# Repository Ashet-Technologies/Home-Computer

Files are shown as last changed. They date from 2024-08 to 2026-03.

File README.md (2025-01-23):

# Ashet Home Computer Mk4

### _The 21st century home computer_

| Project Status                                                                                       |
|------------------------------------------------------------------------------------------------------|
| ⚠️ **WORK IN PROGRESS** ⚠️                                                                             |
| This README reflects the state of where the project wants to go, not where the project is right now! |

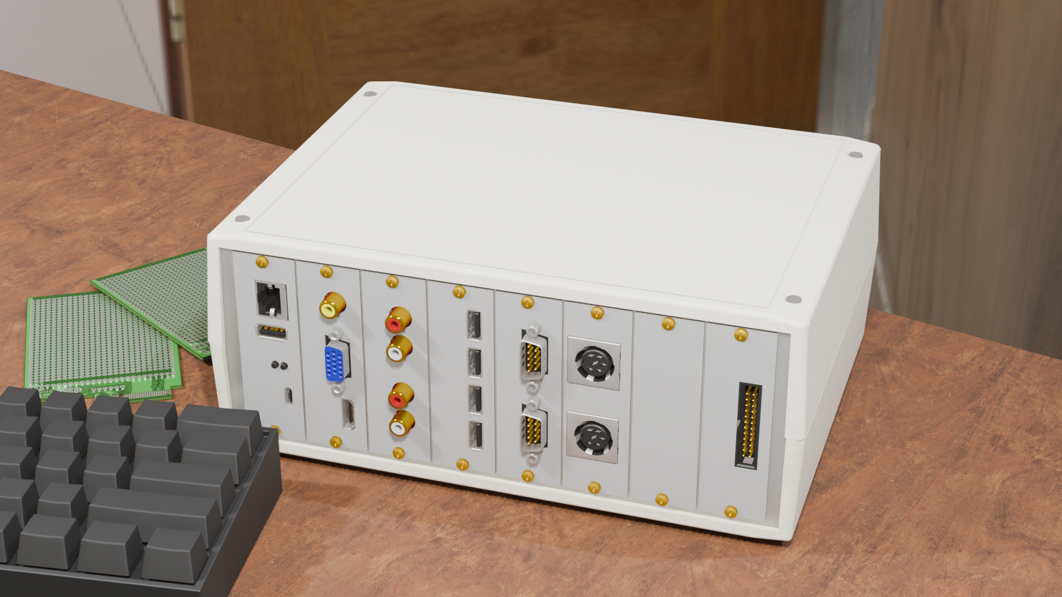
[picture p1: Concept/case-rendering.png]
A rendering of a concept art


## Introduction

The Ashet Home Computer bridges the gap between simple microcontroller development boards and modern single-board computers, offering the processing capability to run a full graphical desktop OS while maintaining the hardware accessibility of simpler systems.

Built around the RP2350 dual-core processor, it combines sufficient computational power for a modern user interface with a transparent, education-oriented architecture. The modular expansion system, inspired by classic computer designs, allows direct hardware access while providing proper driver abstractions for portability.

Key differentiators:

- Runs [Ashet OS](https://github.com/Ashet-Technologies/Ashet-OS): A custom desktop operating system with modern GUI capabilities
- Fully documented hardware architecture with direct register access
- Modular expansion through 7 dedicated slots, including specialized video/audio interfaces
- 8 MB RAM and 16 MB Flash supporting both low-level and high-level development
- Comprehensive I/O capabilities suitable for real-time interfacing, creative projects, and systems development

The system is designed for accessibility across different skill levels - from students learning computer architecture to makers building custom hardware interfaces, and from demosceners pushing hardware limits to educators teaching system design.

## Features

The computer follows a modular design similar to a PC where you have expansion cards that you can plug into the system.

### Core Features

These features are available no matter what expansion cards you have installed.

- RP2350 Core
  - Dual-Core System
  - Each Core Might Be
    - Arm CPU (Cortex-M33, 150 MHz)
    - RISC-V CPU (RV32IMAC+, 150 MHz)
- 8 MB RAM
- 16 MB Flash
- USB 1.1 Host
- 10/100 Mbps Ethernet
- Battery-Backed Real-Time Clock
- Status Display (128x64, monochrome)
- Integrated Debug Probe
- 7 Expansion Slots
  - 1 Video Expansion Slot
  - 1 Audio Expansion Slot
  - 5 Generic Expansion Slots

### Standard Expansions

The following expansion cards are the designated expansion cards which make up the Ashet Home Computer as designed:

1. [Framebuffer Video Card](Hardware/Expansions/Framebuffer%20Video/README.md)
    - DVI Video Out (800x480, 60 Hz)
2. [PCM Sound Card](Hardware/Expansions/PCM%20Sound/README.md)
    - PCM Audio Out (48 kHz, 16 bit)
    - PCM Audio In (48 kHz, 16 bit)
3. [USB Card](Hardware/Expansions/USB/README.md)
    - 4 USB 1.1 Host Ports
4. [RS232 Card](Hardware/Expansions/RS232/README.md)
    - TTL UART (3.3V, 5V, ±12V)
5. [Basic I/O Card](Hardware/Expansions/Basic%20IO/README.md)
    - Pin Header Connector
    - 8 GPIOs
    - Dedicated I²C
    - 5 V and 3.3 V power supply available
6. [Commodore Connectivity Card](Hardware/Expansions/Commodore%20Connectivity/README.md)
    - 2× C64 Serial
7. [User Expansion Card](Hardware/Expansions/User%20Expansion/README.md)
    - Minimal Expansion Card
    - Perfboard For Custom Expansions
    - Pin Header Connector

### Other Expansions

There are many more ideas that can be realized with expansion cards.

Take a peek at our [List of Expansion Board Ideas](Concept/Expansion%20Boards.md) or check out the [Expansion Card Interface Specification](Specs/Expansion%20Bus.md) how to create your own.

## Use Cases

This chapter contains a list of things you can do with the computer, ordered loosely by user groups.

### Demosceners

Make a demo, I guess?

With a good audio and video expansion card, and two strong multi-core CPUs the computer packs enough power to create awesome visuals and sound effects.

### Retro-Enthusiasts

The computer is able to emulate a lot of existing machines with fitting I/O connectivity. The backplane is able to emulate a lot of different protocols with cheap passive expansion modules.

It also is able to create a multitude of video signals, analog and digital with 15 or 30 kHz line frequency. Another option is to have more complex expansion cards which can drive storage interfaces like [Shugart bus](https://en.wikipedia.org/wiki/Floppy_disk_drive_interface), [MFM disks](https://en.wikipedia.org/wiki/Modified_frequency_modulation), ATA and IDE…

### Artists / Musicians

The Ashet can be used as a cheap real-time sequencing controller which can handle a good amount of interfaces. With support for MIDI, DMX, analog audio channels and ethernet, it's possible to create complex audio setups. Another option is creating or using expansion cards that provide access to old-school synthesizers like the [AY-3-8910](https://en.wikipedia.org/wiki/General_Instrument_AY-3-8910) or the [SID](https://en.wikipedia.org/wiki/MOS_Technology_6581).

### Hackers / Makers

With the Propeller 2 on the backplane, one can basically emulate any digital interface like SPI or I²C. With a breakout I/O expansion card, it can be used for controlling your own hardware, accessing and changing SPI flashes, ...

It is also possible to use the Ashet as a basic logic analyzer and scope, as well as a signal and waveform generator. With a bigger I/O card, it can be expanded to 32 synchronously processed channels.

By utilizing a scripting language on Ashet OS, one should be able to easily access and bootstrap newly acquired hardware.

### Educators

The project provides extensive documentation, from decision making over the schematic up to the software architecture, so it can be used as an example on how to design a complete computer system.

The machine also looks more like a "real computer" than a Raspberry Pi or other modern single-board computers, so it is more tangible for persons that do not have experience with electronics and might give an easier start.

### Students

The computer provides a good hands-on experience and allows both creating or understanding hardware and software designs and how they play together. The system is also easily expansible and thus allows creating custom hardware modules. The available documentation allows learning basically everything about the computer that is possible to know.

## Comparison with Similar Projects

The following table shows a comparison to other "small" computers. It should help you get an idea where the Ashet Home Computer is in relation to other projects.

| Feature | Ashet | [Raspberry Pi 4](https://www.raspberrypi.com/products/raspberry-pi-4-model-b/specifications/) | [Arduino Uno REV3](https://store.arduino.cc/products/arduino-uno-rev3) | [Neotron Pico](https://github.com/neotron-Compute/neotron-Pico) | [Cody Computer](https://www.codycomputer.org/) |
|---|---|---|---|---|---|
| CPU Architecture | Arm Cortex-M33 (32 bit) | Arm Cortex-A72 (64 bit) | ATmega328p (8 bit) | Arm Cortex-M0+ (32 bit) | 6502 |
| CPU Model | [Rapsberry Pi RP2350](https://www.raspberrypi.com/products/rp2350/) | [Broadcom BCM2711](https://www.raspberrypi.com/documentation/computers/processors.html#bcm2711) | [ATmega328P](https://www.microchip.com/en-us/product/atmega328p) | [Rapsberry Pi RP2040](https://www.raspberrypi.com/products/rp2040/) | [W65C02S](https://wdc65xx.com/integrated-circuit) |
| CPU Cores | 2 | 4 | 1 | 2 | 1 |
| CPU Clock | 150 MHz | 1.8 GHz | 16 MHz | 133 MHz | 1 MHz |
| System Memory | 8 MB | 1, 2, 4 or 8 GB | 2 KB | 264 kB | 64 kB |
| Understandable | ✅ | ❌ | ✅ | ✅ | ✅ |
| Modern I/O | ✅ | ✅ | ❌ | ❌¹ | ❌ |
| Modular Design | ✅ | ❌ | ❌ | ✅ | ✅² |
| Full Documentation Available | ✅ | ❌ | ✅ | ✅ | ✅ |
| Ethernet | ✅ | ✅ | ❌ | ❌ | ❌ |
| Parallax Propeller I/O Chip  | ✅ ([Propeller 2](https://www.parallax.com/propeller-2)) | ❌ | ❌ | ❌ | ✅ ([Propeller 1](https://www.parallax.com/propeller-1)) |

¹Neotron Pico uses PS/2 for mouse/keyboard and VGA for video.

²Cody Computer has a single cartridge that can be added.

## Architecture

### Block Diagram

Block Diagram

## Glossary

<dl>
  <dt>Mainboard</dt>
  <dd>The Mainboard houses the cpu core and everything necessary to run the system, even without <em>Expansion Boards</em> or the <em>Backplane</em>.</dd>

  <dt>Backplane</dt>
  <dd>The Backplane is the interconnect between the <em>Mainboard</em> and <em>Expansion Boards</em>. This board also contains the <em>I/O Southbridge</em></dd>

  <dt>Expansion Board</dt>
  <dd>Expansion Boards provide more capabilities to the computer. They usually add more I/O features, but could also house any other kind of electronics that want to interface with the <em>Mainboard</em>.</dd>

  <dt>Video Expansion Board</dt>
  <dd>A Video Expansion Board is a special expansion that is only installable in a single socket of the <em>Backplane</em>. In addition to the generic <em>Expansion Board</em> interface, it has an additional 8 lanes of high-speed interconnect to the <em>Mainboard</em>.</dd>

  <dt>Audio Expansion</dt>
  <dd>An Audio Expansion Board is a special expansion that is only installable in a single socket of the <em>Backplane</em>. In addition to the generic <em>Expansion Board</em> interface, it has an additional 2-lane I²S interconnect to the <em>Mainboard</em>.</dd>

  <dt>I/O Southbridge</dt>
  <dd>The I/O Southbridge provides the main interconnect between the <em>Main Board</em> and the <em>Expansion Boards</em>. It is realized by a <a href="https://www.parallax.com/propeller-2/">Propeller 2</a>.</dd>
</dl>

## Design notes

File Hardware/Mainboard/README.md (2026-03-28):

# Ashet Home Computer Mainboard

## Overview

- RP2350B as main CPU
- RP2350B as a debug probe
- Two 16 MiB flash chips
- 12 MHz Crystal for debug probe
- 4-port USB 1.1 HUB
- 10/100 Base-T/TX ethernet through ENC424J600
- 8 MB PSRAM (APS6404L-SQH-SN)
- 1.8V LDO for QSPI_IOVDD / PSRAM / Flash Chips

## Design Notes

- Attach debug probe to global I²S bus for both sniffing and controlling the system
- Debug probe must be able to reset the main CPU
- Debug probe can additionally drive global CLOCK_48MHZ so we can run the mainboard standalone without backplane
- Drive main CPU from CLOCK_48MHZ
- Drive debug probe through dedicated crystal
- Evaluate if debug probe can trigger the main cpu "boot over serial"
- Attach debug probe to main cpu flash directly
- Main CPU cannot be programmed through USB/UF2, but only through the debug probe
  - This must be as convenient as possible

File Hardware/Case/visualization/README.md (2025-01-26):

# Visualization Rendering

This case contains the nice "preview" renderings of the device.

## Utilities

- <https://github.com/30350n/pcb2blender>
- <https://extensions.blender.org/add-ons/pcb3d-importer>

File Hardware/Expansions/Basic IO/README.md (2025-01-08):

# Basic I/O Expansion

This expansion board just forwards the expansion connector to a 0.1" pin header.

## Pinout

The I/O card has a 0.1" pin header connector with 12x2 pins on the frontplate with the following pinout:

| Column | Top | Bottom  |
|---|---|---|
| 1 (left) | 5V | GND |
| 2 | 3V3 | GND |
| 3 | I2C_SCL | I2C_SDA |
| 4 | GP0 | GND |
| 5 | GP1 | GND |
| 6 | GP2 | GND |
| 7 | GP3 | GND |
| 8 | GP4 | GND |
| 9 | GP5 | GND |
| 10 | GP6 | GND |
| 11 | GP7 | GND |
| 12 (right) | GND | GND |

## Parts

| Function | Manufacturer | Part Number | Distributors |
|---|---|---|---|
| 0.1" Connector with 12x2 | On Shore Technology Inc. | 302-R241 | [DigiKey](https://www.digikey.de/de/products/detail/on-shore-technology-inc/302-R241/2794248) |

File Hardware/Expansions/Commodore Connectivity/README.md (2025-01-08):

# Commodore Connectivity Expansion

The Commodore Connectivity Expansion provides two [C64 Serial](https://www.c64-wiki.com/wiki/Serial_Port) compatible DIN connectors.

Each connector is it's own dedicated bus and they are not connected internally. This way two devices can be operated independently from each other.

## Pinout

The pinout of the two DIN connectors is the same as on the C64 or other compatible devices:

| Pin | Name | Signal direction | Remark |
|-----|---|---|---|
| 1 | SERIAL SRQ | in | Serial Service Request In, at the C128 "Fast Serial Clock" |
| 2 | GND | - | Ground, signal ground (0V) |
| 3 | SERIAL ATN | out | Attention, for the selection of a device at beginning/end of a transmission |
| 4 | SERIAL CLK | in/out | Clock (for data transmission) |
| 5 | SERIAL DATA  | in/out | Data |
| 6 | SERIAL RESET | out(/in) | Reset, in older VIC-20 unused |

## Parts

| Function | Manufacturer | Part Number | Distributors |
|---|---|---|---|
| DIN 45322 Connector | CLIFF Electronic Components Ltd | FM6726 | [DigiKey](https://www.digikey.de/de/products/detail/cliff-electronic-components-ltd/FM6726/21676225) |
| 16 bit I/O Expander | Microchip Technology | MCP23S17T-E/SO | [DigiKey](https://www.digikey.de/de/products/detail/microchip-technology/MCP23S17T-E-SO/964187) |

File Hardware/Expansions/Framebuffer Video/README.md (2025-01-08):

# Framebuffer Video Expansion

The Framebuffer Video Expansion is the most simple video expansion.
It only provides a single DVI-compatible connector connected to the Mainboard.

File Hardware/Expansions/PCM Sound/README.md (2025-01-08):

# PCM Sound Expansion

The PCM Sound Expansion provides both a stereo audio input as well as a stereo output on a Cinch/RCA connector.

Both the input and the output support at least 16 bit audio with 48 kHz sampling frequency and DC free audio output.

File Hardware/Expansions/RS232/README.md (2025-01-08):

# RS232 Expansion

The RS232 expansion provides two fully equipped [RS232](https://en.wikipedia.org/wiki/RS-232) ports.

Each port has the serial lanes as well as all control signals available.

## Pinout

The pinout of the two SUB DE 9 connectors follow the RS232 standard:

| Pin | Name | Signal direction | Remark |
|-----|---|---|---|
| 1 | DCD  | in | (Data) Carrier Detect |
| 2 | RXD  | in | Receive Data |
| 3 | TXD  | out | Transmit Data |
| 4 | DTR  | out | Data Terminal Ready |
| 5 | GND  | - | Signal Ground |
| 6 | DSR  | in | Data Set Ready |
| 7 | RTS  | out | Request To Send |
| 8 | CTS  | in | Clear To Send |
| 9 | RI | in | Ring Indicator |

## Parts

| Function | Manufacturer | Part Number | Distributors |
|---|---|---|---|
| RS232 Transceiver | Texas Instruments | MAX3243EIPWR | [DigiKey](https://www.digikey.de/de/products/detail/texas-instruments/MAX3243EIPWR/1120503) |
| 16 bit I/O Expander | Microchip Technology | MCP23S17T-E/SO | [DigiKey](https://www.digikey.de/de/products/detail/microchip-technology/MCP23S17T-E-SO/964187) |
| SUB DE 9 Male Connector | Assmann WSW Components | A-DS 09 A/KG-T4S | [DigiKey](https://www.digikey.de/de/products/detail/assmann-wsw-components/A-DS-09-A-KG-T4S/1241806) |

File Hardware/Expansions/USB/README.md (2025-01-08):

# USB Expansion

The USB Expansion provides 4 USB 1.1 ports to the computer which are attached to the backplane.

## Pinout

| Pin | Name | Signal direction | Remark |
|-----|---|---|---|
| 1 | GND  | - | Signal ground |
| 2 | D+ | in/out | Positive data lane |
| 3 | D- | in/out | Negative data lane |
| 4 | VBUS | - | 5V |

## Parts

| Function | Manufacturer | Part Number | Distributors |
|---|---|---|---|
| USB-A Connector | Cvilux USA | CU01SAH0S00 | [DigiKey](https://www.digikey.de/de/products/detail/cvilux-usa/CU01SAH0S00/13177442) |

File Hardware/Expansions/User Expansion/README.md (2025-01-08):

# User Expansion

This expansion card allows one to create their own expansions.

It contains all necessary parts like the connector and the metadata EEPROM, but apart from that, it just exposes all signals onto a perfboard.

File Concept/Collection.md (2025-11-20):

# Link Collection

## Parts

- [RP2350 Stamp XL](https://www.lectronz.com/products/rp2350-stamp-xl) ([Documentation](https://www.solder.party/docs/rp2350-stamp-xl/))
- [ENC624J600](https://www.microchip.com/en-us/product/enc624j600)
- [ESP32-C3](https://www.espressif.com/en/products/socs/esp32-c3)
- [FT232H](https://ftdichip.com/products/ft232hq/)
- [Parallax Propeller 2](https://www.parallax.com/propeller-2/)
- [XS3A2467PWJ](https://www.digikey.de/de/products/detail/nexperia-usa-inc/XS3A2467PWJ/16186760) (Dual low-ohmic double-pole double-throw analog switch)

## Prototyping

### Debugger

- [https://ftdichip.com/products/ft232hq/]
- [BlackMagic Probe](https://github.com/koendv/blackmagic-firmware/blob/master/INSTALL.md)
- [RaspberryPi Debug Probe](https://www.raspberrypi.com/products/debug-probe/)

### Devboards

- [RaspberryPi Pico 2](https://www.raspberrypi.com/products/raspberry-pi-pico-2/)
- [MOD-ENC624J600](https://www.olimex.com/Products/Modules/Ethernet/MOD-ENC624J600/)
- [ESP32-C3 Zero](https://www.waveshare.com/esp32-c3-zero.htm)
- [FT232H](https://www.adafruit.com/product/2264)

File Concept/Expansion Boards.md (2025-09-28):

# List of Expansion Board Ideas

## Near Future

- WiFi via ESP32-C3
- 32 Channel I/O via Propeller 2
- PropGPU (Propeller 2 based GPU with 4-16 MB video ram, HDMI, VGA, CVBS)
- SuperSound (I²S PCM + AY-3-8910 + Analog Mixer)
- Dual C64 Serial
- Quad-Channel D-Bus-Controller (TI Calculator Link)
- SD Card Expansion (USB2244-AEZG-06)
- 100BASE-T1 (https://www.mouser.de/datasheet/2/268/LAN8770_Product_Brief_DS00002550C-3071247.pdf)

## Far Future

- Quad-Channel DMX
- Dual-Channel MIDI
- Parallel Port
- Retro Joystick (SUB-D 9, C64, Atari, ...)
- VLSI Video Card (<https://www.vlsi.fi/en/products/vs23s040.html>)
- VLSI Audio Card (<https://www.vlsi.fi/en/products/vs1053.html>)
- RaspberryPi Compute Module carrier ("SuperCPU")

## Community

- Analog Video Capture Card
- GPIB
- Ethernet with BNC
- Tokenring
- MFM Disk
- PS/2
- Commodore Datasette
- [Shugart Bus](https://en.wikipedia.org/wiki/Floppy_disk_drive_interface) Floppy Driver
- TOSLINK for Communications Network
- Wireless Multi-Channel Device (LoRa, Bluetooth, Matter, ...)
- EtherCAT
- Sercos III
- [CAN FD](https://en.wikipedia.org/wiki/CAN_FD)
- [IO Link](https://en.wikipedia.org/wiki/IO-Link)
- [HART](https://en.wikipedia.org/wiki/Highway_Addressable_Remote_Transducer_Protocol)

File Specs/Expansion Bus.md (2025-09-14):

# Ashet Expansion Bus

The Ashet *Expansion Bus* is the core component of the composability of the Ashet Home Computer.

## Overview

- Hot Swappable
- Power Supply
  - 12V, (up to) 2A
  - 5V, (up to) 1A
  - 3.3V, (up to) 1A
  - Overcurrent Protection
- Standard Mode I²C Bus
- 8 Programmable I/O Pins
- 8 High Speed Lanes (up to 300 MHz)
- Dual-Stream I²S Bus

## Optional Features

The Expansion Bus has several *optional* features that must not be present on each slot.

Each feature might require a certain set of signals to be present:

| Feature  | Standard Signals | Video Signals | Audio Signals |
| --- | --- | --- | --- |
| Standard | ✅ | ❌ | ❌ |
| Audio | ✅ | ❌ | ✅ |
| Video | ✅ | ✅ | ❌ |

## Signals

| Signal Name | Driver | Type | Function | Frequency Limit |
| --- | --- | --- | --- | --- |
| *All Variants* | | | | |
| `GND` | Backplane | Power | Signal Ground | |
| `+3V3` | Backplane | Power | 3.3 V power supply | |
| `+5V` | Backplane | Power | 5 V power supply | |
| `+12V` | Backplane | Power | 12 V power supply | |
| `/PDET` | Card | Static | Presence detection. Must be tied to ground on the expansion card | |
| `SLOT_A0`...`SLOT_A3` | Backplane | Static | Module slot index, bits 0 to 3 | |
| `/SLOT_AUDIO` | Backplane | Static | This signal is connected to GND if the slot has the *Audio* feature available | |
| `/SLOT_VIDEO` | Backplane | Static | This signal is connected to GND if the slot has the *Video* feature available | |
| `/IRQ` | Card | Open Collector | Interrupt request. Card drives this to low for system notification | |
| `/RESET` | Backplane | Logic | Reset signal. Is driven low when the card should reset itself | |
| `CLK` | Backplane | Logic | Global 8 MHz clock for synchronization | 8 MHz |
| `I2C_SCL` | Bi-di | Open Collector | Clock Lane of the System I²C Bus | 100 kHz |
| `I2C_SDA` | Bi-di | Open Collector | Data Lane of the System I²C Bus | 100 kHz |
| `GP0`...`GP7` | Bi-di | Logic or Analog | General-purpose I/O signals from the Southbridge | 150 MHz |
| *Video Signals* | | | | |
| `HSTX0`...`HSTX7` | Backplane | Logic or Differential | Unidirectional high-speed lanes. Even/odd pairs for a differential pair | 300 MHz |
| *Audio Signals* | | | | |
| `I2S_MCLK` | Backplane | Logic | Master clock of both I²S streams | 25 MHz |
| `I2S_BCLK` | Backplane | Logic | Bit clock of both I²S streams | 6.5 MHz |
| `I2S_WCLK` | Backplane | Logic | Word clock of both I²S streams | 192 kHz |
| `I2S_SDIN` | Card | Logic | Data lane of the I²S input stream | 6.5 MHz |
| `I2S_SDOUT` | Backplane | Logic | Data lane of the I²S output stream | 6.5 MHz |

All signals that are not power signals will use nominal voltage levels between 0.0V and 3.3V.

### Power

> TO BE DONE

### I²C

The I²C bus uses standard speed I²C and must have at least a standard EEPROM connected.

This EEPROM must have at an 8-bit memory organization with at least 8K of memory. It contains the *Module Descriptor Data* described further below.

The following addresses are reserved on the bus in addition to the specification:

| Address | Use |
| ---: | --- |
| 0x57 | Metadata EEPROM |
| 0x70 | Backplane I²C Switch |

All other addresses on the I²C bus are available to the expansion card and will not be occupied by the host system.

> **LORE:**
> The *Metadata EEPROM* uses the address `0x57` instead of `0x50`, as `0x50` is the default for EEPROMs and these might already be taken by other
> EEPROM systems like the [DDC](https://en.wikipedia.org/wiki/Display_Data_Channel) [EDID](https://en.wikipedia.org/wiki/Extended_Display_Identification_Data) EEPROM.

### General Purpose I/O

These signals will have a card-specific function and are driven by either the card or the southbridge on the backplane.

They can be either logic signals or analog signals, as long as they stay in the nominal voltage range.

Each expansion card will have to ship a low level driver which provides the southbridge configuration for these I/Os. See *Module Descriptor Data* for more information.

### I²S

The I²S bus has two audio streams on the signals `I2S_SDIN` and `I2S_SDOUT`.

`I2S_SDOUT` contains the left and right channel data of a stereo audio output, while `I2S_SDIN` contains the left and right channel data of a stereo capturing device.

The clock signals are shared for both audio streams and are always driven by the host system. This means that the sample rate is defined by the host and cannot be set by the card itself.

Cards that need to be in control of their sample rate might need to do audio resampling or use the *General Purpose I/O* signals.

It is only available on slots with the *Audio* signal set.

### High Speed Lanes

> TO BE DONE

The high speed lanes are only available on slots with the *Video* signal set.

## Connector

### Mechanical

The *Expansion Bus* uses a standard *PCI Express x4* connector with 64 positions.

### Pinout

|  Pin | A Side | B Side |
| ---: | --- | --- |
| 1 | GND | GND |
| 2 | +3V3 | +12V |
| 3 | +3V3 | +12V |
| 4 | GND | +12V |
| 5 | SLOT_A0 | +12V |
| 6 | SLOT_A1 | +5V |
| 7 | SLOT_A2 | +5V |
| 8 | SLOT_A3 | GND |
| 9 | I2C_SCL | /PDET |
| 10 | I2C_SDA | /SLOT_AUDIO |
| 11 | /IRQ | /SLOT_VIDEO |
|  Key | - | - |
| 12 | GND | GND |
| 13 | CLK | HSTX0 |
| 14 | GND | HSTX1 |
| 15 | GP0 | GND |
| 16 | GP1 | HSTX2 |
| 17 | GP2 | HSTX3 |
| 18 | GP3 | GND |
| 19 | GP4 | HSTX4 |
| 20 | GP5 | HSTX5 |
| 21 | GP6 | GND |
| 22 | GP7 | HSTX6 |
| 23 | *reserved* | HSTX7 |
| 24 | *reserved* | GND |
| 25 | *reserved* | I2S_MCLK |
| 26 | *reserved* | GND |
| 27 | *reserved* | I2S_BCLK |
| 28 | *reserved* | I2S_WCLK |
| 29 | *reserved* | GND |
| 30 | *reserved* | I2S_SDIN |
| 31 | /RESET | I2S_SDOUT |
| 32 | GND | GND |

## Module Descriptor Data

The Module Descriptor Data describes the expansion card and provides a low-level driver for the southbridge.

### Memory Map

The data is located at the start of the EEPROM and follows the following memory layout:

| Address Range  | Function |
| --- | --- |
| `0000`..`01FF` | Metadata Block |
| `0200`..`07FF` | *reserved* |
| `0800`..`0FFF` | Module Card Icon |
| `1000`..`1FFF` | Low Level Driver Binary |

### Metadata Block

The metadata block encodes generic information about the expansion card that can be processed by the host system.

| Offset | Field | Type | Function |
| --- | --- | --- | --- |
| `0000` | Vendor ID | `u32` | Unique ID for the vendor of the expansion card |
| `0004` | Product ID | `u32` | Vendor-unique ID for the expansion card |
| `0008` | Serial Number | `[8]u8`  | Serial number of the expansion card. Can be zero-padded |
| `0018` | | | *padding* |
| `0020` | Required Features | `u8` | Bitmask of which expansion slot features are required |
| `0021` | | | *padding* |
| `0024` | Driver Interface  | `u32` | Type of driver interface this expansion card uses |
| `0028` | | | *padding* |
| `0030` | Driver Specific | `[16]u8` | |
| `0040` | | | *padding* |
| `0100` | Vendor Name | `[64]u8` | UTF-8 encoded vendor name |
| `0140` | Product Name | `[64]u8` | UTF-8 encoded product name |
| `0180` | | | *padding* |

### Module Card Icon

Each module card may embed an icon so a host os can show the user a nice visual representation.

As the resolution of the host system is not known, up to three icon sizes can be embedded:

- 16x16
- 24x24
- 32x32

All icons share the same color palette, which can have up to 63 colors and a transparency key.

The icon memory block is organized as such:

| Address Range  | Function |
| --- | --- |
| `0000`..`00FF` | 8-bit pixel data for 16x16 icon |
| `0100`..`04FF` | 8-bit pixel data for 32x32 icon |
| `0500`..`0BFF` | 8-bit pixel data for 24x24 icon |
| `0740` | 16x16 icon Configuration Field |
| `0741` | 32x32 icon Configuration Field |
| `0742` | 24x24 icon Configuration Field |
| `0743`..`07FF` | 63-entry palette with \[R,G,B] color values |

Each *Configuration Field* is a bit field with the following items:

|  Bit | Function |
| ---: | --- |
| 0..5 | Number of palette entries. Zero means icon is disabled |
| 6..7 | *reserved, must be zero* |

An icon is present if it has more than zero colors in its palette.

The pixel data contains row-major organized indices into the palette using 0...62 as defined by the palette table, and 63 as the transparency key. On load, the uppermost two bits may be discarded, truncating the 8-bit index to 6 bits.

### Low Level Driver

The low level driver is a Propeller 2 binary which is loaded into one of the cogs of the southbridge.

> TO BE DONE

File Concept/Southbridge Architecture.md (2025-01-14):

# Southbridge Architecture

## tl;dr

- Propeller2 based
- Support for 7 expansion slots
  - 1 cog per slot
  - 64k RAM per slot
- 1 cog upstream
- 64k management ram + code

## Interface

### Physical

> TBD

### Electrical

| Interface Pin | Propeller Pin | Name | Direction  | Idle State | Function | Alt. Function |
| ---: | --- | --- | --- | --- | --- | --- |
| 1 | 53 | D0 | Bi-di | Don't care | Data bit, L=0, H=1 | - |
| 2 | 57 | D1 | Bi-di | Don't care | Data bit, L=0, H=1 | - |
| 3 | 58 | D2 | Bi-di | Don't care | Data bit, L=0, H=1 | - |
| 4 | 59 | D3 | Bi-di | Don't care | Data bit, L=0, H=1 | Forced HIGH |
| 5 | 60 | CLK | Bi-di | High | The bit clock for D0, D1, D2, D3. Shift in on rising edge | *don't care*  |
| 6 | 61 | EN | Downstream | Low | Determines if a transfer is active. On a rising edge, a new transfer is started | *don't care*  |
| 7 | 62 | DIR | Downstream | Low | The direction of a transfer. H means towards Downstream, L is towards Upstream | Boot RX |
| 8 | 63 | /REQ | Upstream | High | A falling edge will signal the upstream that an event happened and data is ready to be read | Boot TX |
| 9 | RESn | /RESET | Downstream | High | Resets the southbridge into initial state | |

Upstream: Southbridge to Host CPU

Downstream: Host CPU to Southbridge

### Logical

The protocol is transfer-oriented with each transfer being made of a sequence of octets.

A transfer is initiated by the upstream setting `DIR` to the desired state, then pulling the `EN` pin to high. The rising edge is detected on the downstream which then samples the `DIR` pin.

Depending on `DIR`, either a *write* or a *read* operation is performed. For *write* operations, the upstream is the driver for `CLK` and the data pins, on a *read* operation, the downstream drives these signals.

After the transfer setup has been done, pairs of nibbles are transferred. For each nibble, the sender will set up the data pins and pull `CLK` low, afterwards pulling `CLK` high.
The data must sampled by the receiver on the rising edge of the `CLK` signal. The first transferred nibble contains the upper 4 bit of the octet, the second one contanis the lower 4 bit.

A transfer is completed on a falling edge of `EN`. `DIR` should remain constant throughout the transfer, but only the state after the rising edge of `EN` defines the transfer direction.

The `/REQ` signal shall be pulled low by the downstream as long as it has pending outgoing requests. It must be cleared after a rising edge of `EN` when `DIR=H`, but can be enabled again as soon as `EN=L` when another transfer is ready or the previous transfer was not completed.

### Protocol

The protocol has two participants:

- Host (the RP2350)
- Device (the Southbridge)

Each participant can send messages at any time and the sequence isn't necessarily in-order and "ping pong" style.

Both parts send messages using this format:

```bfdl
struct Message
{
  type:            u8,
  length:          u8,
  payload: [length]u8,
  crc:             u16,
};
```

The `payload` contains the data for `type`, which is a direction-dependent command.

#### Host Messages

These messages are sent by the host to the device.

The following messages are allowed:

| `type` | Message Name | Short Description |
| --- | --- | --- |
| 0 | Write Memory | Writes bytes into hub memory. |
| 1 | Read Memory | Reads bytes from hub memory. |
| 2 | Start Slot | Starts the cog for a slot. |
| 3 | Stop Slot | Stops the cog for a slot. |
| 4 | Write To FIFO | Writes to the output FIFO for a slot. |
| 5 | Request From FIFO | Requests that the device sends remaining data from a FIFO. |
| 6 | Configure Input FIFO | Configures FIFO behaviour. |
| 7 | Acknowledge IRQ | Clears the IRQ flag for configured slots. |

##### Write Memory

```bfdl
struct Payload
{
  address: u32,
  payload: [*]u8,
};
```

##### Read Memory

```bfdl
struct Payload
{
  address: u32,
  length: u32,
};
```

##### Start Slot

```bfdl
struct Payload
{
  slot_id: u8, // 0..6
};
```

##### Stop Slot

```bfdl
struct Payload
{
  slot_id: u8, // 0..6
};
```

##### Write To FIFO

```bfdl
struct Payload
{
  fifo: u4,
  slot: u4,
  data: [*]u8,
};
```

##### Request From FIFO

```bfdl
struct Payload
{
  fifo: u4,
  slot: u4,
  max_length: u16, // Max number of bytes from FIFO
};
```

##### Configure Input FIFO

```bfdl
struct Payload
{
  fifo: u4,
  slot: u4,
  threshold: u16, // Minimum number of data bytes in FIFO before auto-flushing. 0 is disabled.
};
```

##### Acknowledge IRQ

```bfdl
struct Payload
{
  ack_mask: u8,
};
```

#### Device Messages

These messages are sent by the device to the host.

The following messages are allowed:

| `type` | Message Name | Short Description |
| --- | --- | --- |
| 0 | Status | Contains system status, is sent periodically and on changes. |
| 1 | Memory Content | Data from hub memory, is response to "Read Memory". |
| 2 | Data From FIFO | Data from an in input FIFO has data. |
| 3 | Cog Started | A cog has successfully started. |

##### Status

```bfdl
struct Payload
{
  slot_mask:          u8, // which slots are active
  irq_mask:           u8,  // which slots have IRQs pending
  fifo_cnt:           u8,  // number of non-empty FIFOs
  fifos:    [fifo_cnt]FIFO_Status,
};

struct FIFO_Status
{
  fifo: u4,
  slot: u4,
  level: u16,
};
```

##### Memory Content

```bfdl
struct Payload
{
  address:    u32,
  data:    [*]u8,
};
```

##### Data From FIFO

```bfdl
struct Payload
{
  fifo:    u4,
  slot:    u4,
  data: [*]u8,
};
```

##### Cog Started

```bfdl
struct Payload
{
  cog_id: u8,
  input_fifo_mask: u16,
  output_fifo_mask: u16,
};
```

## Memory Map

| Address Range | Size  | Function |
| --- | ----- | --- |
| `00000`..`007FF` | 2048  | Control Core Code |
| `00800`..`00FFF` | 2048  | Control Core Data |
| `01000`..`017FF` | 2048  | Slot 1 Code |
| `01800`..`01FFF` | 2048  | Slot 1 Config |
| `02000`..`027FF` | 2048  | Slot 2 Code |
| `02800`..`02FFF` | 2048  | Slot 2 Config |
| `03000`..`037FF` | 2048  | Slot 3 Code |
| `03800`..`03FFF` | 2048  | Slot 3 Config |
| `04000`..`047FF` | 2048  | Slot 4 Code |
| `04800`..`04FFF` | 2048  | Slot 4 Config |
| `05000`..`057FF` | 2048  | Slot 5 Code |
| `05800`..`05FFF` | 2048  | Slot 5 Config |
| `06000`..`067FF` | 2048  | Slot 6 Code |
| `06800`..`06FFF` | 2048  | Slot 6 Config |
| `07000`..`077FF` | 2048  | Slot 7 Code |
| `07800`..`07FFF` | 2048  | Slot 7 Config |
| `10000`..`1FFFF` | 65536 | Slot 1 RAM |
| `20000`..`2FFFF` | 65536 | Slot 2 RAM |
| `30000`..`3FFFF` | 65536 | Slot 3 RAM |
| `40000`..`4FFFF` | 65536 | Slot 4 RAM |
| `50000`..`5FFFF` | 65536 | Slot 5 RAM |
| `60000`..`6FFFF` | 65536 | Slot 6 RAM |
| `70000`..`7FFFF` | 65536 | Slot 7 RAM |

### Slot RAM

Each slot RAM can be configured as 16 parts, which can be:

- RAM / Registers
- Input FIFO, which can send data to the host
- Output FIFO, which can receive data from the host

The memory map for the slot ram looks like this:

| Address Range | Size |
| --- | ---- |
| `x0000`..`x0FFF` | 4096 |
| `x1000`..`x1FFF` | 4096 |
| `x2000`..`x2FFF` | 4096 |
| `x3000`..`x3FFF` | 4096 |
| `x4000`..`x4FFF` | 4096 |
| `x5000`..`x5FFF` | 4096 |
| `x6000`..`x6FFF` | 4096 |
| `x7000`..`x7FFF` | 4096 |
| `x8000`..`x8FFF` | 4096 |
| `x9000`..`x9FFF` | 4096 |
| `xA000`..`xAFFF` | 4096 |
| `xB000`..`xBFFF` | 4096 |
| `xC000`..`xCFFF` | 4096 |
| `xD000`..`xDFFF` | 4096 |
| `xE000`..`xEFFF` | 4096 |
| `xF000`..`xFFFF` | 4096 |

There are up to 8 input and 8 output FIFOs. Each slot can be assigned one of these functions.

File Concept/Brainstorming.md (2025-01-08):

# Brainstorming

## Global Clock Source

Original Idea: Spread 16 MHz

Required Frequencies:

- 48 MHz for USB 1.1
- 26.136 .. 29.5 MHz RGB Signal (800x480 @ 60 Hz)
- 4.43 MHz PAL Signal
- 150 MHz RP2350
- 300 MHz Propeller 2
- 48 kHz Audio Sample Rate
- 1.536 MHz Audio Bit Rate

No oscillator with 16 MHz on DigiKey

Multiplier Table:

| Frequency | 8 MHz |
|---|---|
| 48 kHz | 0.006 |
| 1.536 MHz | 0.192 |
| 4.43 MHz  | 0.55375 |
| 29.5 MHz  | 3.6875  |
| 48 MHz | 6 |
| 150 MHz | 18.75 |
| 300 MHz | 37.5 |

## Expansion Required Parts

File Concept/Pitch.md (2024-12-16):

# Ashet Home Computer Pitch

> **Ashet Home Computer** - _The 21st century home computer_

what if i told you, there's a 2024 Home Computer available (less than 200€), which has

- 16 MB RAM
- 7 expansion slots, one with audio capabilities, one with video capabilities
- default audio module with stereo input/output
- default video module with HDMI output up to 800x480
- a collection of available expansion modules
  - Serial Ports
  - WiFi
  - Dual-SD Card Storage
  - 4 Port USB
  - 32 Channel Measurement and I/O Module
  - DMX
  - MIDI
  - ...
- upgrade video card with a programmable GPU and 3 video outputs (HDMI, VGA, CVBS)
- upgrade audio card with stereo PCM capture and playback, a AY-3-8910 synthesizer, a virtual audio mixer and several inputs and output channels
- an operating system which
  - can run a desktop os
  - run a chat application
  - have a cheap-ass web browser
  - built-in documentation wiki
  - package manager / application center which allows people to share applications with others
- you get full schematic and pcb access
- you get full source code
- you can hack everything
- you can easily hack new modules on a breadboard
- looks cute

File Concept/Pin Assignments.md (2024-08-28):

# RP2350 Pin Assignments

| Pin | Function | Target               |
|-–---|----------|----------------------|
|  0  | UART 0   | Debug UART           |
|  1  | UART 0   | Debug UART           |
|  2  | I²C 1    | OnBoard I²C          |
|  3  | I²C 1    | OnBoard I²C          |
|  4  | UART 1   | UART COM 1           |
|  5  | UART 1   | UART COM 1           |
|  6  | PIO 1    | UART COM 2           |
|  7  | PIO 1    | UART COM 2           |
|  8  | GPIO     | PSRAM                |
|  9  | GPIO     | OnBoard SPI CS       |
| 10  | GPIO     | OnBoard SPI CS       |
| 11  | GPIO     | OnBoard SPI CS       |
| 12  | HSTX     | Video Output         |
| 13  | HSTX     | Video Output         |
| 14  | HSTX     | Video Output         |
| 15  | HSTX     | Video Output         |
| 16  | HSTX     | Video Output         |
| 17  | HSTX     | Video Output         |
| 18  | HSTX     | Video Output         |
| 19  | HSTX     | Video Output         |
| 20  | PIO 2    | I²S Audio Interface  |
| 21  | PIO 2    | I²S Audio Interface  |
| 22  | PIO 2    | I²S Audio Interface  |
| 23  | PIO 2    | I²S Audio Interface  |
| 24  | PIO 2    | I²S Audio Interface  |
| 25  | CLKOUT 3 | I²S Audio Interface  |
| 26  | SPI 1    | OnBoard SPI          |
| 27  | SPI 1    | OnBoard SPI          |
| 28  | SPI 1    | OnBoard SPI          |
| 29  | PIO 0    | Ethernet             |
| 30  | PIO 0    | Ethernet             |
| 31  | PIO 0    | Ethernet             |
| 32  | PIO 0    | Ethernet             |
| 33  | PIO 0    | Ethernet             |
| 34  | PIO 0    | Ethernet             |
| 35  | PIO 0    | Ethernet             |
| 36  | PIO 0    | Ethernet             |
| 37  | PIO 0    | Ethernet             |
| 38  | PIO 0    | Ethernet             |
| 39  | PIO 0    | Ethernet             |
| 40  | PIO 0    | Ethernet             |
| 41  | PIO 0    | Ethernet             |
| 42  | PIO 0    | Ethernet             |
| 43  | PIO 0    | Ethernet             |
| 44  | PIO 0    | Ethernet             |
| 45  | PIO 0    | Ethernet             |
| 46  | PIO 0    | Ethernet             |
| 47  | PIO 0    | Ethernet             |
| D+  | USB      | USB Host             |
| D-  | USB      | USB Host             |

## Pin Consumers

### PSRAM

Total Pins: 1

- CS2

### UART {Debug,COM1,COM2}

Total Pins: 2

- RXD
- TXD

### OnBoard I²S

Total Pins: 2

- SCL
- SDA

### OnBoard SPI

Total Pins: 3 + n

- SCK
- TX
- RX
- CS0 … CSn

### Video Interface

Total Pins: 8

Chosen Mode: DVI

- 8 HSTX Pins

### I²S Audio DAC + ADC

Total Pins: 6

- MCLK
- LRCK
- BCLK
- DATA OUT
- DATA IN

### ENJ624L600

Selected Interface: PSP Mode 5

Total Pins: 19

- AL
- CS
- RD
- WR
- AD0…AD14

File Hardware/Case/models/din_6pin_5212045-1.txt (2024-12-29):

"Symbol";"Value";"Unit";
"TE_104489_1";"20.83";"";
"TE_104489_2";".82";"";
"TE_905150_2";"50";"";
"TE_104480_1";"2.54";"";
"TE_905150_1";"1.27";"";
"TE_104480_2";"100";"";
"TE_901781_2";"-67 – 221";"";
"TE_104499";"250";"";
"TE_104526_1";"3.56";"";
"TE_901847_1";"2.49";"";
"TE_901847_2";".1";"";
"REFERENCE";"5212045-1";"";
"TraceParts.InstanceId";"10-27072018-0938552N3XX9WWY2MK673V115V3T3RA";"";
"TE_901781_1";"-55 – 105";"";
"TraceParts.PartTitle";"DIN Connectors";"";
"TraceParts.PartNumber";"10-27072018-093855";"";
"DESIGN";"6 CIRC DIN RCPT GRND SHLD";"";
"TE_901868";"7.5";"";
"TE_104526_2";".14";"";
"SUPPLIER";"TE Connectivity";"";
"TraceParts.PartVersion";"1.0.6";"";
"TRACEPARTS";"TRACEPARTS";"";
"TE_104496_1";"21.84";"";
"TE_104496_2";".86";"";
"TE_104534_1";"15.75";"";
"URL";"https://www.te.com/usa-en/product-5212045-1.html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";"";
"TE_905147_2";"100";"";
"TE_905147_1";"2.54";"";
"TE_104478_1";"2.54";"";
"TE_104478_2";"100";"";
"TE_104534_2";".62";"";
"TraceParts.PartLanguage";"en";"";
"TE_104509_1";"2.36";"";

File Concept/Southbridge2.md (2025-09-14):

# Ashet Express Gen1

## Pinout

| Name  | Function | Direction  | Freq Limit |
| ----- | --- | --- | --- |
| DSD0  | Downstream Data, Channel 0 | Downstream | 75 MHz |
| DSD1  | Downstream Data, Channel 1 | Downstream | 75 MHz |
| DSFE  | Downstream Frame Enable | Downstream | 7.5 MHZ |
| USD0  | Upstream Data, Channel 0 | Upstream | 75 MHz |
| USD1  | Upstream Data, Channel 1 | Upstream | 75 MHz |
| USFE  | Upstream Frame Enable | Upstream | 7.5 MHZ |
| | | | |
| | | | |
| DSRES | Downsteam Reset | | |

## Core Utilization

| Cog ID | Usage | Code Memory Range | Config Memory Range | Data Memory Range |
| --- | --- | --- | --- | --- |
| 0 | Expansion Slot 0 Conntroller | `0x`…`0x` | `0x`…`0x` | `0x`…`0x` |
| 1 | Expansion Slot 1 Controller | `0x`…`0x` | `0x`…`0x` | `0x`…`0x` |
| 2 | Expansion Slot 2 Controller | `0x`…`0x` | `0x`…`0x` | `0x`…`0x` |
| 3 | Expansion Slot 3 Controller | `0x`…`0x` | `0x`…`0x` | `0x`…`0x` |
| 4 | Expansion Slot 4 Controller | `0x`…`0x` | `0x`…`0x` | `0x`…`0x` |
| 5 | Expansion Slot 5 Controller | `0x`…`0x` | `0x`…`0x` | `0x`…`0x` |
| 6 | Expansion Slot 6 Controller | `0x`…`0x` | `0x`…`0x` | `0x`…`0x` |
| 7 | Upstream Communication Controller | `0x`…`0x` | `0x`…`0x` | `0x`…`0x` |

## Memory Layout

> TODO: Implement the nextgen packet fifo layout

### Packet Stream Configuration

```zig
/// Configuration of a single packet stream.
///
/// NOTE: All fields except `wptr` and `rptr` are static.
const StreamConfig = extern struct {
    // these four fields can be fetched in one memory access
    wptr: u8, // Index of next element in PacketRing to write. Only written by producer.
    rptr: u8, // Index of next element in PacketRing to read, read possible when wptr != rptr. Only written by consumer.
    _padding: u8 = 0,
    flags: packed struct(u8) {
        _padding: u7 = 0,
        enabled: bool, // if `true`, will set the "carry" bit of the first config u32, and is trivial to check in code then
    },

    // these can be fetched with one memory access:
    ring_base: u16, // pointer to the first byte of the *data ring buffer* in memory
    ring_limit: u16, // length of *data ring buffer* minus one. allows efficient use of INCMOD wraparound for address counting.
};

/// A packet descriptor.
///
/// NOTE: The data may wrap around in memory according to `StreamConfig.ring_base` and `StreamConfig.ring_limit`.
const Packet = packed struct(u32) {
    offset: u16, // where in memory is the packet start
    length: u16, // how long is the packet in bytes?
};

/// A ring buffer of packet slices.
const PacketRing = [32]Packet;

/// Stores the configurations of the packet streams.
const StreamConfigs = extern struct {
    downstream: [4]StreamConfig,
    upstream: [4]StreamConfig,
};

/// Stores the packet ring buffers for each of the 8 streams.
const RingStorage = extern struct {
    downstream: [4]PacketRing,
    upstream: [4]PacketRing,
};

/// NOTE: Located at `CONFIG BASE + 0x000`
const ConfigBlock = extern struct {
    configs: StreamConfigs align(1024), // NOTE: Located at `CONFIG BASE + 0x000`
    storage: RingStorage align(1024), // NOTE: Located at `CONFIG BASE + 0x400`
};
```

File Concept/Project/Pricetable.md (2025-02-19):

# Price Table

This table is a rough estimation on how expensive the parts are going to be.

| Board | Count | 1 | 10 | 50 | 75 | 100 | 150 | 250 | 500 | 750 | 1000 | 10000 |
|---|---|---|---|---|---|---|---|---|---|---|---|---|
| Backplane | 1 | 39.01 € |  31.20 € | 27.16 € | 26.25 € | 24.00 € | 23.83 € | 23.66 € | 21.67 € | 21.67 € | 21.47 € | 21.18 € |
| Mechanical  | 1 | 20.12 € |  16.06 € | 13.73 € | 13.73 € | 13.08 € | 13.08 € | 13.08 € | 13.08 € | 13.08 € | 13.08 € | 13.08 € |
| E_RS232 | 1 | 13.75 € | 6.67 € |  4.93 € |  4.83 € |  4.82 € |  4.58 € |  4.47 € |  4.36 € |  4.35 € |  4.31 € |  4.07 € |
| E_CBM-IEC | 1 | 13.59 € | 6.58 € |  4.72 € |  4.62 € |  4.61 € |  4.32 € |  4.16 € |  4.00 € |  4.00 € |  4.00 € |  3.72 € |
| Mainboard | 1 | 12.78 € | 9.87 € |  8.11 € |  7.68 € |  7.28 € |  7.02 € |  6.78 € |  6.57 € |  6.57 € |  6.38 € |  6.16 € |
| E_SoundCard | 1 | 10.99 € | 4.40 € |  3.18 € |  3.08 € |  3.08 € |  2.86 € |  2.73 € |  2.61 € |  2.60 € |  2.60 € |  2.36 € |
| E_USBx4 | 1 | 9.31 € | 2.86 € |  2.01 € |  1.85 € |  1.81 € |  1.76 € |  1.69 € |  1.62 € |  1.61 € |  1.61 € |  1.51 € |
| E_BASIC-IO  | 1 | 8.64 € | 2.41 € |  1.70 € |  1.60 € |  1.59 € |  1.35 € |  1.35 € |  1.34 € |  1.26 € |  1.23 € |  1.06 € |
| E_VideoCard | 1 | 8.49 € | 2.34 € |  1.55 € |  1.45 € |  1.41 € |  1.36 € |  1.31 € |  1.27 € |  1.27 € |  1.27 € |  1.09 € |
| E_Perfboard | 1 | 7.67 € | 1.68 € |  0.96 € |  0.86 € |  0.86 € |  0.81 € |  0.81 € |  0.80 € |  0.79 € |  0.79 € |  0.69 € |
| Netto | |  144.32 € |  84.07 € | 68.05 € | 65.93 € | 62.52 € | 60.97 € | 60.05 € | 57.33 € | 57.21 € | 56.75 € | 54.91 € |
| Brutto | |  171.74 € | 100.05 € | 80.98 € | 78.46 € | 74.40 € | 72.55 € | 71.46 € | 68.22 € | 68.08 € | 67.53 € | 65.35 € |
| Price Level | |  100.00 % |  58.25 % | 47.15 % | 45.68 % | 43.32 % | 42.24 % | 41.61 % | 39.72 % | 39.64 % | 39.32 % | 38.05 % |

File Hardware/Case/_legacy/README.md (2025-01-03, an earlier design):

# Case

Using [RM2095L](https://www.hammfg.com/electronics/small-case/plastic/rm2) from Hammond as a case sounds like a good idea.

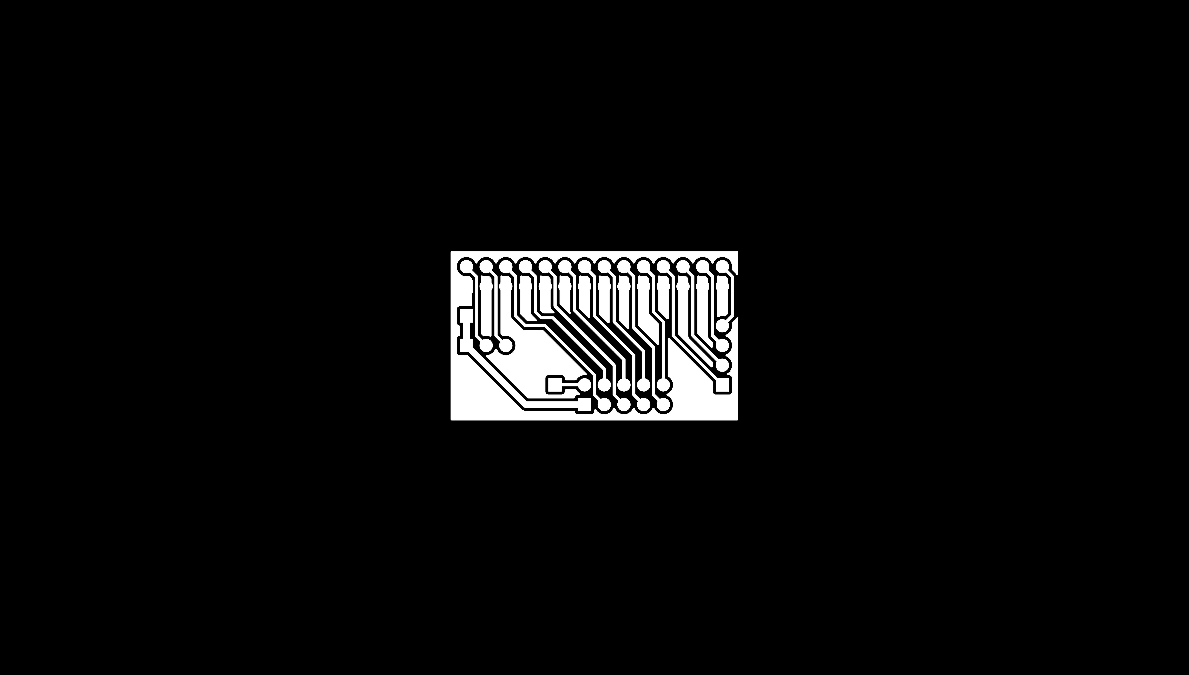
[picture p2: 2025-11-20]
Hardware/Interconnector/Export/layer0.png

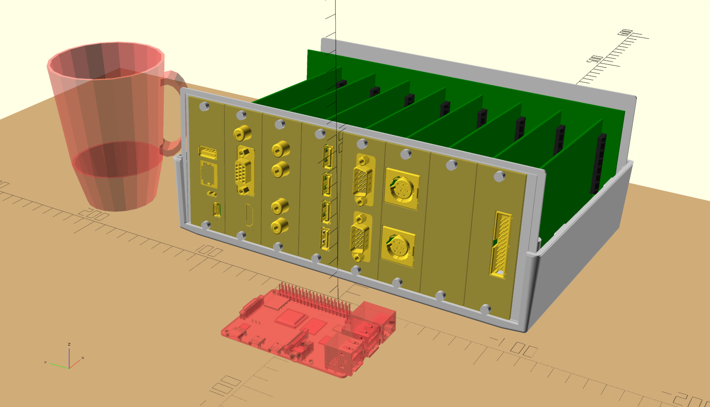
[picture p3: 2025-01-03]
Concept/case-concept.png

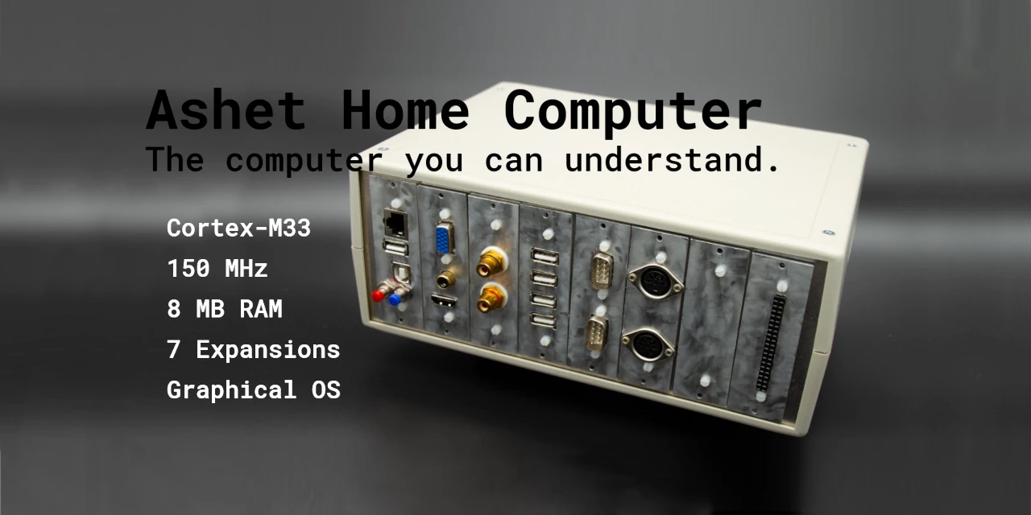
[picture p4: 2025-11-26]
Media/Social Media Preview.webp

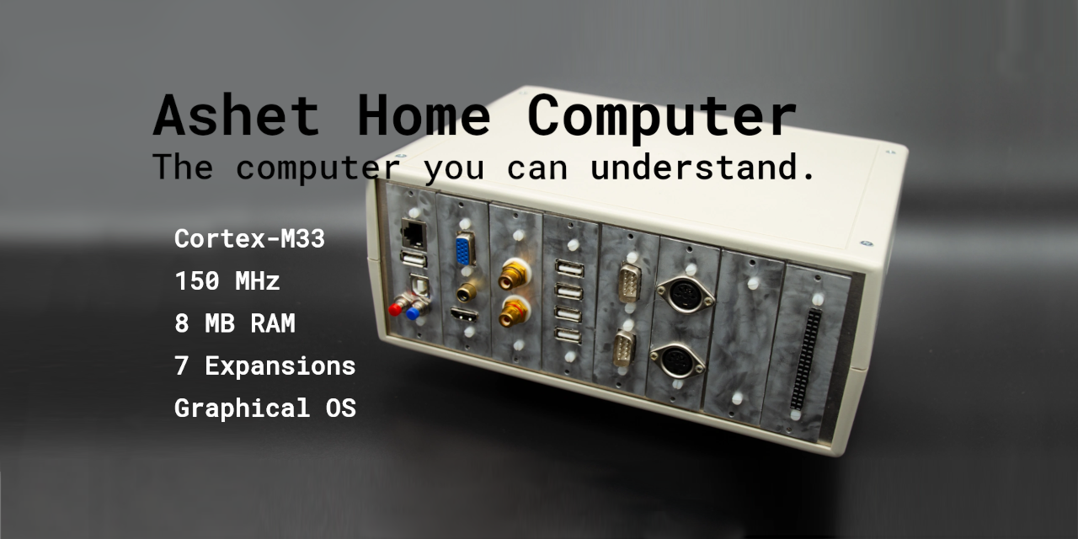
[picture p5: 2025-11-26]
Media/Social Media Preview.png

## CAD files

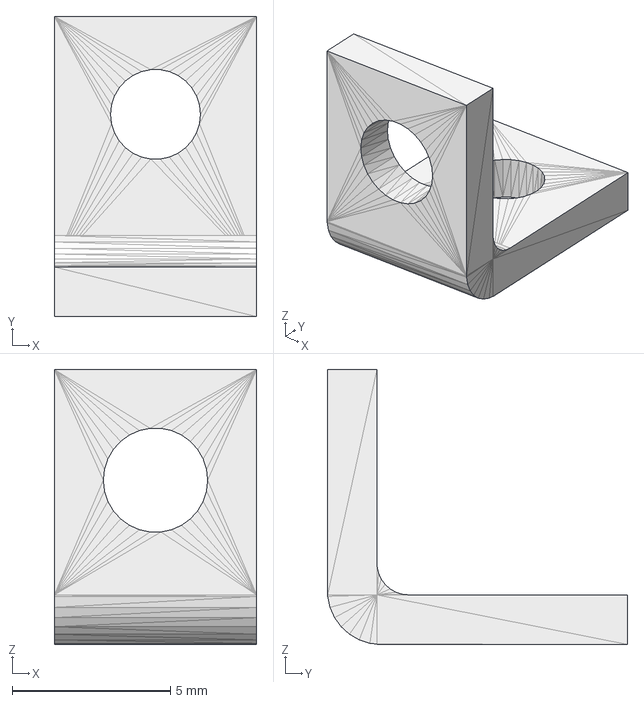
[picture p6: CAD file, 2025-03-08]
Hardware/Case/models/keystone_612.stp
6.40 x 9.50 x 8.70 mm

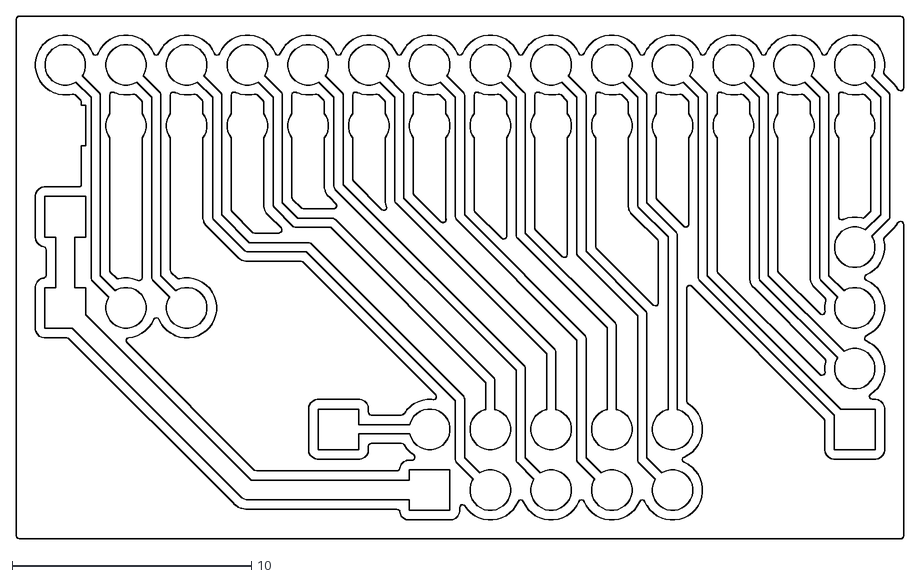
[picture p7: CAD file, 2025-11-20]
Hardware/Interconnector/Export/Interconnector-B_Cu.dxf
37.1 x 21.9

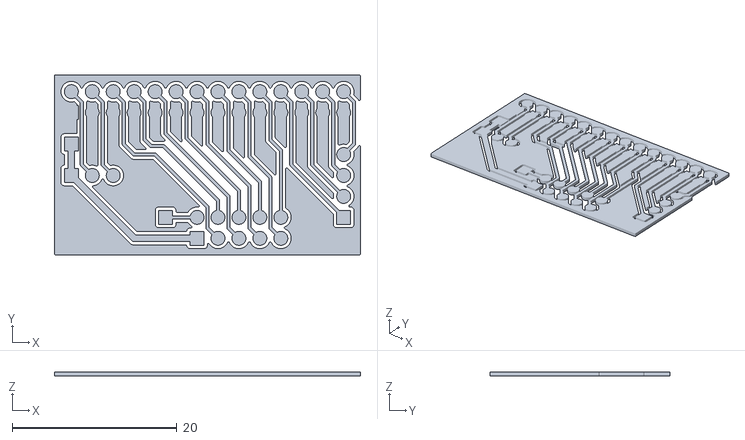
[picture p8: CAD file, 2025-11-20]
Hardware/Interconnector/Interconnector.stl
37.1 x 21.9 x 0.5

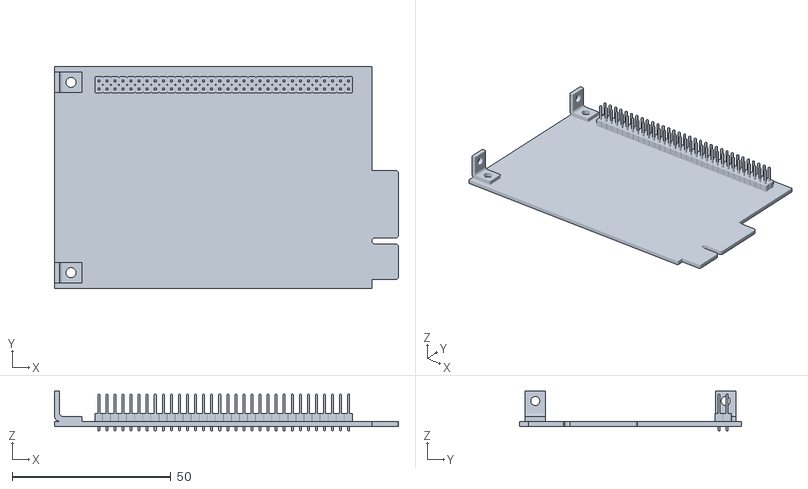
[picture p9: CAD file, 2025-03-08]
Hardware/Mechanical Prototype/Expansion Board/Expansion Board.stl
108.4 x 70.0 x 12.5

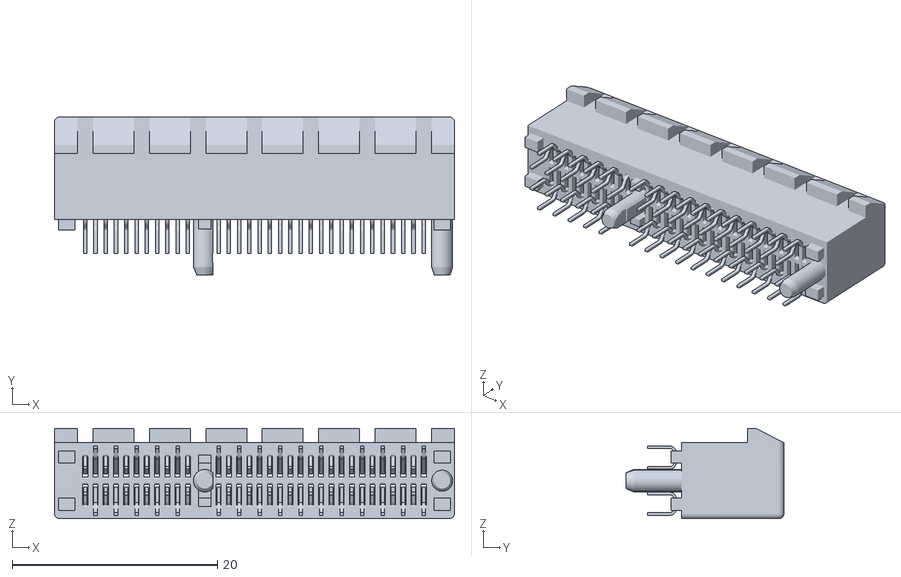
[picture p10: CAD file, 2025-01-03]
Hardware/Case/models/pcie_x4_10018784-10201TLF.stl
39.0 x 15.4 x 8.80

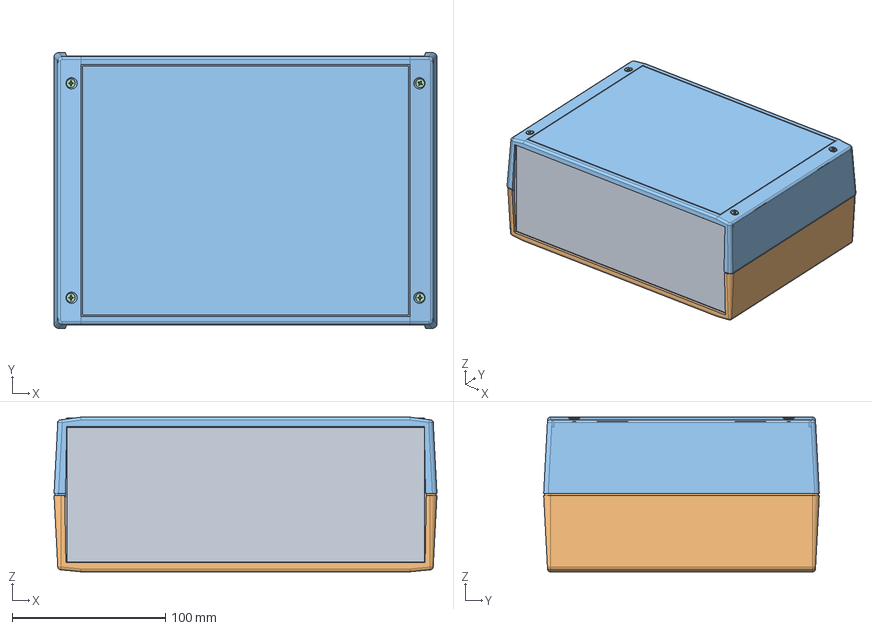
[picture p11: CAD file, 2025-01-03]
Hardware/Case/models/rm2095l.stp
250.0 x 180.0 x 101.0 mm
2095L-p-01 x 2
2095L-T 950803
2095L-B-01
(screw M3-0.5X 55mm FH) x 4

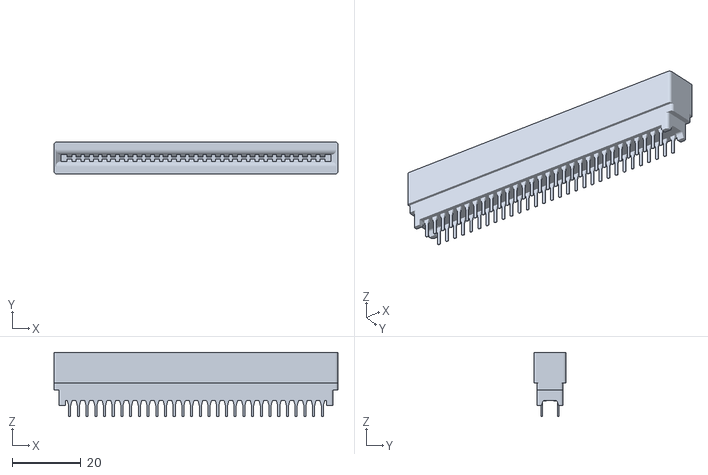
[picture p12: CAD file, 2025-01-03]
Hardware/Case/models/pcie_x4_5530843-7.stl
82.8 x 9.35 x 18.7

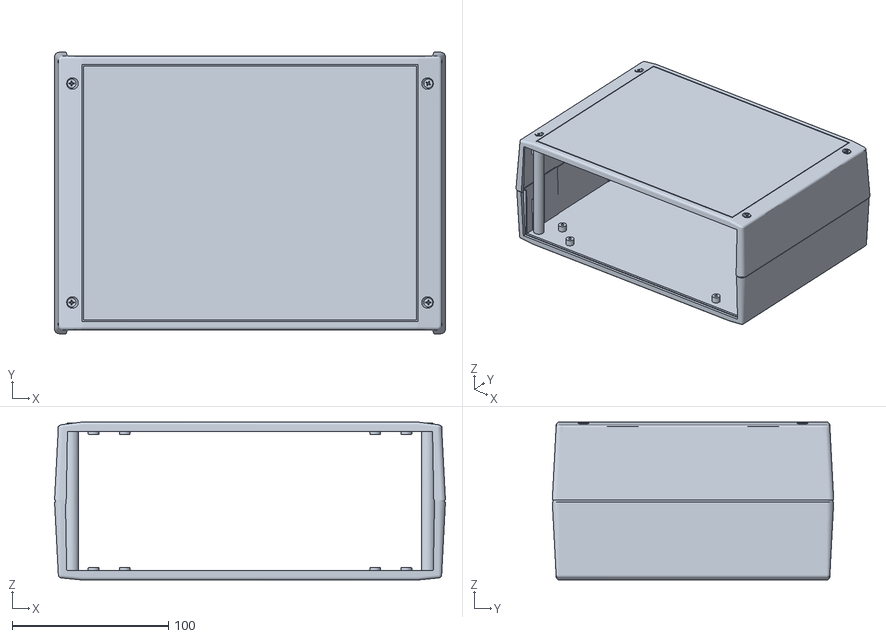
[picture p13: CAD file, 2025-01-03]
Hardware/Case/models/rm2095l_no_frontplate.stl
250.0 x 180.0 x 101.0

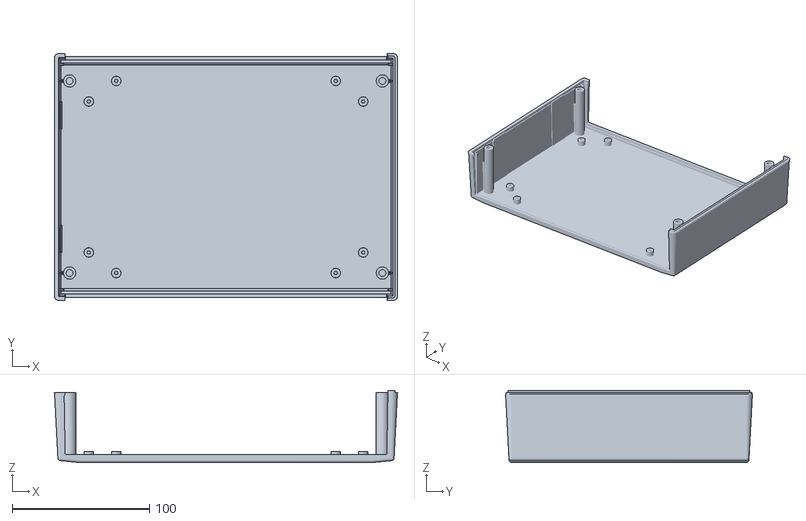
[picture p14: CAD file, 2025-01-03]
Hardware/Case/models/rm2095l_bottom_part.stl
250.0 x 180.0 x 52.5

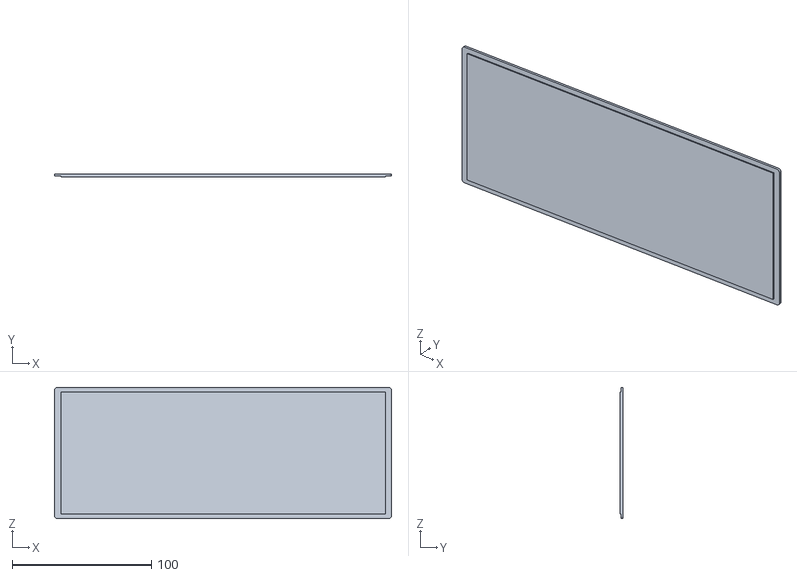
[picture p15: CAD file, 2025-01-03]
Hardware/Case/models/rm2095l_frontplate.stl
242.2 x 2.30 x 94.2

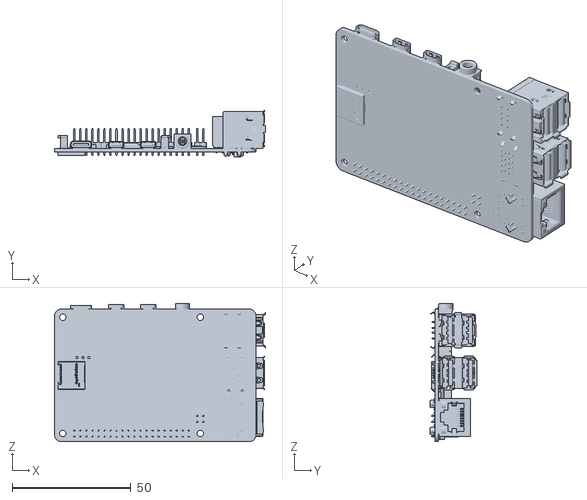
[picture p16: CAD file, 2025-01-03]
Hardware/Case/models/raspberrypi-model-4b.stl
89.0 x 19.9 x 58.4

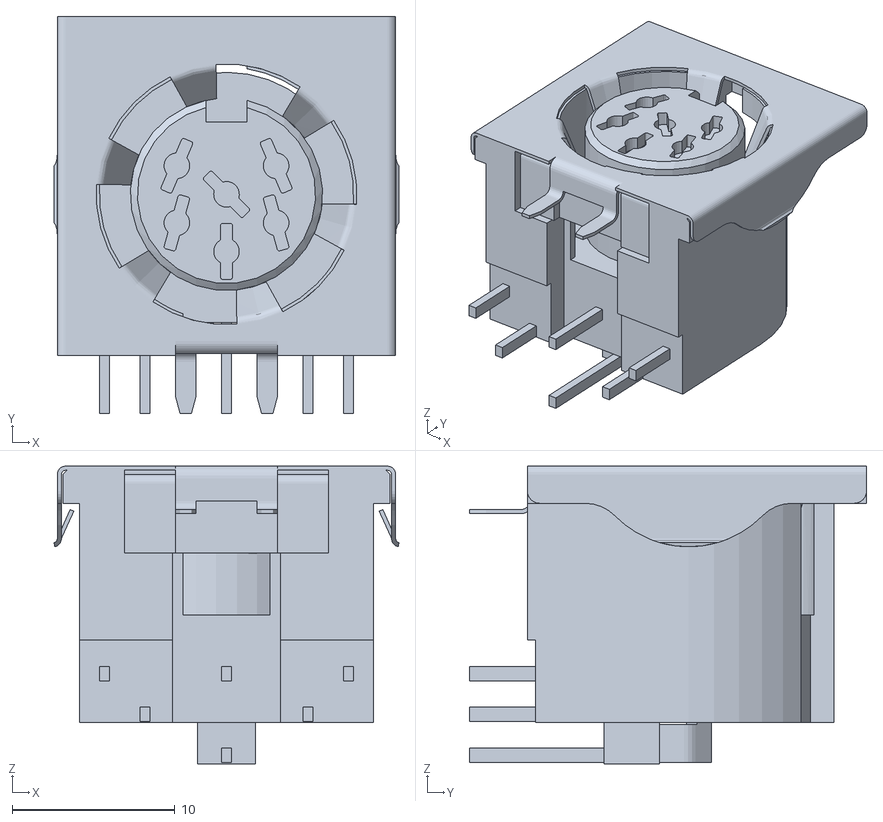
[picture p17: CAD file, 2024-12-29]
Hardware/Case/models/din_6pin_5212045-1.stl
21.2 x 24.4 x 18.3

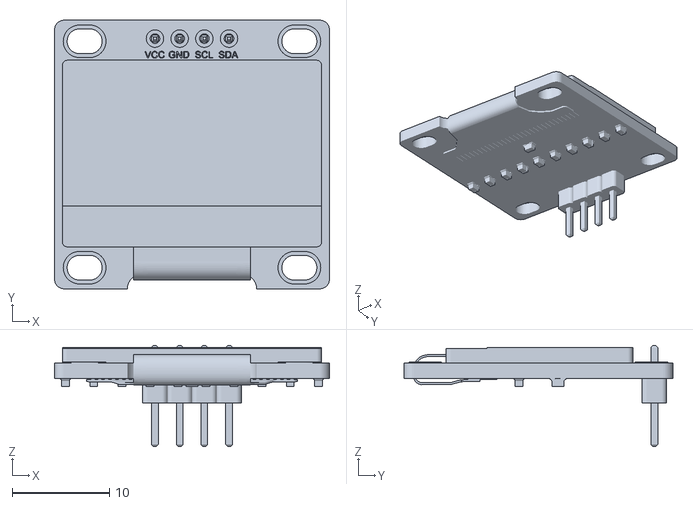
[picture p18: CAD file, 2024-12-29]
Hardware/Case/models/Tela OLed 128x64 v15.stl
28.3 x 27.6 x 10.4

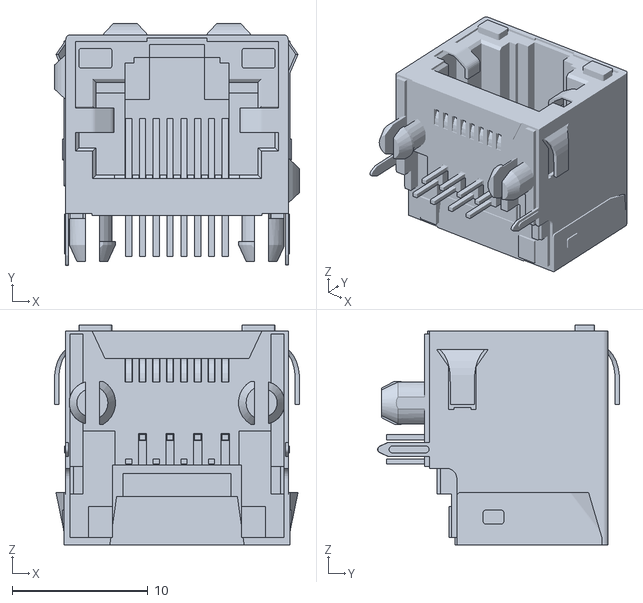
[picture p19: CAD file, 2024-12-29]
Hardware/Case/models/rj45_43860-0016.stl
18.0 x 17.8 x 16.2

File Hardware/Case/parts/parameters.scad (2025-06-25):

// Metadata

M2_5     = [2.5,   2.7, 5.0, 2.0]; // screw thickness, hole diameter, nut dia, nut height
M3       = [3.0,   3.2, 5.5, 2.4]; // screw thickness, hole diameter, nut dia, nut height
UNC_4_40 = [2.845, 3.0, 4.0, 2.0]; // screw thickness, hole diameter, nut dia, nut height

// Configuration

SLOTS = 8;

// Slot Configuration

slot_separation = 28; // distance between slot centers

// size of the slot panel
slot_plate_width = 27;
slot_plate_height = 85;
slot_plate_thickness = 1.0;

// slot panel screw
slot_screw_type = M2_5;
slot_screw_inset = 3.0;
slot_screw_length = 4.5;

assert(slot_plate_width < slot_separation);

// size of the slot cutout
slot_hole_width = 24;
slot_hole_height = 73;

assert(slot_hole_width < slot_plate_width);
assert(slot_hole_height < slot_plate_height);

// size of the slot pcb
slot_pcb_height = 70;
slot_pcb_thickness = 1.6;
slot_pcb_length = 100;
slot_pcb_conn_offset = -15;

// offset of PCB to plate center
slot_pcb_offset = -9;

assert(slot_pcb_offset + slot_pcb_thickness / 2 < slot_hole_width/2)
assert(slot_pcb_height < slot_hole_height);

// Distance between the two mounting screw points on the PCB
slot_mount_screw_dist = 60; // mm
slot_mount_screw_pcb_dist = 6.4; // mm distance from the PCB top
slow_mount_screw_type = UNC_4_40;

// Baseplate
baseplate_thickness = 2.0; // Thickness of the baseplate
baseplate_spread = 41.4; // Distance between "center" and baseplate surface

// Backplane

// Offset from center
backplane_offset = -26.5;
backplane_thickness = 1.6;
backplane_width = 240;
backplane_height = 87;
backplane_inset_width = 200;
backplane_inset_height = 80.5;

// Frontpanel
frontpanel_thickness = 2.0;

// PCB Sliders

pcb_slider_pcb_vmargin = 0.4;
pcb_slider_pcb_hmargin = 0.2;
pcb_slider_height = 6.6; // mm
pcb_slider_width_top = 4.5; // mm
pcb_slider_width_bot = 5.5; // mm
pcb_slider_holes = 3;
pcb_slider_hole_margin = 10; // mm
pcb_slider_case_margin = 5; // mm
pcb_slider_hole_screw = M2_5;
pcb_slider_bevel_len = 10; // mm
pcb_slider_bevel_angle = 7.5; // deg

// Automation Variables:
RENDER_PART_2D = false;
RENDER_PART_3D = false;

// Derived parameters

slot_screw_offset = slot_plate_height/2-slot_screw_inset;

pcb_slider_depth = baseplate_spread - baseplate_thickness/2 - slot_pcb_height / 2 - pcb_slider_pcb_vmargin; // mm
pcb_slider_notch_width_top = slot_pcb_thickness + 4 * pcb_slider_pcb_hmargin; // mm
pcb_slider_notch_width_bot = slot_pcb_thickness + 2 * pcb_slider_pcb_hmargin; // mm
pcb_slider_length = slot_pcb_length - 2 * pcb_slider_case_margin; // mm

echo(pcb_slider_depth, pcb_slider_height);
assert(pcb_slider_depth < pcb_slider_height);

// Utility modules

/* Invokes children() once for each slot, offsetted on the X axis, slot center. */
module foreach_slot()
{
    for ($i = [0:SLOTS - 1])
    {
        dx = slot_separation * ($i - (SLOTS - 1) / 2);
        translate([ dx, 0, 0 ]) children();
    }
}

module screw_shaft_2d(screw)
{
    circle(d=screw[0], $fn=20);
}

module screw_hole_2d(screw)
{
    circle(d=screw[1], $fn=20);
}

module screw_nut_2d(screw)
{
    circle(d=screw[2], $fn=6);
}

module screw_nut(screw)
{
    linear_extrude(screw[3]) screw_nut_2d(screw); 
}

module screw_model(screw, length)
{
    translate([0,0,-screw[3]]) screw_nut(screw);
    linear_extrude(length) screw_shaft_2d(screw); 
}

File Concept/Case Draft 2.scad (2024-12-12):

use <common.scad>

show_case_top = true;
show_case_bot = true;
show_case_left = true;
show_case_right = true;
show_case_back = true;

active_modules = 5; // [0:8]

slot_count = 8;
slot_height = 30; // mm

pcb_width = 100;  // mm
pcb_length = 160; // mm

pcb_thick = 1.6;  // mm
case_thick = 1.0; // mm

case_width = pcb_width + 2 * case_thick;
case_length = pcb_length + 20 + 2 * case_thick;
case_height = slot_height * slot_count + 2 * case_thick;

bar_corner_size = 8;               // mm
bar_slider_size = 5;               // mm
bar_slider_sep = pcb_thick + 0.25; // mm

conn_insert_depth = 7.5;   // mm
conn_insert_width = 78.74; // mm
conn_total_height = 15.49; // mm
pcb_len_cutoff = 10.0;     // mm

backplane_margin = 2; // mm

module con_video()
{
    import("c-5-5530843-0-f-3d.stl");
}

module con_audio()
{
    import("c-7-5530843-5-f-3d.stl");
}

module con_standard()
{
    import("c-5530843-4-f-3d.stl");
}

module con_unified()
{
    // import("c-5530843-6-f-3d.stl");
    import("c-5530843-7-f-3d.stl");
}

module bar_corner()
{
    mat_gold() cube([ bar_corner_size, case_length - 2 * case_thick, bar_corner_size ]);
}

module bar_vcorner()
{
    mat_gold() cube([ bar_corner_size, bar_corner_size, slot_height * slot_count - 2 * bar_corner_size ]);
}

module bar_slider()
{
    mat_gold() cube([ bar_slider_size, pcb_length - pcb_len_cutoff, bar_slider_size ]);
}

module pcb_eurocard()
{
    mat_pcb() translate([ 0, 0, -pcb_thick / 2 ]) cube([ pcb_width, pcb_length, pcb_thick ]);
}

translate([ -80, 80, 0 ]) ikea_coffee_mug();

module case()
{
    // sides
    if(show_case_left) mat_metal() cube([ case_thick, case_length, case_height ]);
    if(show_case_right) mat_metal() translate([ case_width - case_thick, 0, 0 ]) cube([ case_thick, case_length, case_height ]);
    
    // back
    if(show_case_back) mat_metal() translate([ case_thick, case_length - case_thick, 0 ]) cube([ case_width - 2 * case_thick, case_thick, case_height ]);

    // bottom
    if(show_case_bot) mat_metal() translate([ case_thick, case_thick, 0 ]) cube([ case_width - 2 * case_thick, case_length - 2 * case_thick, case_thick ]);
    
    // top
    if(show_case_top) mat_metal() translate([ case_thick, case_thick, case_height - case_thick ]) cube([ case_width - 2 * case_thick, case_length - 2 * case_thick, case_thick ]);
}


module interior()
{
    bar_corner();
    translate([ case_width - 2 * case_thick - bar_corner_size, 0, 0 ]) bar_corner();

    translate([ 0, 0, case_height - 2 * case_thick - bar_corner_size ])
    {
        bar_corner();
        translate([ case_width - 2 * case_thick - bar_corner_size, 0, 0 ]) bar_corner();
        ;
    }

    for (i = [0:slot_count - 1])
{
    translate([ 0, 0, bar_corner_size - bar_slider_size + slot_height * i ])
    {
        bar_slider();
        translate([ case_width - 2 * case_thick - bar_slider_size, 0, 0 ]) bar_slider();
    }
    translate([ 0, 0, bar_corner_size + bar_slider_sep + slot_height * i ])
    {
        bar_slider();
        translate([ case_width - 2 * case_thick - bar_slider_size, 0, 0 ]) bar_slider();
    }
}

// vertical backplane mount bars:
translate([ 0, pcb_length - conn_insert_depth + conn_total_height - bar_corner_size, bar_corner_size ]) bar_vcorner();
translate([
    case_width - 2 * case_thick - bar_corner_size, pcb_length - conn_insert_depth + conn_total_height - bar_corner_size,
    bar_corner_size
]) bar_vcorner();
}

module slot()
{
    // lift to pcb center level
    translate([ 0, 0, bar_corner_size + bar_slider_sep / 2 ])
    {
        difference()
        {
            pcb_eurocard();

            esize = (pcb_width - conn_insert_width) / 2;
            translate([ -esize, pcb_length - pcb_len_cutoff, -pcb_thick ])
                cube([ 2 * esize, 2 * conn_insert_depth, 2 * pcb_thick ]);
            translate([ pcb_width - esize, pcb_length - pcb_len_cutoff, -pcb_thick ])
                cube([ 2 * esize, 2 * conn_insert_depth, 2 * pcb_thick ]);
        }
    }
}

module backplane()
{
    mat_pcb() difference()
    {
        cube([ pcb_width - 2 * backplane_margin, pcb_thick, slot_height * slot_count - 2 * backplane_margin ]);
        // TODO: Cut out corners
        // cube([bar_corner_size+backplane_margin,bar_corner_size+backplane_margin,pcb_thick * 2]);
    }

    for (i = [0:slot_count - 1])
    {
        translate([ 0, 0, slot_height * i ]) translate([
            pcb_width / 2 - backplane_margin, -conn_total_height, bar_corner_size + bar_slider_sep / 2 -
            backplane_margin
        ]) rotate(90, [ 1, 0, 0 ]) con_unified();
    }
}

translate([ -case_thick, -case_thick, -case_thick ]) case();

interior();

for (i = [0:active_modules - 1])
{
    translate([ 0, 0, slot_height * i ]) slot();
}

// backplane
translate([ backplane_margin, pcb_length - conn_insert_depth + conn_total_height, backplane_margin ]) backplane();

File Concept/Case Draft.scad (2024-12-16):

//
// $ openscad --autocenter --viewall --preview  -o /tmp/result.stl "Case Draft.scad"

pcb_width = 100;  // mm
pcb_length = 160; // mm

pcb_thick = 1.6;  // mm
case_thick = 1.0; // mm

slot_width = pcb_width + 2 * case_thick; // mm
slot_length = pcb_length + 6;            // mm
slot_height = 30;                        // mm
slot_pcb_voffset = 5;                    // mm
slot_slider_width = 3;                   // mm
slot_slider_height = 3;                  // mm
slot_slider_margin = 0.05;               // mm
slot_strut_count = 4;
slot_strut_width = 2; // mm

slot_conn_cx = 20;
slot_conn_cy = 2;
slot_conn_spc = 2.54; // mm
slot_conn_height = 5; // mm

slot_padding = 2; // mm
slot_count = 8;

case_backplane_space = 5; // mm
case_base_height = 5;     // mm
case_base_dia = 10;       // mm
case_base_margin = 10;    // mm

mod_cover_padding = 0.5; // mm

inside_slice_perc = 100;
mod_extrusion = 0;
total_height = 265;

module mat_metal()
{
    color("#CCCCCC") children();
}

module mat_gold()
{
    color("#F4C75E") children();
}

module mat_pcb()
{
    color("#008000") children();
}

module mat_component()
{
    color("#404040") children();
}

module mat_plastic()
{
    color("#BDA897") children();
}

module expansion_slot()
{
    // Side Walls
    mat_plastic()
    {

        cube([ case_thick, slot_length, slot_height ]);
        translate([ slot_width - case_thick, 0, 0 ]) cube([ case_thick, slot_length, slot_height ]);

        for (i = [0:slot_strut_count - 1])
        {
            dy = (slot_length - slot_strut_width) * i / (slot_strut_count - 1);
            translate([ 0, dy, 0 ]) cube([ slot_width, slot_strut_width, case_thick ]);
            translate([ 0, dy, slot_height - case_thick ]) cube([ slot_width, slot_strut_width, case_thick ]);
        }

        // PCB Sockets
        translate([ 0, 0, slot_pcb_voffset ])
        {
            difference()
            {
                union()
                {
                    translate([ 0, 0, -slot_slider_height / 2 ]) cube(
                        [ slot_slider_width, pcb_length + (slot_slider_height - pcb_thick) / 2, slot_slider_height ]);
                    translate([ slot_width - case_thick - slot_slider_width, 0, -slot_slider_height / 2 ]) cube(
                        [ slot_slider_width, pcb_length + (slot_slider_height - pcb_thick) / 2, slot_slider_height ]);
                }
                translate([ slot_width / 2 - slot_slider_margin / 2, pcb_length / 2 - slot_slider_margin / 2, 0 ]) cube(
                    [ pcb_width + slot_slider_margin, pcb_length + slot_slider_margin, pcb_thick + slot_slider_margin ],
                    center = true);
            }
        }
    }
}

module slot_interface()
{
    cw = (slot_conn_cx + 0.5) * slot_conn_spc;
    ch = (slot_conn_cy + 0.5) * slot_conn_spc;
    mat_component() translate([ (slot_width - cw) / 2, -slot_conn_height, slot_pcb_voffset - ch / 2 ])
        cube([ cw, slot_conn_height, ch ]);
}

module backplane()
{
    h = slot_height * slot_count + slot_padding * (slot_count - 1);

    mat_pcb() cube([ slot_width, pcb_thick, h ]);

    for (i = [0:slot_count - 1])
    {
        translate([ 0, 0, i * (slot_height + slot_padding) ]) slot_interface();
    }
}

module casing()
{
    h = slot_height * slot_count + slot_padding * (slot_count - 1);
    l = slot_length + case_backplane_space;

    mat_metal() translate([ -case_thick, -case_thick, -case_thick ]) difference()
    {
        cube([ slot_width + 2 * case_thick, l + 2 * case_thick, h + 2 * case_thick ]);
        translate([ case_thick, -1, case_thick ]) cube([ slot_width, l + 1, h ]);
    }
}

module case_assembly()
{
    casing();

    translate([ 0, slot_length + 1, 0 ]) backplane();

    for (i = [0:slot_count - 1])
    {
        translate([ 0, 0, i * (slot_height + slot_padding) ]) expansion_slot();
    }
}

module expansion_mod()
{
    dx = (slot_width - pcb_width) / 2;
    translate([ dx, 0, 0 ])
    {
        mat_pcb() translate([ pcb_width / 2, pcb_length / 2, 0 ])
            cube([ pcb_width, pcb_length, pcb_thick ], center = true);
        mat_metal() translate([ -dx + mod_cover_padding, -case_thick, -slot_pcb_voffset + mod_cover_padding ])
            cube([ slot_width - 2 * mod_cover_padding, case_thick, slot_height - 2 * mod_cover_padding ]);
    };

    cw = (slot_conn_cx - 1) * slot_conn_spc;
    ch = (slot_conn_cy - 1) * slot_conn_spc;

    mat_gold() translate([ (slot_width - cw) / 2, pcb_length - 2, -ch / 2 ])
    {
        for (ix = [0:slot_conn_cx - 1])
        {
            for (iy = [0:slot_conn_cy - 1])
            {
                translate([ slot_conn_spc * ix, 0, slot_conn_spc * iy ]) rotate(-90, [ 1, 0, 0 ])
                    cylinder(h = 5, d = 0.5);
            }
        }
    }
}

module full_assembly()
{
    translate([ 0, 0, case_base_height + case_thick ])
    {
        case_assembly();
        for (i = [0:slot_count - 1])
        {
            translate([ 0, -mod_extrusion, i * (slot_height + slot_padding) + slot_pcb_voffset ]) expansion_mod();
        }
    }

    mat_component()
    {
        translate([ case_base_margin, case_base_margin, 0 ]) cylinder(h = case_base_height, d = case_base_dia);
        translate([ slot_width - case_base_margin, case_base_margin, 0 ])
            cylinder(h = case_base_height, d = case_base_dia);

        translate([ case_base_margin, slot_length + case_backplane_space - case_base_margin, 0 ])
            cylinder(h = case_base_height, d = case_base_dia);
        translate([ slot_width - case_base_margin, slot_length + case_backplane_space - case_base_margin, 0 ])
            cylinder(h = case_base_height, d = case_base_dia);
    }
}

module ikea_coffee_mug()
{
    $fs = 0.1;
    $fa = 10;
    hs1 = 30;
    hs2 = 75;
    db = 50;
    ds = 65;
    dt = 80;
    t = 2;

    hw = 15;
    hd = 60;
    ht = 5;
    hvo = 35;

    difference()
    {
        union()
        {
            cylinder(h = hs1, d1 = db, d2 = ds);
            translate([ 0, 0, hs1 ]) cylinder(h = hs2, d1 = ds, d2 = dt);

            // handle:
            translate([ -hw / 2, -40, hvo + hd / 2 ]) rotate(5, [ 1, 0, 0 ]) rotate(90, [ 0, 1, 0 ])
                scale([ 1, 0.5, 1 ]) difference()
            {
                cylinder(h = hw, d = hd);
                translate([ 0, 0, -hw ]) cylinder(h = 3 * hw, d = hd - 2 * ht);
            }
        }
        translate([ 0, 0, t ]) cylinder(h = hs1 - t + 0.01, d1 = db - 2 * t, d2 = ds - 2 * t);
        translate([ 0, 0, hs1 - 0.001 ]) cylinder(h = hs2 + t + 0.01, d1 = ds - 2 * t, d2 = dt - 2 * t);
    }
}

// expansion_slot();
//  expansion_mod();

difference()
{
    full_assembly();

    translate([ -50, -50, inside_slice_perc * total_height / 100 ]) cube([ 400, 400, 400 ]);
}

translate([ -80, 80, 0 ]) ikea_coffee_mug();

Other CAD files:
Hardware/Case/models/usb_a_2_0_fem_vert_a-e.stl
Hardware/Case/models/pinheader_12x2_302-R241-56544.stl
Hardware/Case/models/microsw_vert_2x_141_TL2243.stl
Hardware/Case/models/cinch_rcj-041.stl
Hardware/Case/case.scad
Hardware/Case/_legacy/#case-study.scad
Hardware/Case/_legacy/c-5-5530843-0-f-3d.stl
Hardware/Case/_legacy/c-5530843-4-f-3d.stl
Hardware/Case/_legacy/c-5530843-6-f-3d.stl
Hardware/Case/_legacy/c-5530843-7-f-3d.stl
Hardware/Case/_legacy/c-7-5530843-5-f-3d.stl
Hardware/Case/_legacy/case-layout-study.scad
Hardware/Case/_legacy/simplecase-v2.scad
Hardware/Case/_legacy/simplecase-v3.scad
Hardware/Case/_legacy/visuals.scad
Hardware/Case/expansions.scad
Hardware/Case/models/10294970.stl
Hardware/Case/models/dvi_fem_74320-1007.stl
Hardware/Case/models/hdmi_fem_2010418.stl
Hardware/Case/models/jack_3_5_fem_8051665.stl
Hardware/Case/models/keystone_612.stl
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

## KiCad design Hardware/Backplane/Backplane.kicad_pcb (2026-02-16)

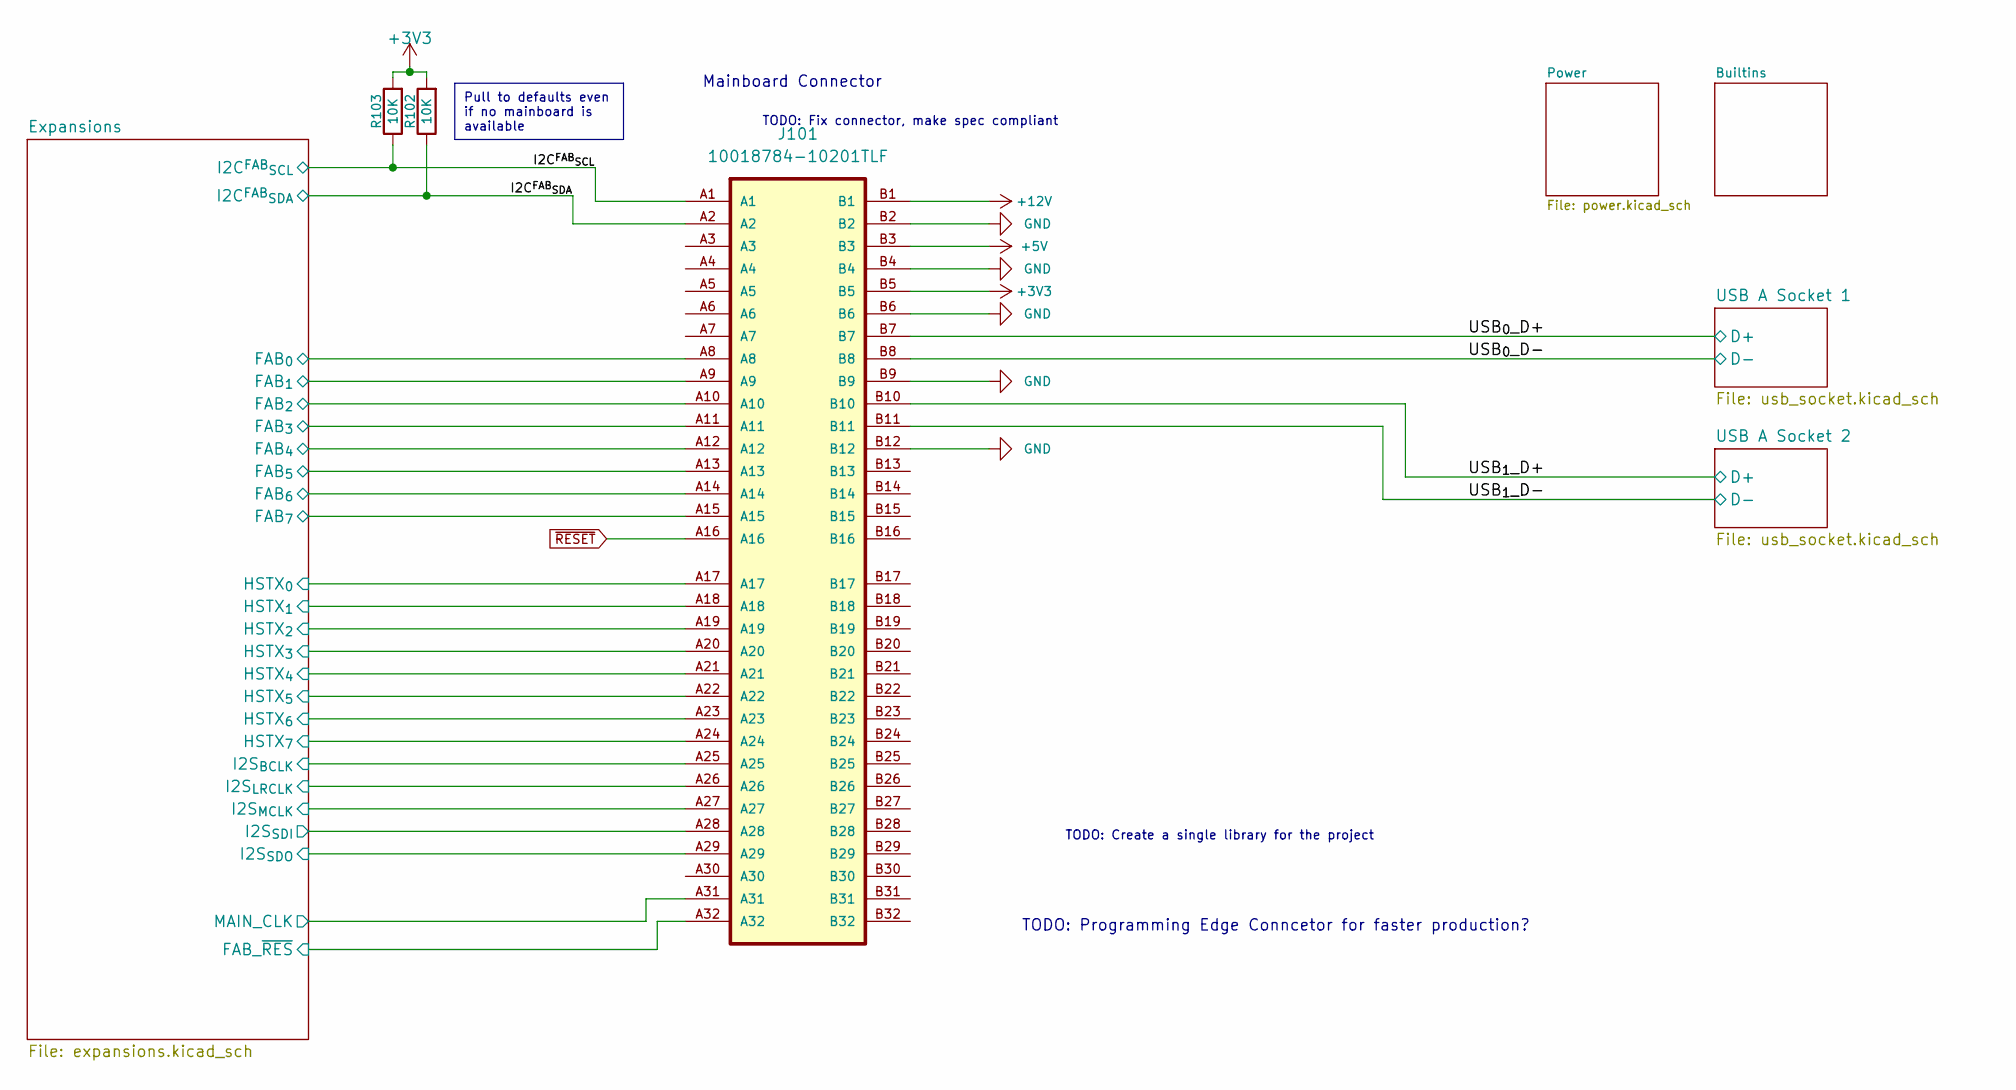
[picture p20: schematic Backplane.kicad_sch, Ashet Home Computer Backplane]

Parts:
J101: 10018784-10201TLF; CONN_10018784-10201TLF; Digikey Part No 609-2026-ND
R102, R103: 10K; R_0603_1608Metric; Digikey Part No 311-10.0KHRCT-ND

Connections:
+3V3: J101.B5, R102.2, R103.2; also elsewhere on the board
+5V: J101.B3; also elsewhere on the board
+12V: J101.B1; also elsewhere on the board
/Expansions/FAB_{0}: J101.A8; also elsewhere on the board
/Expansions/FAB_{1}: J101.A9; also elsewhere on the board
/Expansions/FAB_{2}: J101.A10; also elsewhere on the board
/Expansions/FAB_{3}: J101.A11; also elsewhere on the board
/Expansions/FAB_{4}: J101.A12; also elsewhere on the board
/Expansions/FAB_{5}: J101.A13; also elsewhere on the board
/Expansions/FAB_{6}: J101.A14; also elsewhere on the board
/Expansions/FAB_{7}: J101.A15; also elsewhere on the board
/Expansions/FAB_~RES: J101.A32; also elsewhere on the board
/Expansions/HSTX_{0}: J101.A17; also elsewhere on the board
/Expansions/HSTX_{1}: J101.A18; also elsewhere on the board
/Expansions/HSTX_{2}: J101.A19; also elsewhere on the board
/Expansions/HSTX_{3}: J101.A20; also elsewhere on the board
/Expansions/HSTX_{4}: J101.A21; also elsewhere on the board
/Expansions/HSTX_{5}: J101.A22; also elsewhere on the board
/Expansions/HSTX_{6}: J101.A23; also elsewhere on the board
/Expansions/HSTX_{7}: J101.A24; also elsewhere on the board
/Expansions/I2S_{BCLK}: J101.A25; also elsewhere on the board
/Expansions/I2S_{LRCLK}: J101.A26; also elsewhere on the board
/Expansions/I2S_{MCLK}: J101.A27; also elsewhere on the board
/Expansions/I2S_{SDI}: J101.A28; also elsewhere on the board
/Expansions/I2S_{SDO}: J101.A29; also elsewhere on the board
/Expansions/MAIN_CLK: J101.A31; also elsewhere on the board
/I2C^{FAB}_{SCL}: J101.A1, R103.1
/I2C^{FAB}_{SDA}: J101.A2, R102.1
/USB_{0}_D+: J101.B7; also elsewhere on the board
/USB_{0}_D-: J101.B8; also elsewhere on the board
/USB_{1}_D+: J101.B10; also elsewhere on the board
/USB_{1}_D-: J101.B11; also elsewhere on the board
GND: J101.B2, J101.B4, J101.B6, J101.B9, J101.B12; also elsewhere on the board
~RESET: J101.A16; also elsewhere on the board

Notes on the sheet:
Mainboard Connector
TODO: Programming Edge Conncetor for faster production?
TODO: Create a single library for the project
TODO: Fix connector, make spec compliant
Pull to defaults even if no mainboard is available

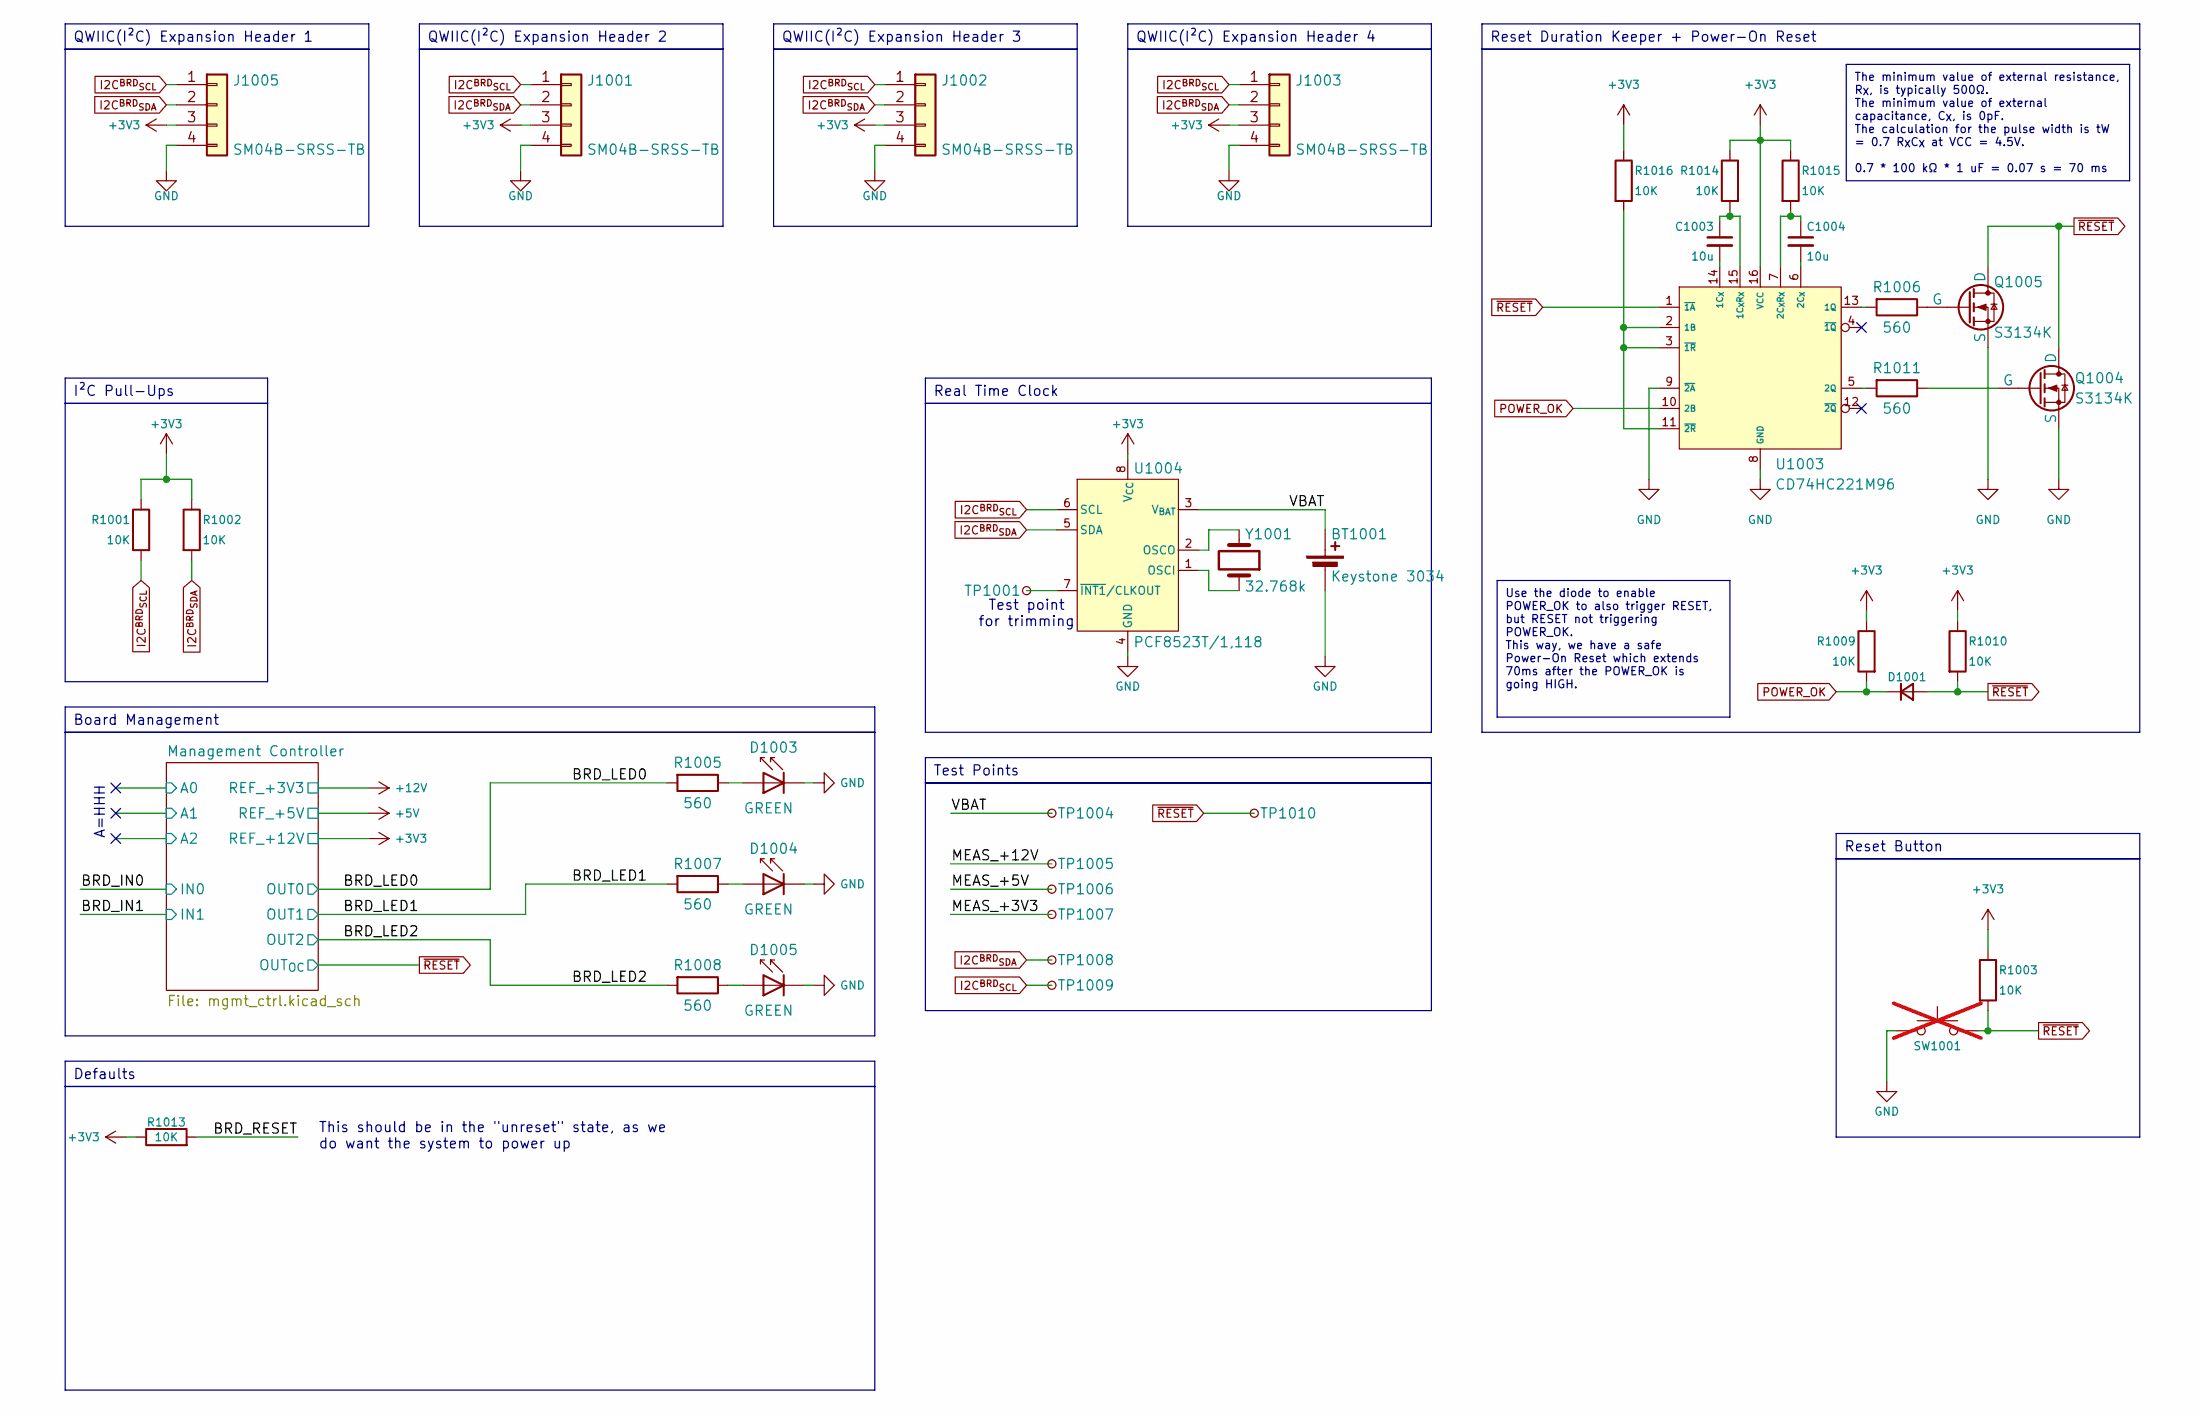
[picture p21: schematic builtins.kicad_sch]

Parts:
BT1001: Keystone 3034; BatteryHolder_Keystone_3034_1x20mm; Digikey Part No 36-3034-ND
C1003, C1004: 10u; C_0603_1608Metric; Digikey Part No 1276-1192-1-ND
D1001: Something Short-Circuit Safe; D_1206_3216Metric
D1003, D1004, D1005: GREEN; LED_0603_1608Metric
J1001, J1002, J1003, J1005: SM04B-SRSS-TB; Digikey Part No 455-SM04B-SRSS-TBCT-ND
Q1004, Q1005: S3134K; SOT-23; Digikey Part No 4786-S3134KCT-ND
R1001, R1002, R1003, R1009, R1010, R1013, R1014, R1015, R1016: 10K; R_0603_1608Metric; Digikey Part No 311-10.0KHRCT-ND
R1005, R1006, R1007, R1008, R1011: 560; R_0603_1608Metric; Digikey Part No RR08P560DCT-ND
SW1001: Button 12mm; SW_PUSH-12mm; not fitted
TP1001, TP1004, TP1005, TP1006, TP1007, TP1008, TP1009, TP1010: TestPoint_Small; TestPoint_Pad_D1.0mm
U1003: CD74HC221M96; SOIC-16_3.9x9.9mm_P1.27mm; Digikey Part No 296-17789-1-ND
U1004: PCF8523T/1,118; PCF8523T1,118; Digikey Part No 568-5306-2-ND
Y1001: 32.768k; Crystal_SMD_3215-2Pin_3.2x1.5mm; Digikey Part No 3155-32.768K12.5PI/3215ACT-ND

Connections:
+3V3: J1001.3, J1002.3, J1003.3, J1005.3, R1001.1, R1002.1, R1003.1, R1009.1, R1010.1, R1013.1, R1014.1, R1015.1, R1016.1, U1003.16 (VCC), U1004.8 (V_{CC}); also elsewhere on the board
/Builtins/BRD_LED0: R1005.2; also elsewhere on the board
/Builtins/BRD_LED1: R1007.2; also elsewhere on the board
/Builtins/BRD_LED2: R1008.2; also elsewhere on the board
/Builtins/BRD_RESET: R1013.2
/Builtins/MEAS_+3V3: TP1007.1
/Builtins/MEAS_+5V: TP1006.1
/Builtins/MEAS_+12V: TP1005.1
/Builtins/VBAT: BT1001.1 (+), TP1004.1, U1004.3 (V_{BAT})
GND: BT1001.2 (-), D1003.1 (K), D1004.1 (K), D1005.1 (K), J1001.4, J1002.4, J1003.4, J1005.4, Q1004.2 (S), Q1005.2 (S), SW1001.1, U1003.8 (GND), U1003.9 (~2A), U1004.4 (GND); also elsewhere on the board
I2C^{BRD}_{SCL}: J1001.1, J1002.1, J1003.1, J1005.1, R1001.2, TP1009.1, U1004.6 (SCL); also elsewhere on the board
I2C^{BRD}_{SDA}: J1001.2, J1002.2, J1003.2, J1005.2, R1002.2, TP1008.1, U1004.5 (SDA); also elsewhere on the board
unnamed: D1003.2 (A), R1005.1
unnamed: D1004.2 (A), R1007.1
unnamed: D1005.2 (A), R1008.1
unnamed: Q1004.1 (G), R1011.1
unnamed: Q1005.1 (G), R1006.1
unnamed: R1016.2, U1003.2 (1B), U1003.3 (~1R), U1003.11 (~2R)
unnamed: C1003.2, U1003.14 (1C_{X})
unnamed: C1003.1, R1014.2, U1003.15 (1C_{X}R_{X})
unnamed: R1006.2, U1003.13 (1Q)
unnamed: C1004.2, U1003.6 (2C_{X})
unnamed: C1004.1, R1015.2, U1003.7 (2C_{X}R_{X})
unnamed: R1011.2, U1003.5 (2Q)
unnamed: U1004.1 (OSCI), Y1001.1
unnamed: U1004.2 (OSCO), Y1001.2
unnamed: TP1001.1, U1004.7 (~INT1/CLKOUT)
POWER_OK: D1001.1 (K), R1009.2, U1003.10 (2B); also elsewhere on the board
~RESET: D1001.2 (A), Q1004.3 (D), Q1005.3 (D), R1003.2, R1010.2, SW1001.2, TP1010.1, U1003.1 (~1A); also elsewhere on the board

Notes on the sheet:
A=HHH
Test point for trimming
This should be in the "unreset" state, as we do want the system to power up
Real Time Clock
QWIIC(I²C) Expansion Header 2
QWIIC(I²C) Expansion Header 1
Use the diode to enable POWER_OK to also trigger RESET, but RESET not triggering POWER_OK. This way, we have a safe Power-On Reset which extends 70ms after the POWER_OK is going HIGH.
Reset Button
QWIIC(I²C) Expansion Header 4
Defaults
Board Management
Reset Duration Keeper + Power-On Reset
I²C Pull-Ups
QWIIC(I²C) Expansion Header 3
Test Points
The minimum value of external resistance, R_{X}, is typically 500Ω. The minimum value of external capacitance, C_{X}, is 0pF. The calculation for the pulse width is tW = 0.7 R_{X}C_{X} at VCC = 4.5V. 0.7 * 100 kΩ * 1 uF = 0.07 s = 70 ms

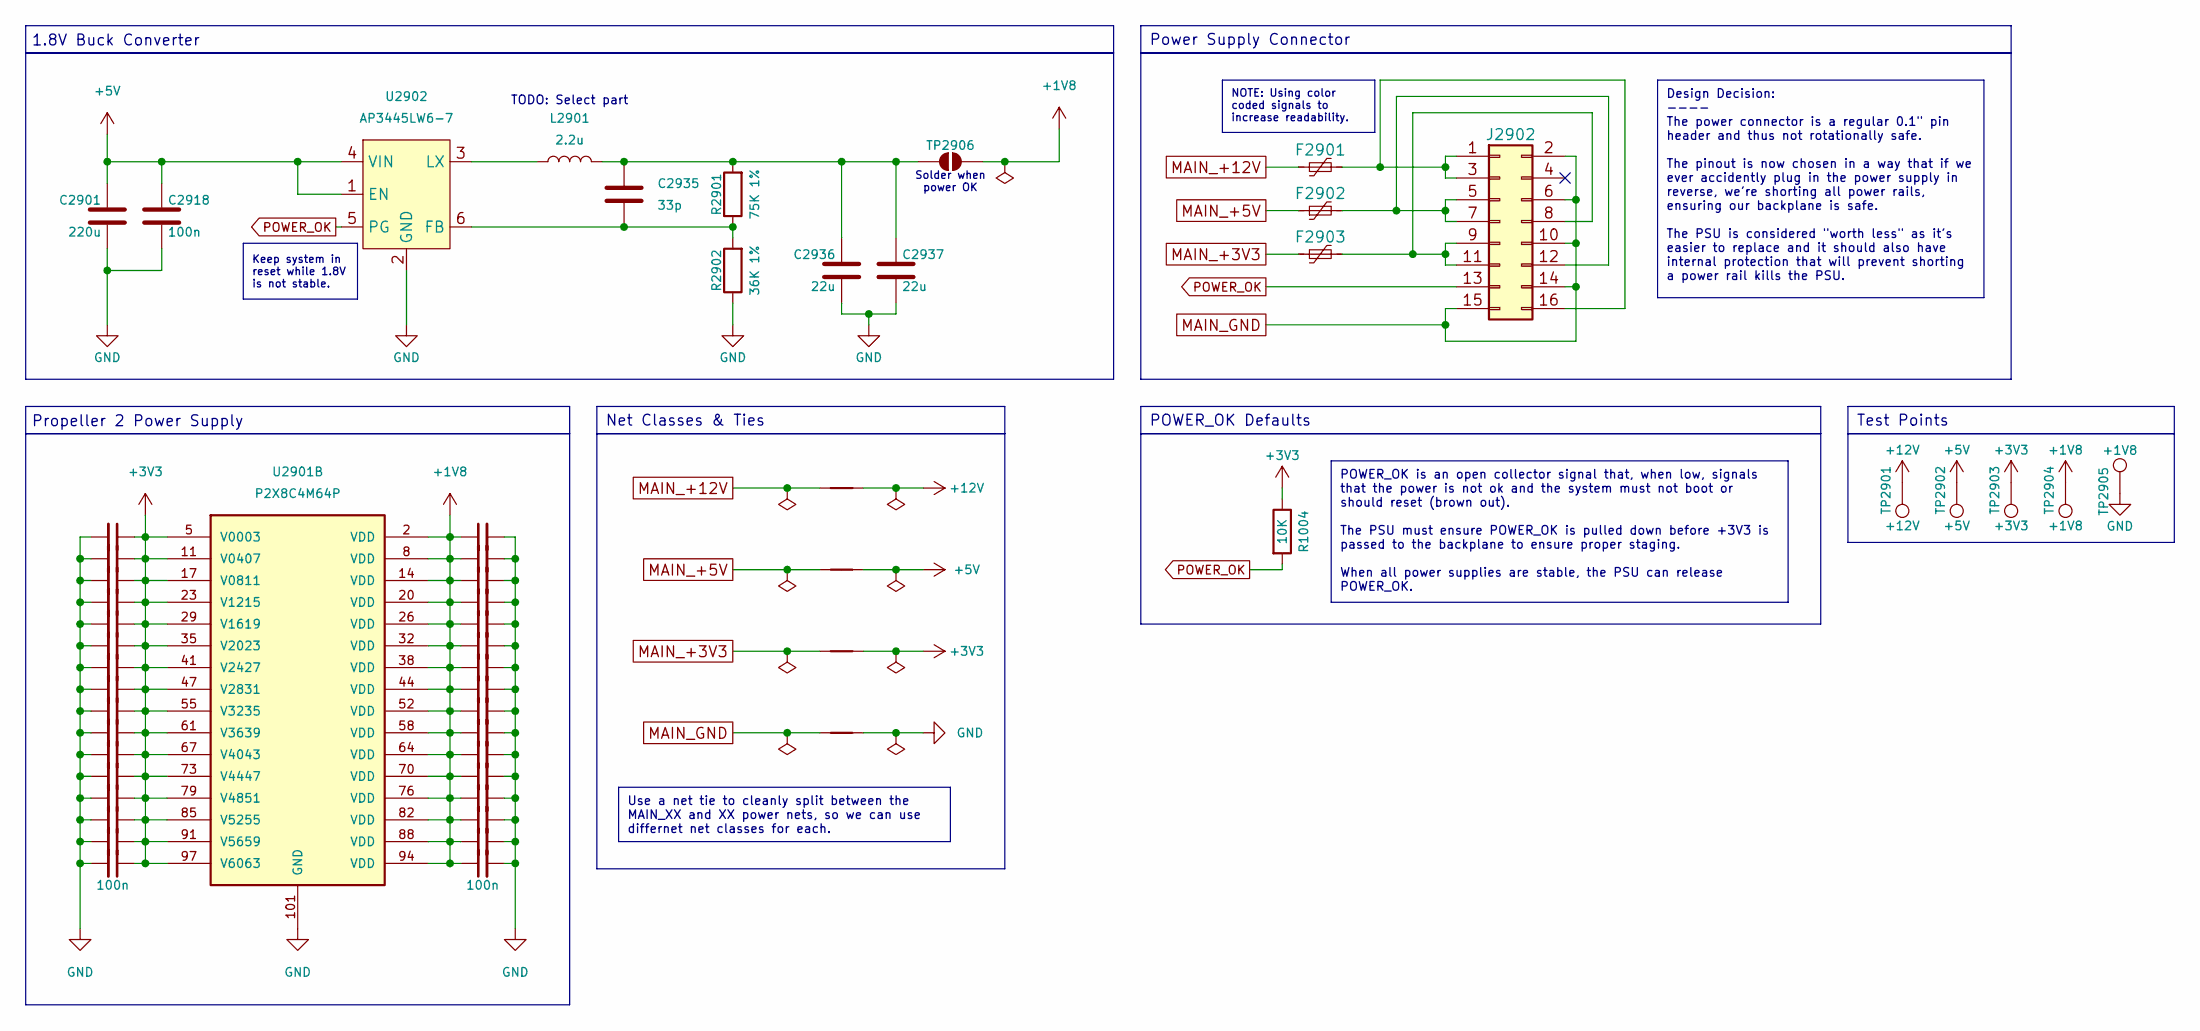
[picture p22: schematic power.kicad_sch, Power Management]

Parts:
C2901: 220u; C_1206_3216Metric; Digikey Part No 490-13970-1-ND
C2902, C2903, C2904, C2905, C2906, C2907, C2908, C2909, C2910, C2911, C2912, C2913, C2914, C2915, C2916, C2917, C2918, C2919, C2920, C2921, C2922, C2923, C2924, C2925, C2926, C2927, C2928, C2929, C2930, C2931, C2932, C2933, C2934: 100n; C_0603_1608Metric; Digikey Part No 399-C0603C104M4RACTUCT-ND
C2935: 33p; C_0603_1608Metric; Digikey Part No 1276-1070-1-ND
C2936, C2937: 22u; C_0603_1608Metric; Digikey Part No 1276-1274-1-ND
F2901, F2902, F2903: 0ZCF0400FF2A; Fuse_2920_7451Metric; Digikey Part No 5923-0ZCF0400FF2ACT-ND
J2902: Conn_02x08_Counter_Clockwise; PinHeader_1x16_P2.54mm_Vertical_SMD_Pin1Left
L2901: 2.2u
NT2904, NT2905, NT2906, NT2907: NetTie_2; NetTie-2_SMD_Pad0.5mm
R1004: 10K; R_0603_1608Metric; Digikey Part No 311-10.0KHRCT-ND
R2901: 75K 1%; R_0603_1608Metric; Digikey Part No RR08P75.0KDCT-ND
R2902: 36K 1%; R_0603_1608Metric; Digikey Part No P36KDBCT-ND
TP2901: +12V; TestPoint_Pad_D2.0mm
TP2902: +5V; TestPoint_Pad_D2.0mm
TP2903: +3V3; TestPoint_Pad_D2.0mm
TP2904, TP2905: +1V8; TestPoint_Pad_D2.0mm
TP2906: TestPoint_2Pole; SolderJumper-2_P1.3mm_Open_Pad1.0x1.5mm
U2901: P2X8C4M64P; QFP50P1600X1600X120-101N; Digikey Part No 149-P2X8C4M64P-ND
U2902: AP3445LW6-7; SOT-23-6; Digikey Part No AP3445LW6-7DICT-ND

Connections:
+1V8: C2919.1, C2920.1, C2921.1, C2922.1, C2923.1, C2924.1, C2925.1, C2926.1, C2927.1, C2928.1, C2929.1, C2930.1, C2931.1, C2932.1, C2933.1, C2934.1, TP2904.1, TP2906.2 (B), U2901.2 (VDD), U2901.8 (VDD), U2901.14 (VDD), U2901.20 (VDD), U2901.26 (VDD), U2901.32 (VDD), U2901.38 (VDD), U2901.44 (VDD), U2901.52 (VDD), U2901.58 (VDD), U2901.64 (VDD), U2901.70 (VDD), U2901.76 (VDD), U2901.82 (VDD), U2901.88 (VDD), U2901.94 (VDD)
+3V3: C2902.1, C2903.1, C2904.1, C2905.1, C2906.1, C2907.1, C2908.1, C2909.1, C2910.1, C2911.1, C2912.1, C2913.1, C2914.1, C2915.1, C2916.1, C2917.1, NT2907.2, R1004.1, TP2903.1, U2901.5 (V0003), U2901.11 (V0407), U2901.17 (V0811), U2901.23 (V1215), U2901.29 (V1619), U2901.35 (V2023), U2901.41 (V2427), U2901.47 (V2831), U2901.55 (V3235), U2901.61 (V3639), U2901.67 (V4043), U2901.73 (V4447), U2901.79 (V4851), U2901.85 (V5255), U2901.91 (V5659), U2901.97 (V6063); also elsewhere on the board
+5V: C2901.2, C2918.2, NT2906.2, TP2902.1, U2902.1 (EN), U2902.4 (VIN); also elsewhere on the board
+12V: NT2905.2, TP2901.1; also elsewhere on the board
GND: C2901.1, C2902.2, C2903.2, C2904.2, C2905.2, C2906.2, C2907.2, C2908.2, C2909.2, C2910.2, C2911.2, C2912.2, C2913.2, C2914.2, C2915.2, C2916.2, C2917.2, C2918.1, C2919.2, C2920.2, C2921.2, C2922.2, C2923.2, C2924.2, C2925.2, C2926.2, C2927.2, C2928.2, C2929.2, C2930.2, C2931.2, C2932.2, C2933.2, C2934.2, C2936.1, C2937.1, NT2904.2, R2902.1, TP2905.1, U2901.101 (GND), U2902.2 (GND); also elsewhere on the board
MAIN_+3V3: F2903.1, NT2907.1; also elsewhere on the board
MAIN_+5V: F2902.1, NT2906.1; also elsewhere on the board
MAIN_+12V: F2901.1, NT2905.1; also elsewhere on the board
MAIN_GND: J2902.2, J2902.6, J2902.10, J2902.14, J2902.15, NT2904.1
unnamed: F2901.2, J2902.1, J2902.3, J2902.16
unnamed: F2903.2, J2902.8, J2902.9, J2902.11
unnamed: F2902.2, J2902.5, J2902.7, J2902.12
unnamed: C2935.2, C2936.2, C2937.2, L2901.2, R2901.2, TP2906.1 (A)
unnamed: C2935.1, R2901.1, R2902.2, U2902.6 (FB)
unnamed: L2901.1, U2902.3 (LX)
POWER_OK: J2902.13, R1004.2, U2902.5 (PG); also elsewhere on the board

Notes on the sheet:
Solder when power OK
Propeller 2 Power Supply
1.8V Buck Converter
TODO: Select part
NOTE: Using color coded signals to increase readability.
Net Classes & Ties
POWER_OK is an open collector signal that, when low, signals that the power is not ok and the system must not boot or should reset (brown out). The PSU must ensure POWER_OK is pulled down before +3V3 is passed to the backplane to ensure proper staging. When all power supplies are stable, the PSU ca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
Use a net tie to cleanly split between the MAIN_XX and XX power nets, so we can use differnet net classes for each.
POWER_OK Defaults
Power Supply Connector
Design Decision: ---- The power connector is a regular 0.1" pin header and thus not rotationally safe. The pinout is now chosen in a way that if we ever accidently plug in the power supply in reverse, we're shorting all power rails, ensuring our backplane is safe. The PSU is considered "worth less"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
Test Points
Keep system in reset while 1.8V is not stable.

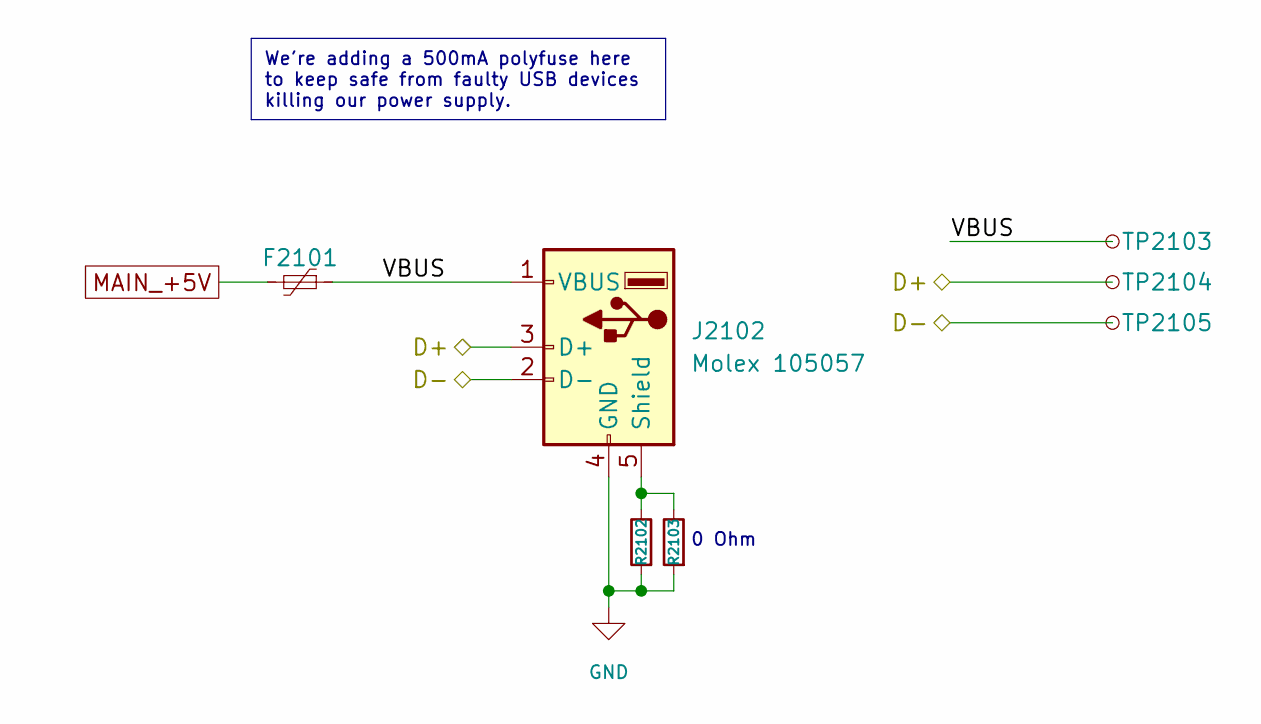
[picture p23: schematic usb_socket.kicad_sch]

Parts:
F2101: SMD1206B050TF/15; Fuse_1206_3216Metric; Digikey Part No 13-SMD1206B050TF/15TR-ND
J2102: Molex 105057; USB_A_Molex_105057_Vertical; Digikey Part No WM8672-ND
R2102, R2103: 0; R_0603_1608Metric; Digikey Part No 311-0.0GRCT-ND
TP2103, TP2104, TP2105: TestPoint_Small; TestPoint_Pad_D1.0mm

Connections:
/USB A Socket 1/VBUS: F2101.1, J2102.1 (VBUS), TP2103.1
/USB_{0}_D+: J2102.3 (D+), TP2104.1; also elsewhere on the board
/USB_{0}_D-: J2102.2 (D-), TP2105.1; also elsewhere on the board
GND: J2102.4 (GND), R2102.1, R2103.1; also elsewhere on the board
MAIN_+5V: F2101.2; also elsewhere on the board
unnamed: J2102.5 (Shield), R2102.2, R2103.2

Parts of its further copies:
F2201: SMD1206B050TF/15; Fuse_1206_3216Metric; Digikey Part No 13-SMD1206B050TF/15TR-ND
J2202: Molex 105057; USB_A_Molex_105057_Vertical; Digikey Part No WM8672-ND
R2202, R2203: 0; R_0603_1608Metric; Digikey Part No 311-0.0GRCT-ND
TP2203, TP2204, TP2205: TestPoint_Small; TestPoint_Pad_D1.0mm

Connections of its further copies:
/USB A Socket 2/VBUS: F2201.1, J2202.1 (VBUS), TP2203.1
/USB_{1}_D+: J2202.3 (D+), TP2204.1; also elsewhere on the board
/USB_{1}_D-: J2202.2 (D-), TP2205.1; also elsewhere on the board
GND: J2202.4 (GND), R2202.1, R2203.1; also elsewhere on the board
MAIN_+5V: F2201.2; also elsewhere on the board
unnamed: J2202.5 (Shield), R2202.2, R2203.2

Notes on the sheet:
0 Ohm
We're adding a 500mA polyfuse here to keep safe from faulty USB devices killing our power supply.

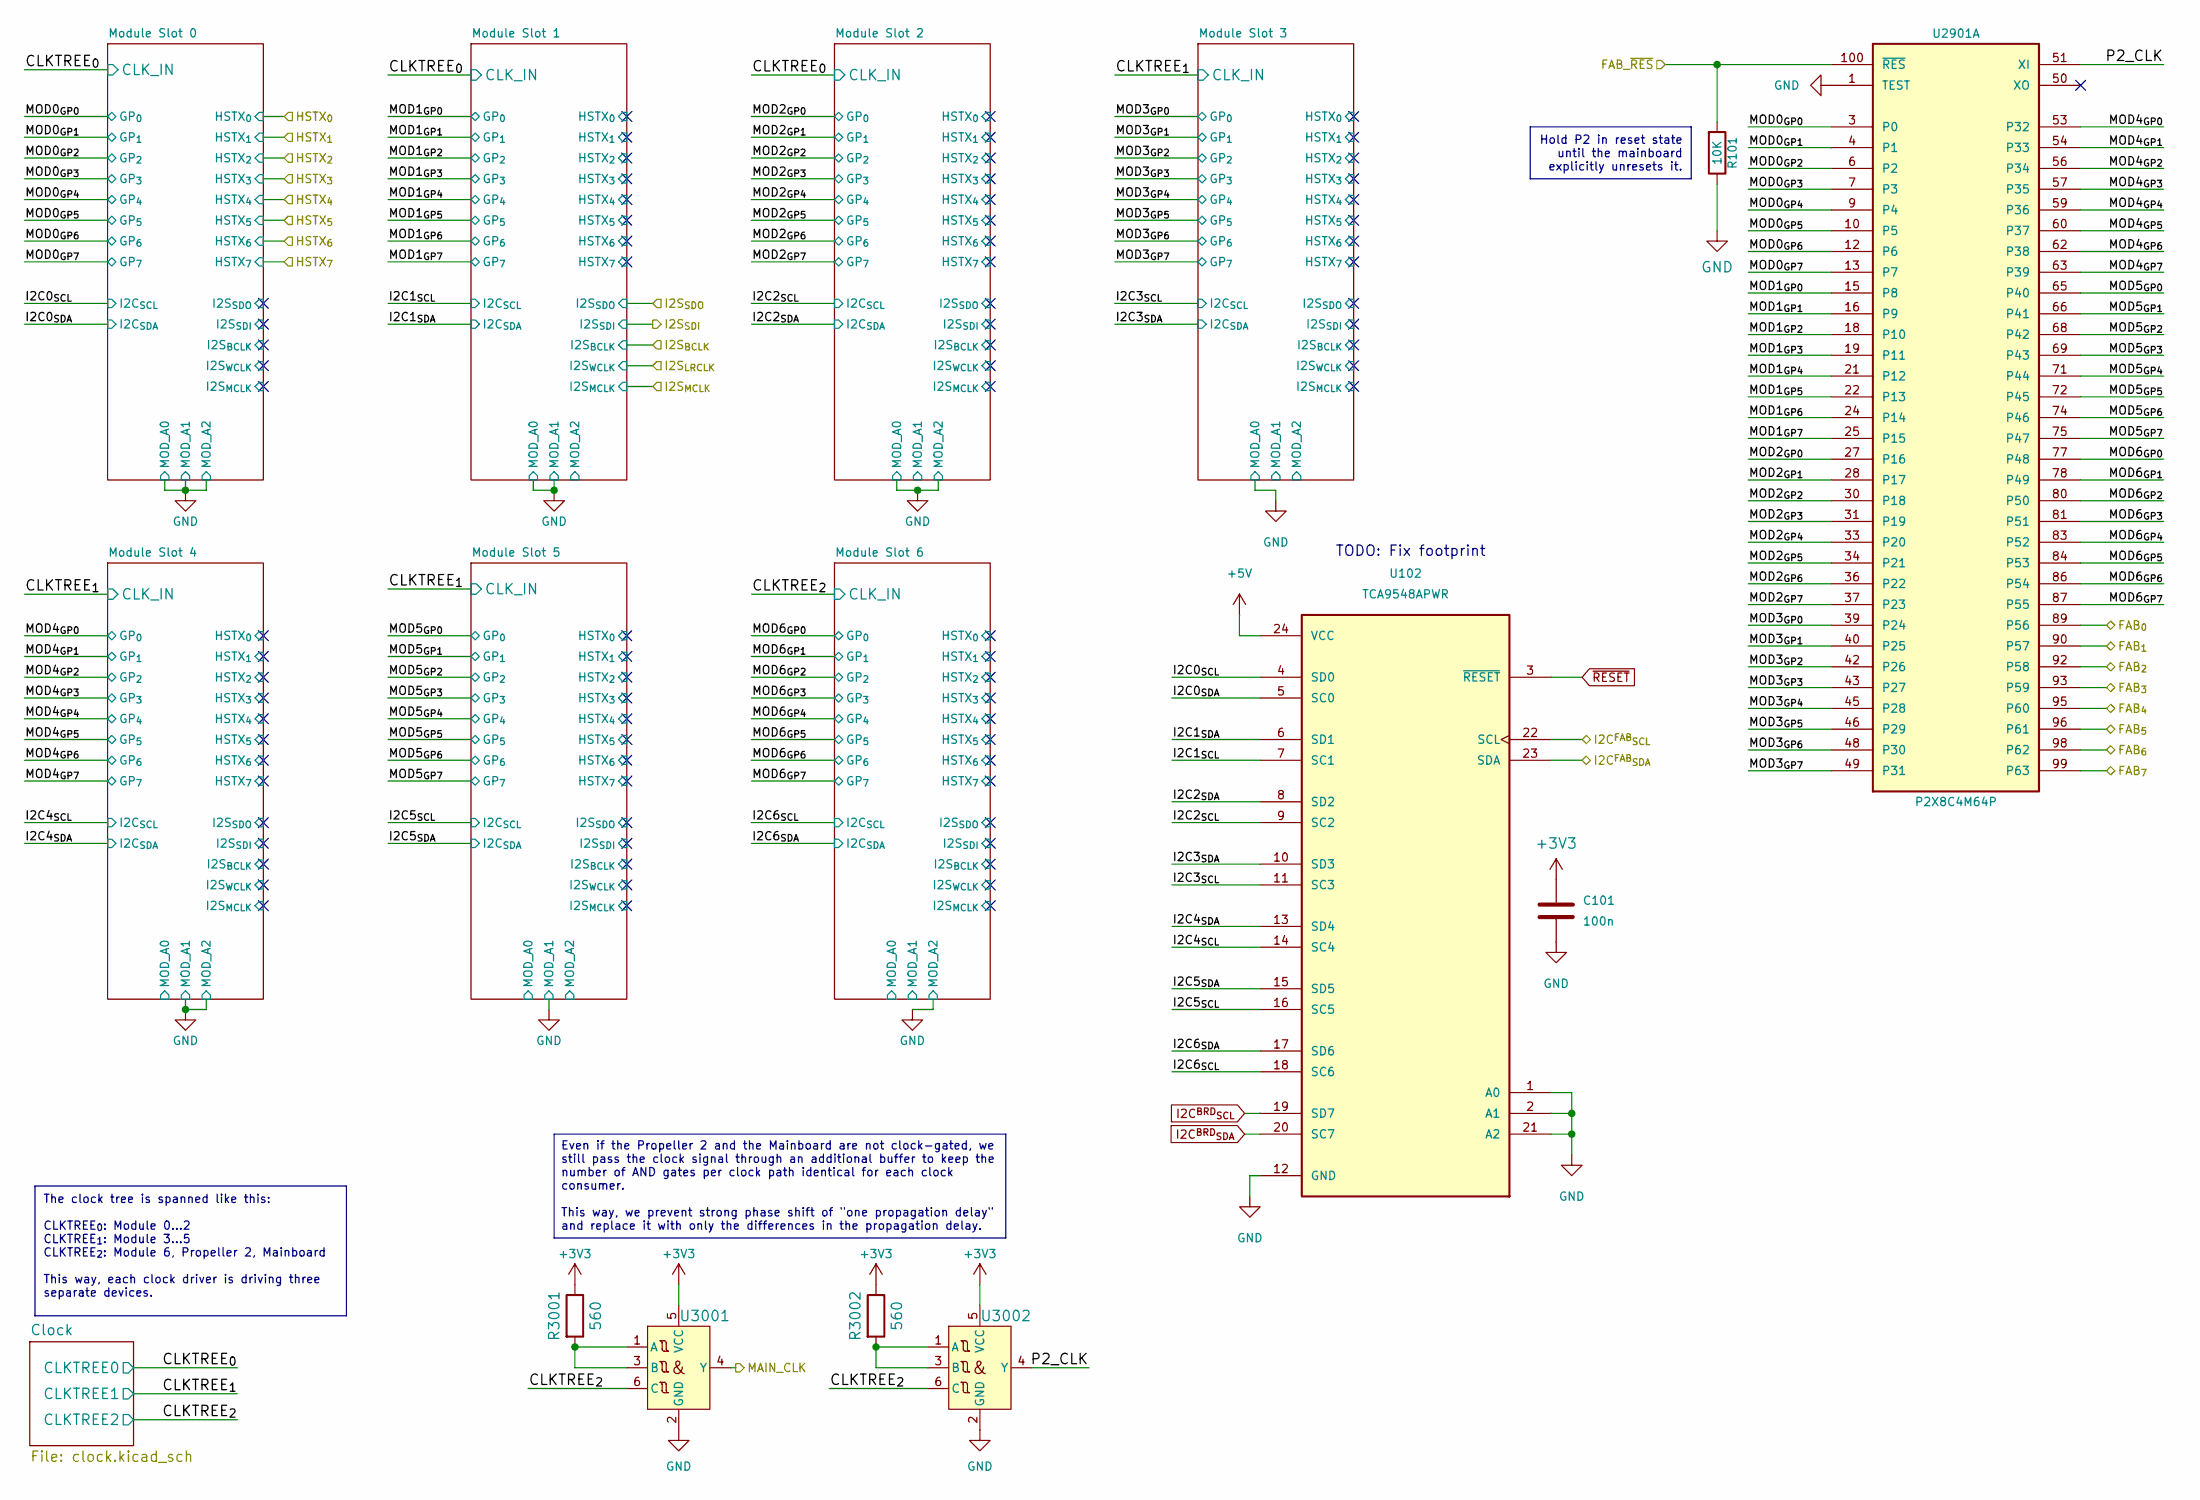
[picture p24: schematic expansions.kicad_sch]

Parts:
C101: 100n; C_0603_1608Metric; Digikey Part No 399-C0603C104M4RACTUCT-ND
R101: 10K; R_0603_1608Metric; Digikey Part No 311-10.0KHRCT-ND
R3001, R3002: 560; R_0603_1608Metric; Digikey Part No RR08P560DCT-ND
U102: TCA9548APWR; SOP65P640X120-24N; Digikey Part No 296-34905-1-ND
U2901: P2X8C4M64P; QFP50P1600X1600X120-101N; Digikey Part No 149-P2X8C4M64P-ND
U3001, U3002: NL17SZS11DFT2G-Q; SOT-363_SC-70-6; DigiKey Part No 488-NL17SZS11DFT2G-QCT-ND

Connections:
+3V3: C101.2, R3001.1, R3002.1, U3001.5 (VCC), U3002.5 (VCC); also elsewhere on the board
/Expansions/CLKTREE_{2}: U3001.6 (C), U3002.6 (C); also elsewhere on the board
/Expansions/FAB_{0}: U2901.89 (P56); also elsewhere on the board
/Expansions/FAB_{1}: U2901.90 (P57); also elsewhere on the board
/Expansions/FAB_{2}: U2901.92 (P58); also elsewhere on the board
/Expansions/FAB_{3}: U2901.93 (P59); also elsewhere on the board
/Expansions/FAB_{4}: U2901.95 (P60); also elsewhere on the board
/Expansions/FAB_{5}: U2901.96 (P61); also elsewhere on the board
/Expansions/FAB_{6}: U2901.98 (P62); also elsewhere on the board
/Expansions/FAB_{7}: U2901.99 (P63); also elsewhere on the board
/Expansions/FAB_~RES: R101.2, U2901.100 (~RES); also elsewhere on the board
/Expansions/MAIN_CLK: U3001.4 (Y); also elsewhere on the board
/Expansions/MOD0_{GP0}: U2901.3 (P0); also elsewhere on the board
/Expansions/MOD0_{GP1}: U2901.4 (P1); also elsewhere on the board
/Expansions/MOD0_{GP2}: U2901.6 (P2); also elsewhere on the board
/Expansions/MOD0_{GP3}: U2901.7 (P3); also elsewhere on the board
/Expansions/MOD0_{GP4}: U2901.9 (P4); also elsewhere on the board
/Expansions/MOD0_{GP5}: U2901.10 (P5); also elsewhere on the board
/Expansions/MOD0_{GP6}: U2901.12 (P6); also elsewhere on the board
/Expansions/MOD0_{GP7}: U2901.13 (P7); also elsewhere on the board
/Expansions/MOD1_{GP0}: U2901.15 (P8); also elsewhere on the board
/Expansions/MOD1_{GP1}: U2901.16 (P9); also elsewhere on the board
/Expansions/MOD1_{GP2}: U2901.18 (P10); also elsewhere on the board
/Expansions/MOD1_{GP3}: U2901.19 (P11); also elsewhere on the board
/Expansions/MOD1_{GP4}: U2901.21 (P12); also elsewhere on the board
/Expansions/MOD1_{GP5}: U2901.22 (P13); also elsewhere on the board
/Expansions/MOD1_{GP6}: U2901.24 (P14); also elsewhere on the board
/Expansions/MOD1_{GP7}: U2901.25 (P15); also elsewhere on the board
/Expansions/MOD2_{GP0}: U2901.27 (P16); also elsewhere on the board
/Expansions/MOD2_{GP1}: U2901.28 (P17); also elsewhere on the board
/Expansions/MOD2_{GP2}: U2901.30 (P18); also elsewhere on the board
/Expansions/MOD2_{GP3}: U2901.31 (P19); also elsewhere on the board
/Expansions/MOD2_{GP4}: U2901.33 (P20); also elsewhere on the board
/Expansions/MOD2_{GP5}: U2901.34 (P21); also elsewhere on the board
/Expansions/MOD2_{GP6}: U2901.36 (P22); also elsewhere on the board
/Expansions/MOD2_{GP7}: U2901.37 (P23); also elsewhere on the board
/Expansions/MOD3_{GP0}: U2901.39 (P24); also elsewhere on the board
/Expansions/MOD3_{GP1}: U2901.40 (P25); also elsewhere on the board
/Expansions/MOD3_{GP2}: U2901.42 (P26); also elsewhere on the board
/Expansions/MOD3_{GP3}: U2901.43 (P27); also elsewhere on the board
/Expansions/MOD3_{GP4}: U2901.45 (P28); also elsewhere on the board
/Expansions/MOD3_{GP5}: U2901.46 (P29); also elsewhere on the board
/Expansions/MOD3_{GP6}: U2901.48 (P30); also elsewhere on the board
/Expansions/MOD3_{GP7}: U2901.49 (P31); also elsewhere on the board
/Expansions/MOD4_{GP0}: U2901.53 (P32); also elsewhere on the board
/Expansions/MOD4_{GP1}: U2901.54 (P33); also elsewhere on the board
/Expansions/MOD4_{GP2}: U2901.56 (P34); also elsewhere on the board
/Expansions/MOD4_{GP3}: U2901.57 (P35); also elsewhere on the board
/Expansions/MOD4_{GP4}: U2901.59 (P36); also elsewhere on the board
/Expansions/MOD4_{GP5}: U2901.60 (P37); also elsewhere on the board
/Expansions/MOD4_{GP6}: U2901.62 (P38); also elsewhere on the board
/Expansions/MOD4_{GP7}: U2901.63 (P39); also elsewhere on the board
/Expansions/MOD5_{GP0}: U2901.65 (P40); also elsewhere on the board
/Expansions/MOD5_{GP1}: U2901.66 (P41); also elsewhere on the board
/Expansions/MOD5_{GP2}: U2901.68 (P42); also elsewhere on the board
/Expansions/MOD5_{GP3}: U2901.69 (P43); also elsewhere on the board
/Expansions/MOD5_{GP4}: U2901.71 (P44); also elsewhere on the board
/Expansions/MOD5_{GP5}: U2901.72 (P45); also elsewhere on the board
/Expansions/MOD5_{GP6}: U2901.74 (P46); also elsewhere on the board
/Expansions/MOD5_{GP7}: U2901.75 (P47); also elsewhere on the board
/Expansions/MOD6_{GP0}: U2901.77 (P48); also elsewhere on the board
/Expansions/MOD6_{GP1}: U2901.78 (P49); also elsewhere on the board
/Expansions/MOD6_{GP2}: U2901.80 (P50); also elsewhere on the board
/Expansions/MOD6_{GP3}: U2901.81 (P51); also elsewhere on the board
/Expansions/MOD6_{GP4}: U2901.83 (P52); also elsewhere on the board
/Expansions/MOD6_{GP5}: U2901.84 (P53); also elsewhere on the board
/Expansions/MOD6_{GP6}: U2901.86 (P54); also elsewhere on the board
/Expansions/MOD6_{GP7}: U2901.87 (P55); also elsewhere on the board
/Expansions/P2_CLK: U2901.51 (XI), U3002.4 (Y)
GND: C101.1, R101.1, U102.1 (A0), U102.2 (A1), U102.12 (GND), U102.21 (A2), U2901.1 (TEST), U3001.2 (GND), U3002.2 (GND); also elsewhere on the board
unnamed: R3001.2, U3001.1 (A), U3001.3 (B)
unnamed: R3002.2, U3002.1 (A), U3002.3 (B)

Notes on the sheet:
TODO: Fix footprint
Even if the Propeller 2 and the Mainboard are not clock-gated, we still pass the clock signal through an additional buffer to keep the number of AND gates per clock path identical for each clock consumer. This way, we prevent strong phase shift of "one propagation delay" and replace it with only th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
Hold P2 in reset state until the mainboard explicitly unresets it.
The clock tree is spanned like this: CLKTREE_{0}: Module 0…2 CLKTREE_{1}: Module 3…5 CLKTREE_{2}: Module 6, Propeller 2, Mainboard This way, each clock driver is driving three separate devices.

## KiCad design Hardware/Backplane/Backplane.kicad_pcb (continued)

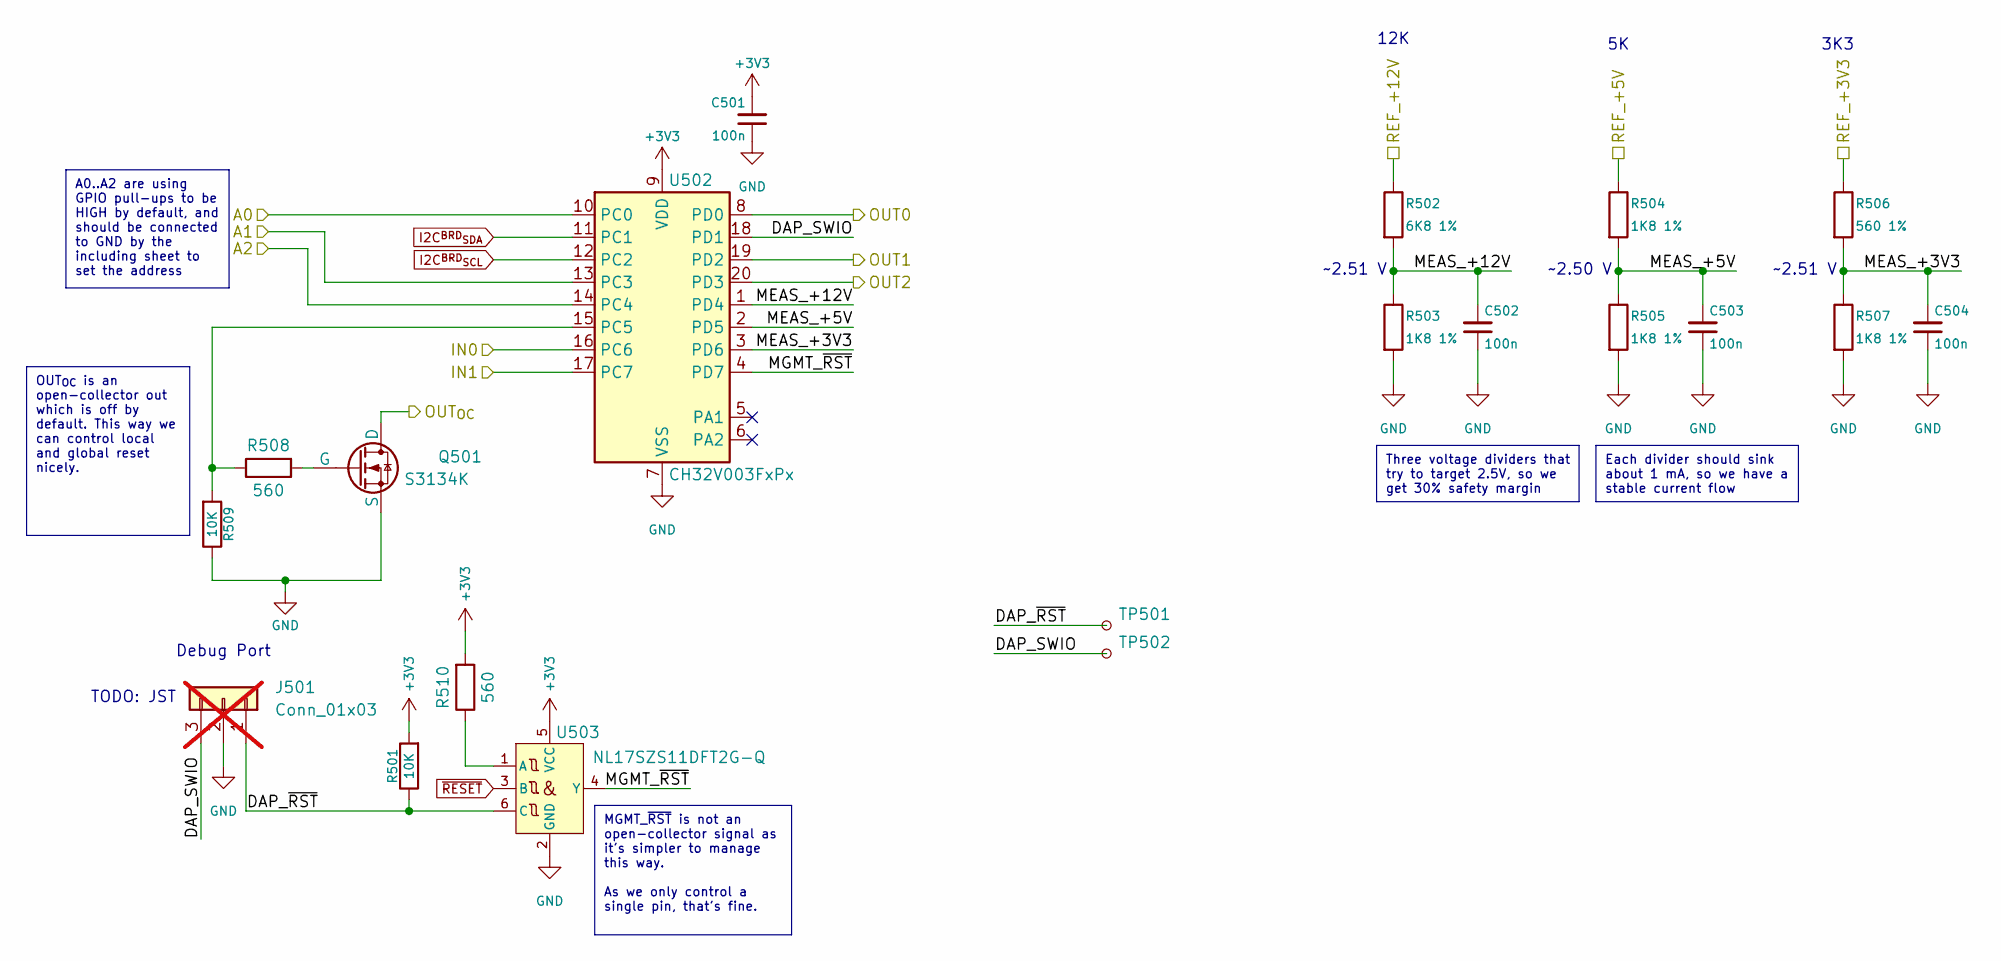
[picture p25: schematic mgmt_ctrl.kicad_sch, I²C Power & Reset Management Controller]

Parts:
C501, C502, C503, C504: 100n; C_0603_1608Metric; Digikey Part No 399-C0603C104M4RACTUCT-ND
J501: Conn_01x03; Molex_PicoBlade_53047-0310_1x03_P1.25mm_Vertical; Digikey Part No WM1732-ND; not fitted
Q501: S3134K; SOT-23; Digikey Part No 4786-S3134KCT-ND
R501, R509: 10K; R_0603_1608Metric; Digikey Part No 311-10.0KHRCT-ND
R502: 6K8 1%; R_0603_1608Metric; Digikey Part No RG16P6.8KBCT-ND
R503, R504, R505, R507: 1K8 1%; R_0603_1608Metric; Digikey Part No RG16P1.8KBCT-ND
R506: 560 1%; R_0603_1608Metric; Digikey Part No RR08P560DCT-ND
R508, R510: 560; R_0603_1608Metric; Digikey Part No RR08P560DCT-ND
TP501, TP502: TestPoint_Small; TestPoint_Pad_D1.0mm
U502: CH32V003FxPx; TSSOP-20_4.4x6.5mm_P0.65mm; Digikey Part No 1188-SMDICCH32V003F4P6-ND
U503: NL17SZS11DFT2G-Q; SOT-363_SC-70-6; DigiKey Part No 488-NL17SZS11DFT2G-QCT-ND

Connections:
+3V3: C501.2, R501.2, R510.2, U502.9 (VDD), U503.5 (VCC); also elsewhere on the board
/Expansions/Module Slot 0/MOD_+3V3: R506.1; also elsewhere on the board
/Expansions/Module Slot 0/MOD_+5V: R504.1; also elsewhere on the board
/Expansions/Module Slot 0/MOD_+12V: R502.1; also elsewhere on the board
/Expansions/Module Slot 0/Management Controller/DAP_SWIO: J501.3, TP502.1, U502.18 (PD1)
/Expansions/Module Slot 0/Management Controller/DAP_~RST: J501.1, R501.1, TP501.1, U503.6 (C)
/Expansions/Module Slot 0/Management Controller/IN1: U502.17 (PC7)
/Expansions/Module Slot 0/Management Controller/MEAS_+3V3: C504.2, R506.2, R507.1, U502.3 (PD6)
/Expansions/Module Slot 0/Management Controller/MEAS_+5V: C503.2, R504.2, R505.1, U502.2 (PD5)
/Expansions/Module Slot 0/Management Controller/MEAS_+12V: C502.2, R502.2, R503.1, U502.1 (PD4)
/Expansions/Module Slot 0/Management Controller/MGMT_~RST: U502.4 (PD7), U503.4 (Y)
/Expansions/Module Slot 0/Management Controller/OUT2: U502.20 (PD3)
/Expansions/Module Slot 0/POWER_ON: U502.8 (PD0); also elsewhere on the board
/Expansions/Module Slot 0/~CARD_RESET: Q501.3 (D); also elsewhere on the board
/Expansions/Module Slot 0/~MOD_CLK_EN: U502.19 (PD2); also elsewhere on the board
/Expansions/Module Slot 0/~PRESENT: U502.16 (PC6); also elsewhere on the board
GND: C501.1, C502.1, C503.1, C504.1, J501.2, Q501.2 (S), R503.2, R505.2, R507.2, R509.1, U502.7 (VSS), U502.10 (PC0), U502.13 (PC3), U502.14 (PC4), U503.2 (GND); also elsewhere on the board
I2C^{BRD}_{SCL}: U502.12 (PC2); also elsewhere on the board
I2C^{BRD}_{SDA}: U502.11 (PC1); also elsewhere on the board
unnamed: Q501.1 (G), R508.2
unnamed: R508.1, R509.2, U502.15 (PC5)
unnamed: R510.1, U503.1 (A)
~RESET: U503.3 (B); also elsewhere on the board

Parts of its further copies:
C201, C202, C203, C801, C802, C803, C804, C1201, C1202, C1203, C1204, C1501, C1502, C1503, C1504, C1801, C1802, C1803, C1804, C2002, C2301, C2302, C2303, C2304, C2601, C2602, C2603, C2604: 100n; C_0603_1608Metric; Digikey Part No 399-C0603C104M4RACTUCT-ND
J801, J1201, J1501, J1801, J2002, J2301, J2601: Conn_01x03; Molex_PicoBlade_53047-0310_1x03_P1.25mm_Vertical; Digikey Part No WM1732-ND; not fitted
Q801, Q1201, Q1501, Q1801, Q2001, Q2301, Q2601: S3134K; SOT-23; Digikey Part No 4786-S3134KCT-ND
R214, R802, R1202, R1502, R1802, R2302, R2602: 6K8 1%; R_0603_1608Metric; Digikey Part No RG16P6.8KBCT-ND
R215, R216, R217, R219, R803, R804, R805, R807, R1203, R1204, R1205, R1207, R1503, R1504, R1505, R1507, R1803, R1804, R1805, R1807, R2303, R2304, R2305, R2307, R2603, R2604, R2605, R2607: 1K8 1%; R_0603_1608Metric; Digikey Part No RG16P1.8KBCT-ND
R218, R806, R1206, R1506, R1806, R2306, R2606: 560 1%; R_0603_1608Metric; Digikey Part No RR08P560DCT-ND
R801, R809, R1201, R1209, R1501, R1509, R1801, R1809, R2001, R2003, R2301, R2309, R2601, R2609: 10K; R_0603_1608Metric; Digikey Part No 311-10.0KHRCT-ND
R808, R810, R1208, R1210, R1508, R1510, R1808, R1810, R2002, R2004, R2308, R2310, R2608, R2610: 560; R_0603_1608Metric; Digikey Part No RR08P560DCT-ND
TP801, TP802, TP1201, TP1202, TP1501, TP1502, TP1801, TP1802, TP2003, TP2004, TP2301, TP2302, TP2601, TP2602: TestPoint_Small; TestPoint_Pad_D1.0mm
U802, U1202, U1502, U1802, U2004, U2302, U2602: CH32V003FxPx; TSSOP-20_4.4x6.5mm_P0.65mm; Digikey Part No 1188-SMDICCH32V003F4P6-ND
U803, U1203, U1503, U1803, U2001, U2303, U2603: NL17SZS11DFT2G-Q; SOT-363_SC-70-6; DigiKey Part No 488-NL17SZS11DFT2G-QCT-ND

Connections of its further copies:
+3V3: C801.2, C1201.2, C1501.2, C1801.2, C2002.2, C2301.2, C2601.2, R214.1, R801.2, R810.2, R1201.2, R1210.2, R1501.2, R1510.2, R1801.2, R1810.2, R2001.2, R2004.2, R2301.2, R2310.2, R2601.2, R2610.2, U802.9 (VDD), U803.5 (VCC), U1202.9 (VDD), U1203.5 (VCC), U1502.9 (VDD), U1503.5 (VCC), U1802.9 (VDD), U1803.5 (VCC), U2001.5 (VCC), U2004.9 (VDD), U2302.9 (VDD), U2303.5 (VCC), U2602.9 (VDD), U2603.5 (VCC); also elsewhere on the board
+5V: R216.1; also elsewhere on the board
+12V: R218.1; also elsewhere on the board
/Builtins/BRD_IN0: U2004.16 (PC6)
/Builtins/BRD_IN1: U2004.17 (PC7)
/Builtins/BRD_LED0: U2004.8 (PD0); also elsewhere on the board
/Builtins/BRD_LED1: U2004.19 (PD2); also elsewhere on the board
/Builtins/BRD_LED2: U2004.20 (PD3); also elsewhere on the board
/Builtins/Management Controller/A0: U2004.10 (PC0)
/Builtins/Management Controller/A1: U2004.13 (PC3)
/Builtins/Management Controller/A2: U2004.14 (PC4)
/Builtins/Management Controller/DAP_SWIO: J2002.3, TP2004.1, U2004.18 (PD1)
/Builtins/Management Controller/DAP_~RST: J2002.1, R2001.1, TP2003.1, U2001.6 (C)
/Builtins/Management Controller/MEAS_+3V3: C203.2, R218.2, R219.1, U2004.3 (PD6)
/Builtins/Management Controller/MEAS_+5V: C202.2, R216.2, R217.1, U2004.2 (PD5)
/Builtins/Management Controller/MEAS_+12V: C201.2, R214.2, R215.1, U2004.1 (PD4)
/Builtins/Management Controller/MGMT_~RST: U2001.4 (Y), U2004.4 (PD7)
/Expansions/Module Slot 1/MOD_+3V3: R806.1; also elsewhere on the board
/Expansions/Module Slot 1/MOD_+5V: R804.1; also elsewhere on the board
/Expansions/Module Slot 1/MOD_+12V: R802.1; also elsewhere on the board
/Expansions/Module Slot 1/MOD_A2: U802.14 (PC4)
/Expansions/Module Slot 1/Management Controller/DAP_SWIO: J801.3, TP802.1, U802.18 (PD1)
/Expansions/Module Slot 1/Management Controller/DAP_~RST: J801.1, R801.1, TP801.1, U803.6 (C)
/Expansions/Module Slot 1/Management Controller/IN1: U802.17 (PC7)
/Expansions/Module Slot 1/Management Controller/MEAS_+3V3: C804.2, R806.2, R807.1, U802.3 (PD6)
/Expansions/Module Slot 1/Management Controller/MEAS_+5V: C803.2, R804.2, R805.1, U802.2 (PD5)
/Expansions/Module Slot 1/Management Controller/MEAS_+12V: C802.2, R802.2, R803.1, U802.1 (PD4)
/Expansions/Module Slot 1/Management Controller/MGMT_~RST: U802.4 (PD7), U803.4 (Y)
/Expansions/Module Slot 1/Management Controller/OUT2: U802.20 (PD3)
/Expansions/Module Slot 1/POWER_ON: U802.8 (PD0); also elsewhere on the board
/Expansions/Module Slot 1/~CARD_RESET: Q801.3 (D); also elsewhere on the board
/Expansions/Module Slot 1/~MOD_CLK_EN: U802.19 (PD2); also elsewhere on the board
/Expansions/Module Slot 1/~PRESENT: U802.16 (PC6); also elsewhere on the board
/Expansions/Module Slot 2/MOD_+3V3: R1206.1; also elsewhere on the board
/Expansions/Module Slot 2/MOD_+5V: R1204.1; also elsewhere on the board
/Expansions/Module Slot 2/MOD_+12V: R1202.1; also elsewhere on the board
/Expansions/Module Slot 2/MOD_A1: U1202.13 (PC3)
/Expansions/Module Slot 2/Management Controller/DAP_SWIO: J1201.3, TP1202.1, U1202.18 (PD1)
/Expansions/Module Slot 2/Management Controller/DAP_~RST: J1201.1, R1201.1, TP1201.1, U1203.6 (C)
/Expansions/Module Slot 2/Management Controller/IN1: U1202.17 (PC7)
/Expansions/Module Slot 2/Management Controller/MEAS_+3V3: C1204.2, R1206.2, R1207.1, U1202.3 (PD6)
/Expansions/Module Slot 2/Management Controller/MEAS_+5V: C1203.2, R1204.2, R1205.1, U1202.2 (PD5)
/Expansions/Module Slot 2/Management Controller/MEAS_+12V: C1202.2, R1202.2, R1203.1, U1202.1 (PD4)
/Expansions/Module Slot 2/Management Controller/MGMT_~RST: U1202.4 (PD7), U1203.4 (Y)
/Expansions/Module Slot 2/Management Controller/OUT2: U1202.20 (PD3)
/Expansions/Module Slot 2/POWER_ON: U1202.8 (PD0); also elsewhere on the board
/Expansions/Module Slot 2/~CARD_RESET: Q1201.3 (D); also elsewhere on the board
/Expansions/Module Slot 2/~MOD_CLK_EN: U1202.19 (PD2); also elsewhere on the board
/Expansions/Module Slot 2/~PRESENT: U1202.16 (PC6); also elsewhere on the board
/Expansions/Module Slot 3/MOD_+3V3: R1506.1; also elsewhere on the board
/Expansions/Module Slot 3/MOD_+5V: R1504.1; also elsewhere on the board
/Expansions/Module Slot 3/MOD_+12V: R1502.1; also elsewhere on the board
/Expansions/Module Slot 3/MOD_A1: U1502.13 (PC3)
/Expansions/Module Slot 3/MOD_A2: U1502.14 (PC4)
/Expansions/Module Slot 3/Management Controller/DAP_SWIO: J1501.3, TP1502.1, U1502.18 (PD1)
/Expansions/Module Slot 3/Management Controller/DAP_~RST: J1501.1, R1501.1, TP1501.1, U1503.6 (C)
/Expansions/Module Slot 3/Management Controller/IN1: U1502.17 (PC7)
/Expansions/Module Slot 3/Management Controller/MEAS_+3V3: C1504.2, R1506.2, R1507.1, U1502.3 (PD6)
/Expansions/Module Slot 3/Management Controller/MEAS_+5V: C1503.2, R1504.2, R1505.1, U1502.2 (PD5)
/Expansions/Module Slot 3/Management Controller/MEAS_+12V: C1502.2, R1502.2, R1503.1, U1502.1 (PD4)
/Expansions/Module Slot 3/Management Controller/MGMT_~RST: U1502.4 (PD7), U1503.4 (Y)
/Expansions/Module Slot 3/Management Controller/OUT2: U1502.20 (PD3)
/Expansions/Module Slot 3/POWER_ON: U1502.8 (PD0); also elsewhere on the board
/Expansions/Module Slot 3/~CARD_RESET: Q1501.3 (D); also elsewhere on the board
/Expansions/Module Slot 3/~MOD_CLK_EN: U1502.19 (PD2); also elsewhere on the board
/Expansions/Module Slot 3/~PRESENT: U1502.16 (PC6); also elsewhere on the board
/Expansions/Module Slot 4/MOD_+3V3: R1806.1; also elsewhere on the board
/Expansions/Module Slot 4/MOD_+5V: R1804.1; also elsewhere on the board
/Expansions/Module Slot 4/MOD_+12V: R1802.1; also elsewhere on the board
/Expansions/Module Slot 4/MOD_A0: U1802.10 (PC0)
/Expansions/Module Slot 4/Management Controller/DAP_SWIO: J1801.3, TP1802.1, U1802.18 (PD1)
/Expansions/Module Slot 4/Management Controller/DAP_~RST: J1801.1, R1801.1, TP1801.1, U1803.6 (C)
/Expansions/Module Slot 4/Management Controller/IN1: U1802.17 (PC7)
/Expansions/Module Slot 4/Management Controller/MEAS_+3V3: C1804.2, R1806.2, R1807.1, U1802.3 (PD6)
/Expansions/Module Slot 4/Management Controller/MEAS_+5V: C1803.2, R1804.2, R1805.1, U1802.2 (PD5)
/Expansions/Module Slot 4/Management Controller/MEAS_+12V: C1802.2, R1802.2, R1803.1, U1802.1 (PD4)
/Expansions/Module Slot 4/Management Controller/MGMT_~RST: U1802.4 (PD7), U1803.4 (Y)
/Expansions/Module Slot 4/Management Controller/OUT2: U1802.20 (PD3)
/Expansions/Module Slot 4/POWER_ON: U1802.8 (PD0); also elsewhere on the board
/Expansions/Module Slot 4/~CARD_RESET: Q1801.3 (D); also elsewhere on the board
/Expansions/Module Slot 4/~MOD_CLK_EN: U1802.19 (PD2); also elsewhere on the board
/Expansions/Module Slot 4/~PRESENT: U1802.16 (PC6); also elsewhere on the board
/Expansions/Module Slot 5/MOD_+3V3: R2306.1; also elsewhere on the board
/Expansions/Module Slot 5/MOD_+5V: R2304.1; also elsewhere on the board
/Expansions/Module Slot 5/MOD_+12V: R2302.1; also elsewhere on the board
/Expansions/Module Slot 5/MOD_A0: U2302.10 (PC0)
/Expansions/Module Slot 5/MOD_A2: U2302.14 (PC4)
/Expansions/Module Slot 5/Management Controller/DAP_SWIO: J2301.3, TP2302.1, U2302.18 (PD1)
/Expansions/Module Slot 5/Management Controller/DAP_~RST: J2301.1, R2301.1, TP2301.1, U2303.6 (C)
/Expansions/Module Slot 5/Management Controller/IN1: U2302.17 (PC7)
/Expansions/Module Slot 5/Management Controller/MEAS_+3V3: C2304.2, R2306.2, R2307.1, U2302.3 (PD6)
/Expansions/Module Slot 5/Management Controller/MEAS_+5V: C2303.2, R2304.2, R2305.1, U2302.2 (PD5)
/Expansions/Module Slot 5/Management Controller/MEAS_+12V: C2302.2, R2302.2, R2303.1, U2302.1 (PD4)
/Expansions/Module Slot 5/Management Controller/MGMT_~RST: U2302.4 (PD7), U2303.4 (Y)
/Expansions/Module Slot 5/Management Controller/OUT2: U2302.20 (PD3)
/Expansions/Module Slot 5/POWER_ON: U2302.8 (PD0); also elsewhere on the board
/Expansions/Module Slot 5/~CARD_RESET: Q2301.3 (D); also elsewhere on the board
/Expansions/Module Slot 5/~MOD_CLK_EN: U2302.19 (PD2); also elsewhere on the board
/Expansions/Module Slot 5/~PRESENT: U2302.16 (PC6); also elsewhere on the board
/Expansions/Module Slot 6/MOD_+3V3: R2606.1; also elsewhere on the board
/Expansions/Module Slot 6/MOD_+5V: R2604.1; also elsewhere on the board
/Expansions/Module Slot 6/MOD_+12V: R2602.1; also elsewhere on the board
/Expansions/Module Slot 6/MOD_A0: U2602.10 (PC0)
/Expansions/Module Slot 6/MOD_A1: U2602.13 (PC3)
/Expansions/Module Slot 6/Management Controller/DAP_SWIO: J2601.3, TP2602.1, U2602.18 (PD1)
/Expansions/Module Slot 6/Management Controller/DAP_~RST: J2601.1, R2601.1, TP2601.1, U2603.6 (C)
/Expansions/Module Slot 6/Management Controller/IN1: U2602.17 (PC7)
/Expansions/Module Slot 6/Management Controller/MEAS_+3V3: C2604.2, R2606.2, R2607.1, U2602.3 (PD6)
/Expansions/Module Slot 6/Management Controller/MEAS_+5V: C2603.2, R2604.2, R2605.1, U2602.2 (PD5)
/Expansions/Module Slot 6/Management Controller/MEAS_+12V: C2602.2, R2602.2, R2603.1, U2602.1 (PD4)
/Expansions/Module Slot 6/Management Controller/MGMT_~RST: U2602.4 (PD7), U2603.4 (Y)
/Expansions/Module Slot 6/Management Controller/OUT2: U2602.20 (PD3)
/Expansions/Module Slot 6/POWER_ON: U2602.8 (PD0); also elsewhere on the board
/Expansions/Module Slot 6/~CARD_RESET: Q2601.3 (D); also elsewhere on the board
/Expansions/Module Slot 6/~MOD_CLK_EN: U2602.19 (PD2); also elsewhere on the board
/Expansions/Module Slot 6/~PRESENT: U2602.16 (PC6); also elsewhere on the board
GND: C201.1, C202.1, C203.1, C801.1, C802.1, C803.1, C804.1, C1201.1, C1202.1, C1203.1, C1204.1, C1501.1, C1502.1, C1503.1, C1504.1, C1801.1, C1802.1, C1803.1, C1804.1, C2002.1, C2301.1, C2302.1, C2303.1, C2304.1, C2601.1, C2602.1, C2603.1, C2604.1, J801.2, J1201.2, J1501.2, J1801.2, J2002.2, J2301.2, J2601.2, Q801.2 (S), Q1201.2 (S), Q1501.2 (S), Q1801.2 (S), Q2001.2 (S), Q2301.2 (S), Q2601.2 (S), R215.2, R217.2, R219.2, R803.2, R805.2, R807.2, R809.1, R1203.2, R1205.2, R1207.2, R1209.1, R1503.2, R1505.2, R1507.2, R1509.1, R1803.2, R1805.2, R1807.2, R1809.1, R2003.1, R2303.2, R2305.2, R2307.2, R2309.1, R2603.2, R2605.2, R2607.2, R2609.1, U802.7 (VSS), U802.10 (PC0), U802.13 (PC3), U803.2 (GND), U1202.7 (VSS), U1202.10 (PC0), U1202.14 (PC4), U1203.2 (GND), U1502.7 (VSS), U1502.10 (PC0), U1503.2 (GND), U1802.7 (VSS), U1802.13 (PC3), U1802.14 (PC4), U1803.2 (GND), U2001.2 (GND), U2004.7 (VSS), U2302.7 (VSS), U2302.13 (PC3), U2303.2 (GND), U2602.7 (VSS), U2602.14 (PC4), U2603.2 (GND); also elsewhere on the board
I2C^{BRD}_{SCL}: U802.12 (PC2), U1202.12 (PC2), U1502.12 (PC2), U1802.12 (PC2), U2004.12 (PC2), U2302.12 (PC2), U2602.12 (PC2); also elsewhere on the board
I2C^{BRD}_{SDA}: U802.11 (PC1), U1202.11 (PC1), U1502.11 (PC1), U1802.11 (PC1), U2004.11 (PC1), U2302.11 (PC1), U2602.11 (PC1); also elsewhere on the board
unnamed: Q801.1 (G), R808.2
unnamed: Q1201.1 (G), R1208.2
unnamed: Q1501.1 (G), R1508.2
unnamed: Q1801.1 (G), R1808.2
unnamed: Q2001.1 (G), R2002.2
unnamed: Q2301.1 (G), R2308.2
unnamed: Q2601.1 (G), R2608.2
unnamed: R808.1, R809.2, U802.15 (PC5)
unnamed: R810.1, U803.1 (A)
unnamed: R1208.1, R1209.2, U1202.15 (PC5)
unnamed: R1210.1, U1203.1 (A)
unnamed: R1508.1, R1509.2, U1502.15 (PC5)
unnamed: R1510.1, U1503.1 (A)
unnamed: R1808.1, R1809.2, U1802.15 (PC5)
unnamed: R1810.1, U1803.1 (A)
unnamed: R2004.1, U2001.1 (A)
unnamed: R2002.1, R2003.2, U2004.15 (PC5)
unnamed: R2308.1, R2309.2, U2302.15 (PC5)
unnamed: R2310.1, U2303.1 (A)
unnamed: R2608.1, R2609.2, U2602.15 (PC5)
unnamed: R2610.1, U2603.1 (A)
~RESET: Q2001.3 (D), U803.3 (B), U1203.3 (B), U1503.3 (B), U1803.3 (B), U2001.3 (B), U2303.3 (B), U2603.3 (B); also elsewhere on the board

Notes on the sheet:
~2.51 V
TODO: JST
3K3
Debug Port
12K
~2.50 V
MGMT_~{RST} is not an open-collector signal as it's simpler to manage this way. As we only control a single pin, that's fine.
Each divider should sink about 1 mA, so we have a stable current flow
Three voltage dividers that try to target 2.5V, so we get 30% safety margin
OUT_{OC} is an open-collector out which is off by default. This way we can control local and global reset nicely.
A0..A2 are using GPIO pull-ups to be HIGH by default, and should be connected to GND by the including sheet to set the address

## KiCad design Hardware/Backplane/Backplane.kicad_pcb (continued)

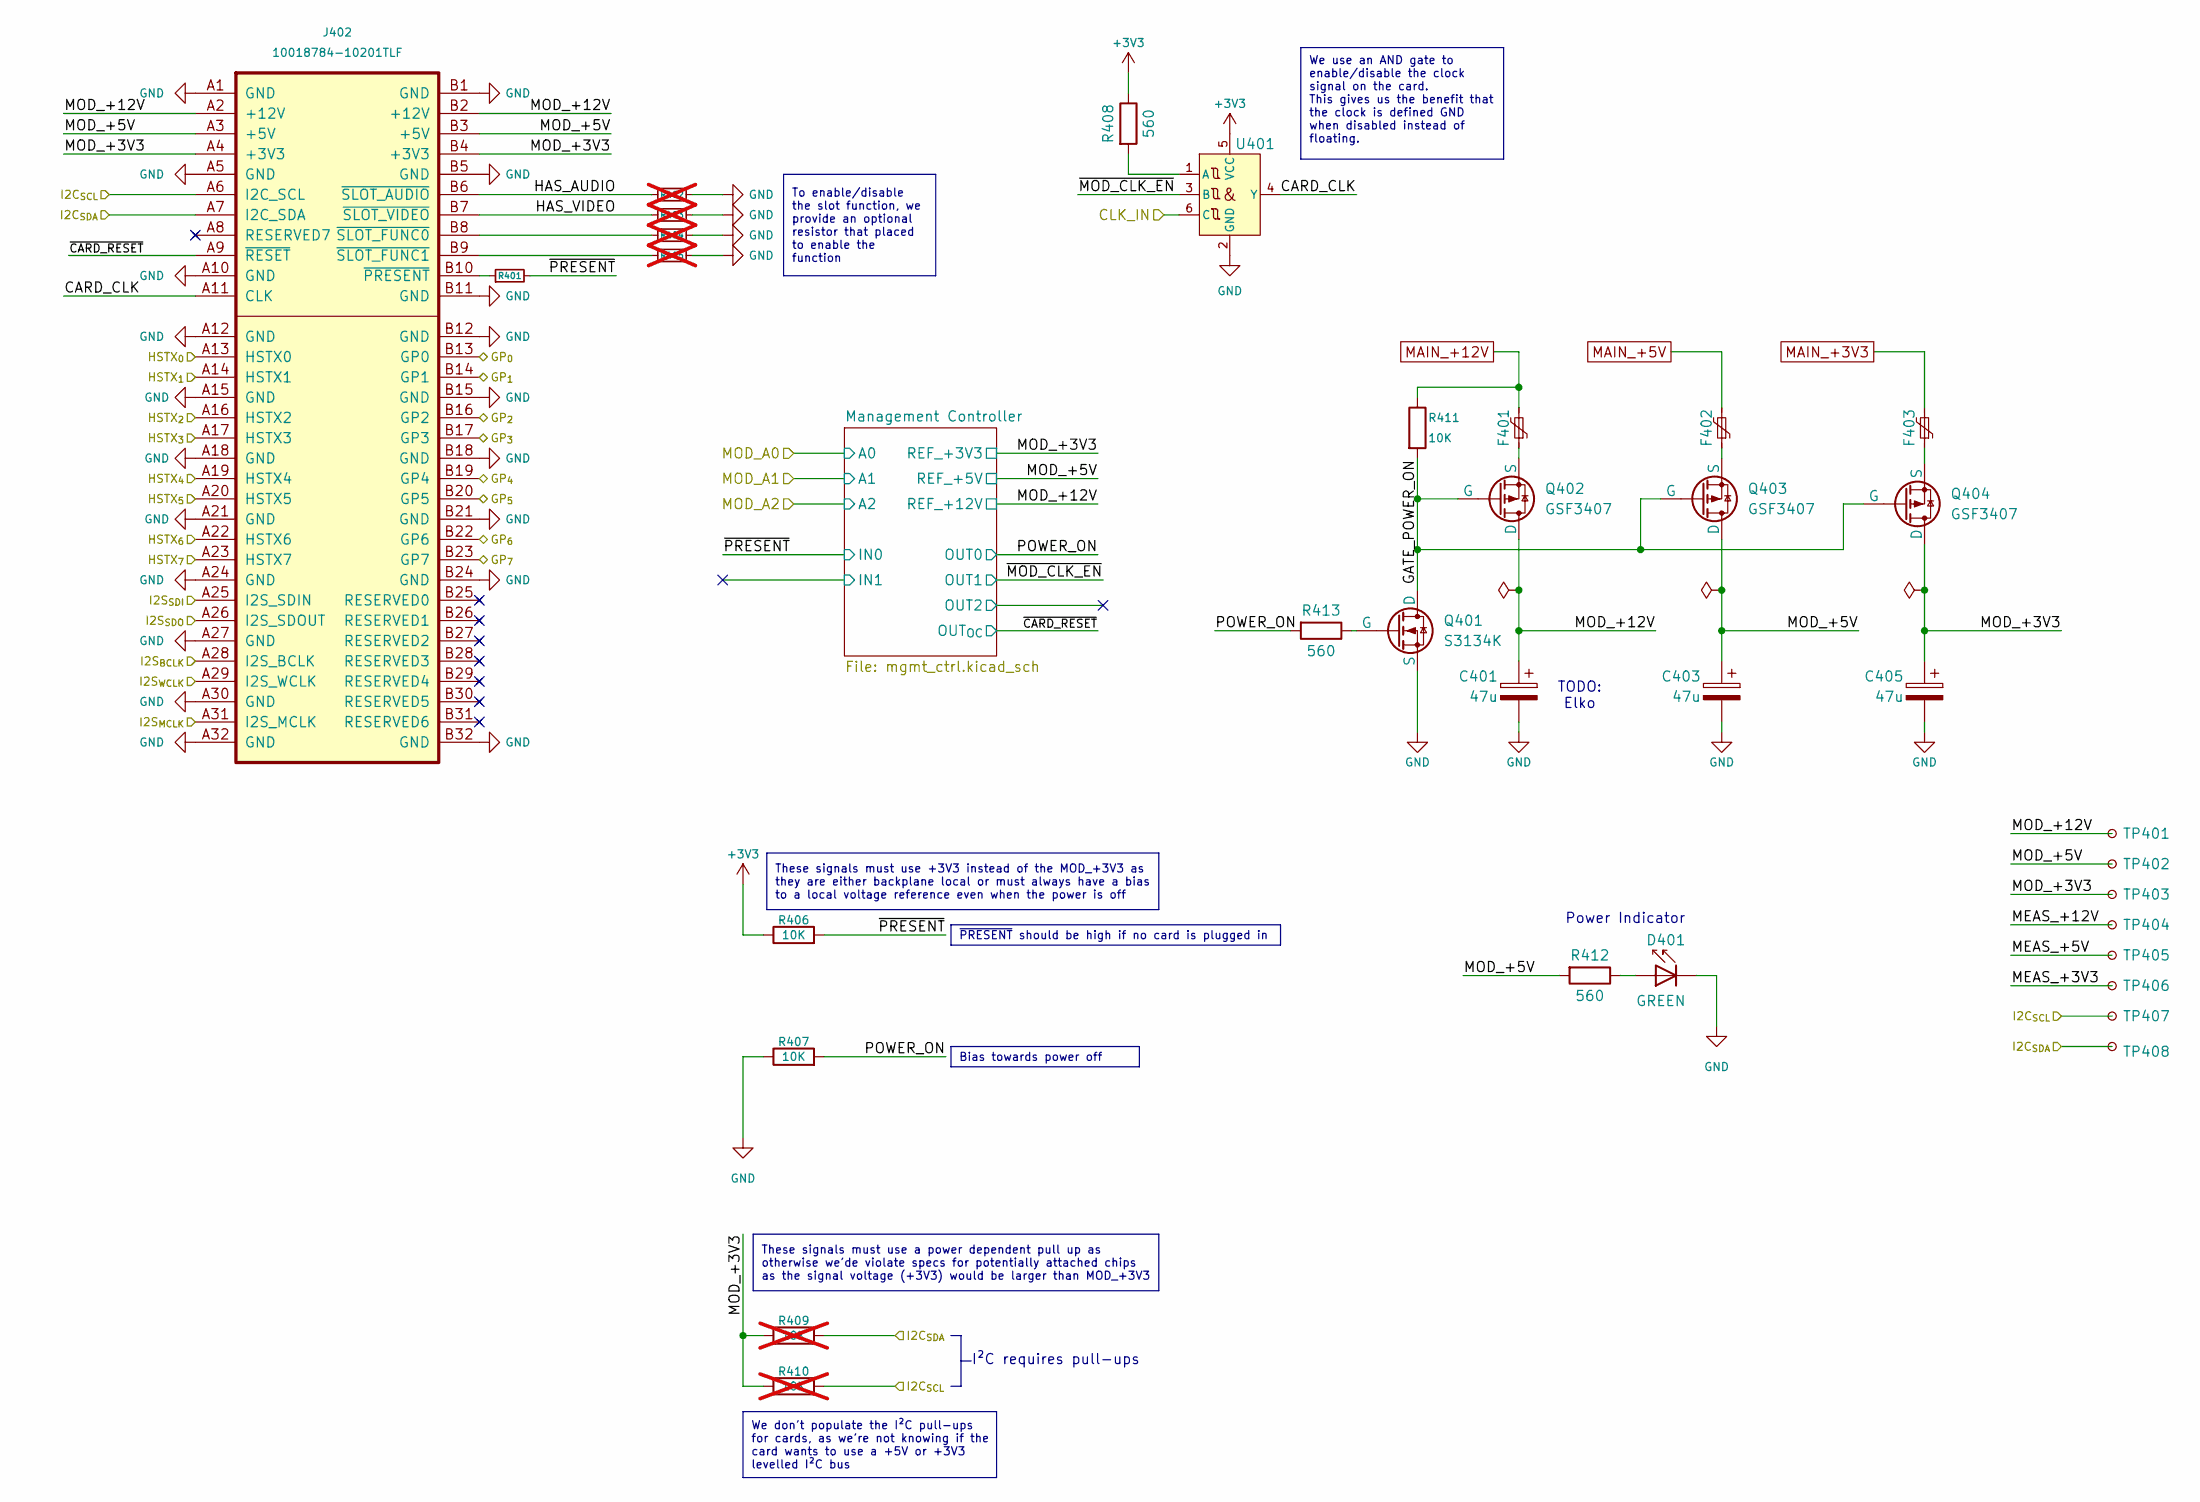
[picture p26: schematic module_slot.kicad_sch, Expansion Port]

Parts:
C401: 47u; C_0603_1608Metric
C403, C405: 47u; C_0603_1608Metric; Digikey Part No 490-13247-1-ND
D401: GREEN; LED_0603_1608Metric
F401, F402, F403: SMD1206B050TF/15; Fuse_1206_3216Metric; Digikey Part No 13-SMD1206B050TF/15TR-ND
J402: 10018784-10201TLF; CONN_10018784-10201TLF; Digikey Part No 609-2026-ND
Q401: S3134K; SOT-23; Digikey Part No 4786-S3134KCT-ND
Q402, Q403, Q404: GSF3407; SOT-23; Digikey Part No 4786-GSF3407CT-ND
R401: 0; R_0603_1608Metric; Digikey Part No 311-0.0GRCT-ND
R402, R403, R404, R405: 0; R_0603_1608Metric; Digikey Part No 311-0.0GRCT-ND; not fitted
R406, R407, R411: 10K; R_0603_1608Metric; Digikey Part No 311-10.0KHRCT-ND
R408, R412, R413: 560; R_0603_1608Metric; Digikey Part No RR08P560DCT-ND
R409, R410: 10K; R_0603_1608Metric; Digikey Part No 311-10.0KHRCT-ND; not fitted
TP401, TP402, TP403, TP404, TP405, TP406, TP407, TP408: TestPoint_Small; TestPoint_Pad_D1.0mm
U401: NL17SZS11DFT2G-Q; SOT-363_SC-70-6; DigiKey Part No 488-NL17SZS11DFT2G-QCT-ND

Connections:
+3V3: R406.1, R408.1, U401.5 (VCC); also elsewhere on the board
/Expansions/CLKTREE_{0}: U401.6 (C); also elsewhere on the board
/Expansions/HSTX_{0}: J402.A13 (HSTX0); also elsewhere on the board
/Expansions/HSTX_{1}: J402.A14 (HSTX1); also elsewhere on the board
/Expansions/HSTX_{2}: J402.A16 (HSTX2); also elsewhere on the board
/Expansions/HSTX_{3}: J402.A17 (HSTX3); also elsewhere on the board
/Expansions/HSTX_{4}: J402.A19 (HSTX4); also elsewhere on the board
/Expansions/HSTX_{5}: J402.A20 (HSTX5); also elsewhere on the board
/Expansions/HSTX_{6}: J402.A22 (HSTX6); also elsewhere on the board
/Expansions/HSTX_{7}: J402.A23 (HSTX7); also elsewhere on the board
/Expansions/I2C0_{SCL}: J402.A6 (I2C_SCL), R410.2, TP407.1
/Expansions/I2C0_{SDA}: J402.A7 (I2C_SDA), R409.2, TP408.1
/Expansions/MOD0_{GP0}: J402.B13 (GP0); also elsewhere on the board
/Expansions/MOD0_{GP1}: J402.B14 (GP1); also elsewhere on the board
/Expansions/MOD0_{GP2}: J402.B16 (GP2); also elsewhere on the board
/Expansions/MOD0_{GP3}: J402.B17 (GP3); also elsewhere on the board
/Expansions/MOD0_{GP4}: J402.B19 (GP4); also elsewhere on the board
/Expansions/MOD0_{GP5}: J402.B20 (GP5); also elsewhere on the board
/Expansions/MOD0_{GP6}: J402.B22 (GP6); also elsewhere on the board
/Expansions/MOD0_{GP7}: J402.B23 (GP7); also elsewhere on the board
/Expansions/Module Slot 0/CARD_CLK: J402.A11 (CLK), U401.4 (Y)
/Expansions/Module Slot 0/GATE_POWER_ON: Q401.3 (D), Q402.1 (G), Q403.1 (G), Q404.1 (G), R411.2
/Expansions/Module Slot 0/HAS_AUDIO: J402.B6 (~SLOT_AUDIO), R402.1
/Expansions/Module Slot 0/HAS_VIDEO: J402.B7 (~SLOT_VIDEO), R403.1
/Expansions/Module Slot 0/I2S_{BCLK}: J402.A28 (I2S_BCLK)
/Expansions/Module Slot 0/I2S_{MCLK}: J402.A31 (I2S_MCLK)
/Expansions/Module Slot 0/I2S_{SDI}: J402.A25 (I2S_SDIN)
/Expansions/Module Slot 0/I2S_{SDO}: J402.A26 (I2S_SDOUT)
/Expansions/Module Slot 0/I2S_{WCLK}: J402.A29 (I2S_WCLK)
/Expansions/Module Slot 0/MEAS_+3V3: TP406.1
/Expansions/Module Slot 0/MEAS_+5V: TP405.1
/Expansions/Module Slot 0/MEAS_+12V: TP404.1
/Expansions/Module Slot 0/MOD_+3V3: C405.1, J402.A4 (+3V3), J402.B4 (+3V3), Q404.3 (D), R409.1, R410.1, TP403.1; also elsewhere on the board
/Expansions/Module Slot 0/MOD_+5V: C403.1, J402.A3 (+5V), J402.B3 (+5V), Q403.3 (D), R412.2, TP402.1; also elsewhere on the board
/Expansions/Module Slot 0/MOD_+12V: C401.1, J402.A2 (+12V), J402.B2 (+12V), Q402.3 (D), TP401.1; also elsewhere on the board
/Expansions/Module Slot 0/POWER_ON: R407.2, R413.2; also elsewhere on the board
/Expansions/Module Slot 0/~CARD_RESET: J402.A9 (~RESET); also elsewhere on the board
/Expansions/Module Slot 0/~MOD_CLK_EN: U401.3 (B); also elsewhere on the board
/Expansions/Module Slot 0/~PRESENT: R401.2, R406.2; also elsewhere on the board
GND: C401.2, C403.2, C405.2, D401.1 (K), J402.A1 (GND), J402.A5 (GND), J402.A10 (GND), J402.A12 (GND), J402.A15 (GND), J402.A18 (GND), J402.A21 (GND), J402.A24 (GND), J402.A27 (GND), J402.A30 (GND), J402.A32 (GND), J402.B1 (GND), J402.B5 (GND), J402.B11 (GND), J402.B12 (GND), J402.B15 (GND), J402.B18 (GND), J402.B21 (GND), J402.B24 (GND), J402.B32 (GND), Q401.2 (S), R402.2, R403.2, R404.2, R405.2, R407.1, U401.2 (GND); also elsewhere on the board
MAIN_+3V3: F403.2; also elsewhere on the board
MAIN_+5V: F402.2; also elsewhere on the board
MAIN_+12V: F401.2, R411.1; also elsewhere on the board
unnamed: D401.2 (A), R412.1
unnamed: J402.B10 (~PRESENT), R401.1
unnamed: J402.B8 (~SLOT_FUNC0), R404.1
unnamed: J402.B9 (~SLOT_FUNC1), R405.1
unnamed: Q401.1 (G), R413.1
unnamed: F401.1, Q402.2 (S)
unnamed: F402.1, Q403.2 (S)
unnamed: F403.1, Q404.2 (S)
unnamed: R408.2, U401.1 (A)

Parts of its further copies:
C701, C1101, C1401, C1701, C2201, C2501: 47u; C_0603_1608Metric
C703, C705, C1103, C1105, C1403, C1405, C1703, C1705, C2203, C2205, C2503, C2505: 47u; C_0603_1608Metric; Digikey Part No 490-13247-1-ND
D701, D1101, D1401, D1701, D2201, D2501: GREEN; LED_0603_1608Metric
F701, F702, F703, F1101, F1102, F1103, F1401, F1402, F1403, F1701, F1702, F1703, F2202, F2203, F2204, F2501, F2502, F2503: SMD1206B050TF/15; Fuse_1206_3216Metric; Digikey Part No 13-SMD1206B050TF/15TR-ND
J702, J1102, J1402, J1702, J2203, J2502: 10018784-10201TLF; CONN_10018784-10201TLF; Digikey Part No 609-2026-ND
Q701, Q1101, Q1401, Q1701, Q2201, Q2501: S3134K; SOT-23; Digikey Part No 4786-S3134KCT-ND
Q702, Q703, Q704, Q1102, Q1103, Q1104, Q1402, Q1403, Q1404, Q1702, Q1703, Q1704, Q2202, Q2203, Q2204, Q2502, Q2503, Q2504: GSF3407; SOT-23; Digikey Part No 4786-GSF3407CT-ND
R701, R1101, R1401, R1701, R2201, R2501: 0; R_0603_1608Metric; Digikey Part No 311-0.0GRCT-ND
R702, R703, R704, R705, R1102, R1103, R1104, R1105, R1402, R1403, R1404, R1405, R1702, R1703, R1704, R1705, R2204, R2205, R2206, R2207, R2502, R2503, R2504, R2505: 0; R_0603_1608Metric; Digikey Part No 311-0.0GRCT-ND; not fitted
R706, R707, R711, R1106, R1107, R1111, R1406, R1407, R1411, R1706, R1707, R1711, R2208, R2209, R2213, R2506, R2507, R2511: 10K; R_0603_1608Metric; Digikey Part No 311-10.0KHRCT-ND
R708, R712, R713, R1108, R1112, R1113, R1408, R1412, R1413, R1708, R1712, R1713, R2210, R2214, R2215, R2508, R2512, R2513: 560; R_0603_1608Metric; Digikey Part No RR08P560DCT-ND
R709, R710, R1109, R1110, R1409, R1410, R1709, R1710, R2211, R2212, R2509, R2510: 10K; R_0603_1608Metric; Digikey Part No 311-10.0KHRCT-ND; not fitted
TP701, TP702, TP703, TP704, TP705, TP706, TP707, TP708, TP1101, TP1102, TP1103, TP1104, TP1105, TP1106, TP1107, TP1108, TP1401, TP1402, TP1403, TP1404, TP1405, TP1406, TP1407, TP1408, TP1701, TP1702, TP1703, TP1704, TP1705, TP1706, TP1707, TP1708, TP2201, TP2202, TP2206, TP2207, TP2208, TP2209, TP2210, TP2211, TP2501, TP2502, TP2503, TP2504, TP2505, TP2506, TP2507, TP2508: TestPoint_Small; TestPoint_Pad_D1.0mm
U701, U1101, U1401, U1701, U2201, U2501: NL17SZS11DFT2G-Q; SOT-363_SC-70-6; DigiKey Part No 488-NL17SZS11DFT2G-QCT-ND

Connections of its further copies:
+3V3: R706.1, R708.1, R1106.1, R1108.1, R1406.1, R1408.1, R1706.1, R1708.1, R2208.1, R2210.1, R2506.1, R2508.1, U701.5 (VCC), U1101.5 (VCC), U1401.5 (VCC), U1701.5 (VCC), U2201.5 (VCC), U2501.5 (VCC); also elsewhere on the board
/Expansions/CLKTREE_{0}: U701.6 (C), U1101.6 (C); also elsewhere on the board
/Expansions/CLKTREE_{1}: U1401.6 (C), U1701.6 (C), U2201.6 (C); also elsewhere on the board
/Expansions/CLKTREE_{2}: U2501.6 (C); also elsewhere on the board
/Expansions/I2C1_{SCL}: J702.A6 (I2C_SCL), R710.2, TP707.1
/Expansions/I2C1_{SDA}: J702.A7 (I2C_SDA), R709.2, TP708.1
/Expansions/I2C2_{SCL}: J1102.A6 (I2C_SCL), R1110.2, TP1107.1
/Expansions/I2C2_{SDA}: J1102.A7 (I2C_SDA), R1109.2, TP1108.1
/Expansions/I2C3_{SCL}: J1402.A6 (I2C_SCL), R1410.2, TP1407.1
/Expansions/I2C3_{SDA}: J1402.A7 (I2C_SDA), R1409.2, TP1408.1
/Expansions/I2C4_{SCL}: J1702.A6 (I2C_SCL), R1710.2, TP1707.1
/Expansions/I2C4_{SDA}: J1702.A7 (I2C_SDA), R1709.2, TP1708.1
/Expansions/I2C5_{SCL}: J2203.A6 (I2C_SCL), R2212.2, TP2210.1
/Expansions/I2C5_{SDA}: J2203.A7 (I2C_SDA), R2211.2, TP2211.1
/Expansions/I2C6_{SCL}: J2502.A6 (I2C_SCL), R2510.2, TP2507.1
/Expansions/I2C6_{SDA}: J2502.A7 (I2C_SDA), R2509.2, TP2508.1
/Expansions/I2S_{BCLK}: J702.A28 (I2S_BCLK); also elsewhere on the board
/Expansions/I2S_{LRCLK}: J702.A29 (I2S_WCLK); also elsewhere on the board
/Expansions/I2S_{MCLK}: J702.A31 (I2S_MCLK); also elsewhere on the board
/Expansions/I2S_{SDI}: J702.A25 (I2S_SDIN); also elsewhere on the board
/Expansions/I2S_{SDO}: J702.A26 (I2S_SDOUT); also elsewhere on the board
/Expansions/MOD1_{GP0}: J702.B13 (GP0); also elsewhere on the board
/Expansions/MOD1_{GP1}: J702.B14 (GP1); also elsewhere on the board
/Expansions/MOD1_{GP2}: J702.B16 (GP2); also elsewhere on the board
/Expansions/MOD1_{GP3}: J702.B17 (GP3); also elsewhere on the board
/Expansions/MOD1_{GP4}: J702.B19 (GP4); also elsewhere on the board
/Expansions/MOD1_{GP5}: J702.B20 (GP5); also elsewhere on the board
/Expansions/MOD1_{GP6}: J702.B22 (GP6); also elsewhere on the board
/Expansions/MOD1_{GP7}: J702.B23 (GP7); also elsewhere on the board
/Expansions/MOD2_{GP0}: J1102.B13 (GP0); also elsewhere on the board
/Expansions/MOD2_{GP1}: J1102.B14 (GP1); also elsewhere on the board
/Expansions/MOD2_{GP2}: J1102.B16 (GP2); also elsewhere on the board
/Expansions/MOD2_{GP3}: J1102.B17 (GP3); also elsewhere on the board
/Expansions/MOD2_{GP4}: J1102.B19 (GP4); also elsewhere on the board
/Expansions/MOD2_{GP5}: J1102.B20 (GP5); also elsewhere on the board
/Expansions/MOD2_{GP6}: J1102.B22 (GP6); also elsewhere on the board
/Expansions/MOD2_{GP7}: J1102.B23 (GP7); also elsewhere on the board
/Expansions/MOD3_{GP0}: J1402.B13 (GP0); also elsewhere on the board
/Expansions/MOD3_{GP1}: J1402.B14 (GP1); also elsewhere on the board
/Expansions/MOD3_{GP2}: J1402.B16 (GP2); also elsewhere on the board
/Expansions/MOD3_{GP3}: J1402.B17 (GP3); also elsewhere on the board
/Expansions/MOD3_{GP4}: J1402.B19 (GP4); also elsewhere on the board
/Expansions/MOD3_{GP5}: J1402.B20 (GP5); also elsewhere on the board
/Expansions/MOD3_{GP6}: J1402.B22 (GP6); also elsewhere on the board
/Expansions/MOD3_{GP7}: J1402.B23 (GP7); also elsewhere on the board
/Expansions/MOD4_{GP0}: J1702.B13 (GP0); also elsewhere on the board
/Expansions/MOD4_{GP1}: J1702.B14 (GP1); also elsewhere on the board
/Expansions/MOD4_{GP2}: J1702.B16 (GP2); also elsewhere on the board
/Expansions/MOD4_{GP3}: J1702.B17 (GP3); also elsewhere on the board
/Expansions/MOD4_{GP4}: J1702.B19 (GP4); also elsewhere on the board
/Expansions/MOD4_{GP5}: J1702.B20 (GP5); also elsewhere on the board
/Expansions/MOD4_{GP6}: J1702.B22 (GP6); also elsewhere on the board
/Expansions/MOD4_{GP7}: J1702.B23 (GP7); also elsewhere on the board
/Expansions/MOD5_{GP0}: J2203.B13 (GP0); also elsewhere on the board
/Expansions/MOD5_{GP1}: J2203.B14 (GP1); also elsewhere on the board
/Expansions/MOD5_{GP2}: J2203.B16 (GP2); also elsewhere on the board
/Expansions/MOD5_{GP3}: J2203.B17 (GP3); also elsewhere on the board
/Expansions/MOD5_{GP4}: J2203.B19 (GP4); also elsewhere on the board
/Expansions/MOD5_{GP5}: J2203.B20 (GP5); also elsewhere on the board
/Expansions/MOD5_{GP6}: J2203.B22 (GP6); also elsewhere on the board
/Expansions/MOD5_{GP7}: J2203.B23 (GP7); also elsewhere on the board
/Expansions/MOD6_{GP0}: J2502.B13 (GP0); also elsewhere on the board
/Expansions/MOD6_{GP1}: J2502.B14 (GP1); also elsewhere on the board
/Expansions/MOD6_{GP2}: J2502.B16 (GP2); also elsewhere on the board
/Expansions/MOD6_{GP3}: J2502.B17 (GP3); also elsewhere on the board
/Expansions/MOD6_{GP4}: J2502.B19 (GP4); also elsewhere on the board
/Expansions/MOD6_{GP5}: J2502.B20 (GP5); also elsewhere on the board
/Expansions/MOD6_{GP6}: J2502.B22 (GP6); also elsewhere on the board
/Expansions/MOD6_{GP7}: J2502.B23 (GP7); also elsewhere on the board
/Expansions/Module Slot 1/CARD_CLK: J702.A11 (CLK), U701.4 (Y)
/Expansions/Module Slot 1/GATE_POWER_ON: Q701.3 (D), Q702.1 (G), Q703.1 (G), Q704.1 (G), R711.2
/Expansions/Module Slot 1/HAS_AUDIO: J702.B6 (~SLOT_AUDIO), R702.1
/Expansions/Module Slot 1/HAS_VIDEO: J702.B7 (~SLOT_VIDEO), R703.1
/Expansions/Module Slot 1/HSTX_{0}: J702.A13 (HSTX0)
/Expansions/Module Slot 1/HSTX_{1}: J702.A14 (HSTX1)
/Expansions/Module Slot 1/HSTX_{2}: J702.A16 (HSTX2)
/Expansions/Module Slot 1/HSTX_{3}: J702.A17 (HSTX3)
/Expansions/Module Slot 1/HSTX_{4}: J702.A19 (HSTX4)
/Expansions/Module Slot 1/HSTX_{5}: J702.A20 (HSTX5)
/Expansions/Module Slot 1/HSTX_{6}: J702.A22 (HSTX6)
/Expansions/Module Slot 1/HSTX_{7}: J702.A23 (HSTX7)
/Expansions/Module Slot 1/MEAS_+3V3: TP706.1
/Expansions/Module Slot 1/MEAS_+5V: TP705.1
/Expansions/Module Slot 1/MEAS_+12V: TP704.1
/Expansions/Module Slot 1/MOD_+3V3: C705.1, J702.A4 (+3V3), J702.B4 (+3V3), Q704.3 (D), R709.1, R710.1, TP703.1; also elsewhere on the board
/Expansions/Module Slot 1/MOD_+5V: C703.1, J702.A3 (+5V), J702.B3 (+5V), Q703.3 (D), R712.2, TP702.1; also elsewhere on the board
/Expansions/Module Slot 1/MOD_+12V: C701.1, J702.A2 (+12V), J702.B2 (+12V), Q702.3 (D), TP701.1; also elsewhere on the board
/Expansions/Module Slot 1/POWER_ON: R707.2, R713.2; also elsewhere on the board
/Expansions/Module Slot 1/~CARD_RESET: J702.A9 (~RESET); also elsewhere on the board
/Expansions/Module Slot 1/~MOD_CLK_EN: U701.3 (B); also elsewhere on the board
/Expansions/Module Slot 1/~PRESENT: R701.2, R706.2; also elsewhere on the board
/Expansions/Module Slot 2/CARD_CLK: J1102.A11 (CLK), U1101.4 (Y)
/Expansions/Module Slot 2/GATE_POWER_ON: Q1101.3 (D), Q1102.1 (G), Q1103.1 (G), Q1104.1 (G), R1111.2
/Expansions/Module Slot 2/HAS_AUDIO: J1102.B6 (~SLOT_AUDIO), R1102.1
/Expansions/Module Slot 2/HAS_VIDEO: J1102.B7 (~SLOT_VIDEO), R1103.1
/Expansions/Module Slot 2/HSTX_{0}: J1102.A13 (HSTX0)
/Expansions/Module Slot 2/HSTX_{1}: J1102.A14 (HSTX1)
/Expansions/Module Slot 2/HSTX_{2}: J1102.A16 (HSTX2)
/Expansions/Module Slot 2/HSTX_{3}: J1102.A17 (HSTX3)
/Expansions/Module Slot 2/HSTX_{4}: J1102.A19 (HSTX4)
/Expansions/Module Slot 2/HSTX_{5}: J1102.A20 (HSTX5)
/Expansions/Module Slot 2/HSTX_{6}: J1102.A22 (HSTX6)
/Expansions/Module Slot 2/HSTX_{7}: J1102.A23 (HSTX7)
/Expansions/Module Slot 2/I2S_{BCLK}: J1102.A28 (I2S_BCLK)
/Expansions/Module Slot 2/I2S_{MCLK}: J1102.A31 (I2S_MCLK)
/Expansions/Module Slot 2/I2S_{SDI}: J1102.A25 (I2S_SDIN)
/Expansions/Module Slot 2/I2S_{SDO}: J1102.A26 (I2S_SDOUT)
/Expansions/Module Slot 2/I2S_{WCLK}: J1102.A29 (I2S_WCLK)
/Expansions/Module Slot 2/MEAS_+3V3: TP1106.1
/Expansions/Module Slot 2/MEAS_+5V: TP1105.1
/Expansions/Module Slot 2/MEAS_+12V: TP1104.1
/Expansions/Module Slot 2/MOD_+3V3: C1105.1, J1102.A4 (+3V3), J1102.B4 (+3V3), Q1104.3 (D), R1109.1, R1110.1, TP1103.1; also elsewhere on the board
/Expansions/Module Slot 2/MOD_+5V: C1103.1, J1102.A3 (+5V), J1102.B3 (+5V), Q1103.3 (D), R1112.2, TP1102.1; also elsewhere on the board
/Expansions/Module Slot 2/MOD_+12V: C1101.1, J1102.A2 (+12V), J1102.B2 (+12V), Q1102.3 (D), TP1101.1; also elsewhere on the board
/Expansions/Module Slot 2/POWER_ON: R1107.2, R1113.2; also elsewhere on the board
/Expansions/Module Slot 2/~CARD_RESET: J1102.A9 (~RESET); also elsewhere on the board
/Expansions/Module Slot 2/~MOD_CLK_EN: U1101.3 (B); also elsewhere on the board
/Expansions/Module Slot 2/~PRESENT: R1101.2, R1106.2; also elsewhere on the board
/Expansions/Module Slot 3/CARD_CLK: J1402.A11 (CLK), U1401.4 (Y)
/Expansions/Module Slot 3/GATE_POWER_ON: Q1401.3 (D), Q1402.1 (G), Q1403.1 (G), Q1404.1 (G), R1411.2
/Expansions/Module Slot 3/HAS_AUDIO: J1402.B6 (~SLOT_AUDIO), R1402.1
/Expansions/Module Slot 3/HAS_VIDEO: J1402.B7 (~SLOT_VIDEO), R1403.1
/Expansions/Module Slot 3/HSTX_{0}: J1402.A13 (HSTX0)
/Expansions/Module Slot 3/HSTX_{1}: J1402.A14 (HSTX1)
/Expansions/Module Slot 3/HSTX_{2}: J1402.A16 (HSTX2)
/Expansions/Module Slot 3/HSTX_{3}: J1402.A17 (HSTX3)
/Expansions/Module Slot 3/HSTX_{4}: J1402.A19 (HSTX4)
/Expansions/Module Slot 3/HSTX_{5}: J1402.A20 (HSTX5)
/Expansions/Module Slot 3/HSTX_{6}: J1402.A22 (HSTX6)
/Expansions/Module Slot 3/HSTX_{7}: J1402.A23 (HSTX7)
/Expansions/Module Slot 3/I2S_{BCLK}: J1402.A28 (I2S_BCLK)
/Expansions/Module Slot 3/I2S_{MCLK}: J1402.A31 (I2S_MCLK)
/Expansions/Module Slot 3/I2S_{SDI}: J1402.A25 (I2S_SDIN)
/Expansions/Module Slot 3/I2S_{SDO}: J1402.A26 (I2S_SDOUT)
/Expansions/Module Slot 3/I2S_{WCLK}: J1402.A29 (I2S_WCLK)
/Expansions/Module Slot 3/MEAS_+3V3: TP1406.1
/Expansions/Module Slot 3/MEAS_+5V: TP1405.1
/Expansions/Module Slot 3/MEAS_+12V: TP1404.1
/Expansions/Module Slot 3/MOD_+3V3: C1405.1, J1402.A4 (+3V3), J1402.B4 (+3V3), Q1404.3 (D), R1409.1, R1410.1, TP1403.1; also elsewhere on the board
/Expansions/Module Slot 3/MOD_+5V: C1403.1, J1402.A3 (+5V), J1402.B3 (+5V), Q1403.3 (D), R1412.2, TP1402.1; also elsewhere on the board
/Expansions/Module Slot 3/MOD_+12V: C1401.1, J1402.A2 (+12V), J1402.B2 (+12V), Q1402.3 (D), TP1401.1; also elsewhere on the board
/Expansions/Module Slot 3/POWER_ON: R1407.2, R1413.2; also elsewhere on the board
/Expansions/Module Slot 3/~CARD_RESET: J1402.A9 (~RESET); also elsewhere on the board
/Expansions/Module Slot 3/~MOD_CLK_EN: U1401.3 (B); also elsewhere on the board
/Expansions/Module Slot 3/~PRESENT: R1401.2, R1406.2; also elsewhere on the board
/Expansions/Module Slot 4/CARD_CLK: J1702.A11 (CLK), U1701.4 (Y)
/Expansions/Module Slot 4/GATE_POWER_ON: Q1701.3 (D), Q1702.1 (G), Q1703.1 (G), Q1704.1 (G), R1711.2
/Expansions/Module Slot 4/HAS_AUDIO: J1702.B6 (~SLOT_AUDIO), R1702.1
/Expansions/Module Slot 4/HAS_VIDEO: J1702.B7 (~SLOT_VIDEO), R1703.1
/Expansions/Module Slot 4/HSTX_{0}: J1702.A13 (HSTX0)
/Expansions/Module Slot 4/HSTX_{1}: J1702.A14 (HSTX1)
/Expansions/Module Slot 4/HSTX_{2}: J1702.A16 (HSTX2)
/Expansions/Module Slot 4/HSTX_{3}: J1702.A17 (HSTX3)
/Expansions/Module Slot 4/HSTX_{4}: J1702.A19 (HSTX4)
/Expansions/Module Slot 4/HSTX_{5}: J1702.A20 (HSTX5)
/Expansions/Module Slot 4/HSTX_{6}: J1702.A22 (HSTX6)
/Expansions/Module Slot 4/HSTX_{7}: J1702.A23 (HSTX7)
/Expansions/Module Slot 4/I2S_{BCLK}: J1702.A28 (I2S_BCLK)
/Expansions/Module Slot 4/I2S_{MCLK}: J1702.A31 (I2S_MCLK)
/Expansions/Module Slot 4/I2S_{SDI}: J1702.A25 (I2S_SDIN)
/Expansions/Module Slot 4/I2S_{SDO}: J1702.A26 (I2S_SDOUT)
/Expansions/Module Slot 4/I2S_{WCLK}: J1702.A29 (I2S_WCLK)
/Expansions/Module Slot 4/MEAS_+3V3: TP1706.1
/Expansions/Module Slot 4/MEAS_+5V: TP1705.1
/Expansions/Module Slot 4/MEAS_+12V: TP1704.1
/Expansions/Module Slot 4/MOD_+3V3: C1705.1, J1702.A4 (+3V3), J1702.B4 (+3V3), Q1704.3 (D), R1709.1, R1710.1, TP1703.1; also elsewhere on the board
/Expansions/Module Slot 4/MOD_+5V: C1703.1, J1702.A3 (+5V), J1702.B3 (+5V), Q1703.3 (D), R1712.2, TP1702.1; also elsewhere on the board
/Expansions/Module Slot 4/MOD_+12V: C1701.1, J1702.A2 (+12V), J1702.B2 (+12V), Q1702.3 (D), TP1701.1; also elsewhere on the board
/Expansions/Module Slot 4/POWER_ON: R1707.2, R1713.2; also elsewhere on the board
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

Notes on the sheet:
I²C requires pull-ups
Power Indicator
TODO: Elko
We use an AND gate to enable/disable the clock signal on the card. This gives us the benefit that the clock is defined GND when disabled instead of floating.
These signals must use +3V3 instead of the MOD_+3V3 as they are either backplane local or must always have a bias to a local voltage reference even when the power is off
Bias towards power off
~{PRESENT} should be high if no card is plugged in
These signals must use a power dependent pull up as otherwise we'de violate specs for potentially attached chips as the signal voltage (+3V3) would be larger than MOD_+3V3
We don't populate the I²C pull-ups for cards, as we're not knowing if the card wants to use a +5V or +3V3 levelled I²C bus
To enable/disable the slot function, we provide an optional resistor that placed to enable the function

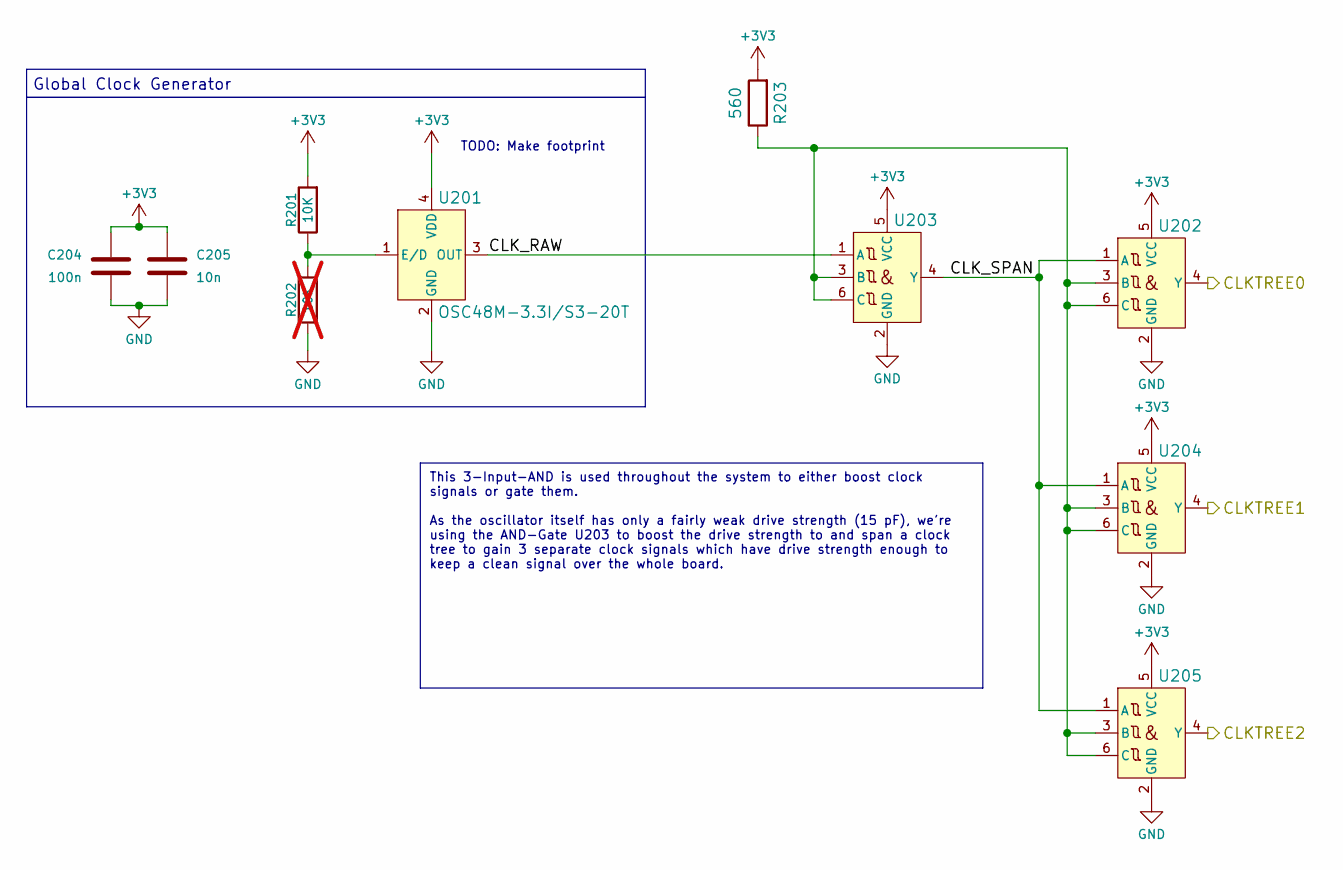
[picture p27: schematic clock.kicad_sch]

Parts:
C204: 100n; C_0603_1608Metric; Digikey Part No 399-C0603C104M4RACTUCT-ND
C205: 10n; C_0603_1608Metric; Digikey Part No 399-C0603C103K5RACTUCT-ND
R201: 10K; R_0603_1608Metric
R202: 10K; R_0603_1608Metric; not fitted
R203: 560; R_0603_1608Metric; Digikey Part No RR08P560DCT-ND
U201: OSC48M-3.3I/S3-20T; Digikey Part No 3155-OSC48M-3.3I/S3-20TCT-ND
U202, U203, U204, U205: NL17SZS11DFT2G-Q; SOT-363_SC-70-6; DigiKey Part No 488-NL17SZS11DFT2G-QCT-ND

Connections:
+3V3: C204.2, C205.2, R201.2, R203.2, U201.4 (VDD), U202.5 (VCC), U203.5 (VCC), U204.5 (VCC), U205.5 (VCC); also elsewhere on the board
/Expansions/CLKTREE_{0}: U202.4 (Y); also elsewhere on the board
/Expansions/CLKTREE_{1}: U204.4 (Y); also elsewhere on the board
/Expansions/CLKTREE_{2}: U205.4 (Y); also elsewhere on the board
/Expansions/Clock/CLK_RAW: U201.3 (OUT), U203.1 (A)
/Expansions/Clock/CLK_SPAN: U202.1 (A), U203.4 (Y), U204.1 (A), U205.1 (A)
GND: C204.1, C205.1, R202.1, U201.2 (GND), U202.2 (GND), U203.2 (GND), U204.2 (GND), U205.2 (GND); also elsewhere on the board
unnamed: R201.1, R202.2, U201.1 (E/D)
unnamed: R203.1, U202.3 (B), U202.6 (C), U203.3 (B), U203.6 (C), U204.3 (B), U204.6 (C), U205.3 (B), U205.6 (C)

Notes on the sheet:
TODO: Make footprint
Global Clock Generator
This 3-Input-AND is used throughout the system to either boost clock signals or gate them. As the oscillator itself has only a fairly weak drive strength (15 pF), we're using the AND-Gate U203 to boost the drive strength to and span a clock tree to gain 3 separate clock signals which have drive str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

Board: 4 copper layers, 521 parts (4 on the bottom side), 361 nets, no tracks yet.

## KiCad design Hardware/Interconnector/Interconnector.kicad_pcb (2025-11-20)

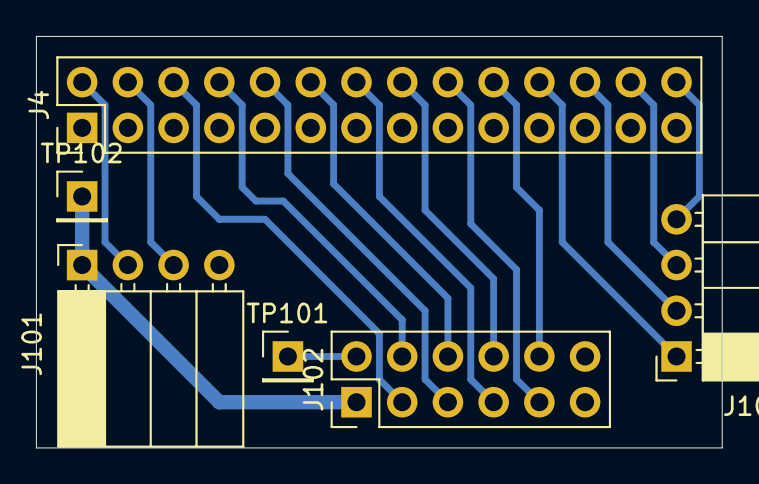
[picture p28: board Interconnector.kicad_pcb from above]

Board: 2 copper layers, 38.1 x 22.9 mm, 6 parts (0 on the bottom side), 17 nets.

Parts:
J4: Conn_Center; PinHeader_2x14_P2.54mm_Vertical
J101, J103: Conn_01x04; PinSocket_1x04_P2.54mm_Horizontal
J102: Conn_02x06_Odd_Even; PinHeader_2x06_P2.54mm_Vertical
TP101, TP102: TestPoint; PinHeader_1x01_P2.54mm_Vertical

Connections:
+3.3V: J101.1, J102.1, TP102.1
/GPIO22: J4.2, J101.2
/GPIO23: J4.4, J101.3
/GPIO24: J4.6, J102.3
/GPIO25: J4.8, J102.4
/GPIO26: J4.10, J102.5
/GPIO27: J4.12, J102.6
/GPIO28: J4.14, J102.7
/GPIO29: J4.16, J102.8
/GPIO30: J4.18, J102.9
/GPIO31: J4.20, J102.10
/GPIO32: J4.22, J103.1
/GPIO33: J4.24, J103.2
/GPIO34: J4.26, J103.3
/GPIO35: J4.28, J103.4
/~P2_RES: J102.2, TP101.1
GND: J4.1, J4.3, J4.5, J4.7, J4.9, J4.11, J4.13, J4.15, J4.17, J4.19, J4.21, J4.23, J4.25, J4.27, J101.4, J102.11, J102.12

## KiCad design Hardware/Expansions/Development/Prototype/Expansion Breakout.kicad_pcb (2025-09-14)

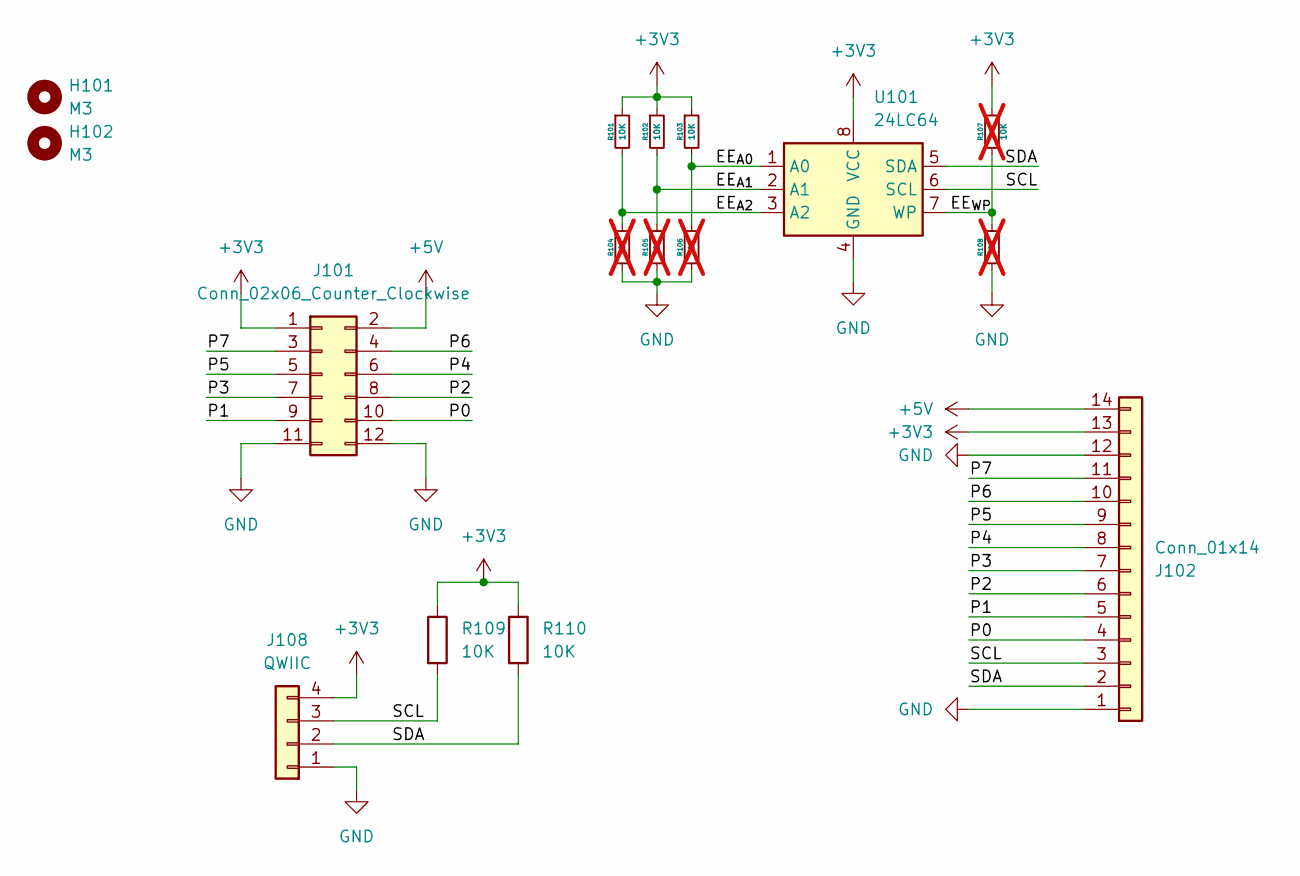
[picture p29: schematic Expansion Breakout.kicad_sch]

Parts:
H101, H102: M3; MountingHole_3.2mm_M3_ISO7380
J101: Conn_02x06_Counter_Clockwise; PinHeader_2x06_P2.54mm_Vertical
J102: Conn_01x14; PinSocket_1x14_P2.54mm_Horizontal
J108: QWIIC; PinSocket_1x04_P2.54mm_Horizontal
R101, R102, R103: 10K; R_0603_1608Metric_Pad0.98x0.95mm_HandSolder
R104, R105, R106, R107, R108: 10K; R_0603_1608Metric_Pad0.98x0.95mm_HandSolder; not fitted
R109, R110: 10K; R_Axial_DIN0207_L6.3mm_D2.5mm_P10.16mm_Horizontal
U101: 24LC64; DIP-8_W7.62mm_LongPads

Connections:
+3V3: J101.1, J102.13, J108.4, R101.1, R102.1, R103.1, R107.1, R109.1, R110.1, U101.8 (VCC)
+5V: J101.2, J102.14
/EE_{A0}: R103.2, R106.1, U101.1 (A0)
/EE_{A1}: R102.2, R105.1, U101.2 (A1)
/EE_{A2}: R101.2, R104.1, U101.3 (A2)
/EE_{WP}: R107.2, R108.1, U101.7 (WP)
/P0: J101.10, J102.4
/P1: J101.9, J102.5
/P2: J101.8, J102.6
/P3: J101.7, J102.7
/P4: J101.6, J102.8
/P5: J101.5, J102.9
/P6: J101.4, J102.10
/P7: J101.3, J102.11
/SCL: J102.3, J108.3, R109.2, U101.6 (SCL)
/SDA: J102.2, J108.2, R110.2, U101.5 (SDA)
GND: J101.11, J101.12, J102.1, J102.12, J108.1, R104.2, R105.2, R106.2, R108.2, U101.4 (GND)

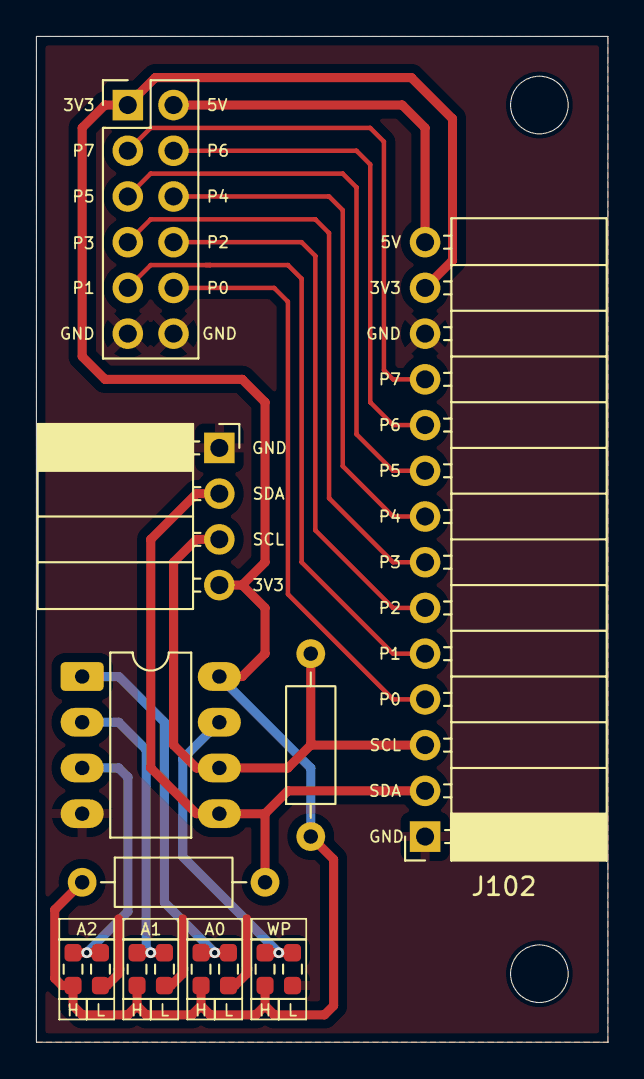
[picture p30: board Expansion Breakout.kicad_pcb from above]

Board: 2 copper layers, 31.8 x 55.9 mm, 16 parts (0 on the bottom side), 17 nets.

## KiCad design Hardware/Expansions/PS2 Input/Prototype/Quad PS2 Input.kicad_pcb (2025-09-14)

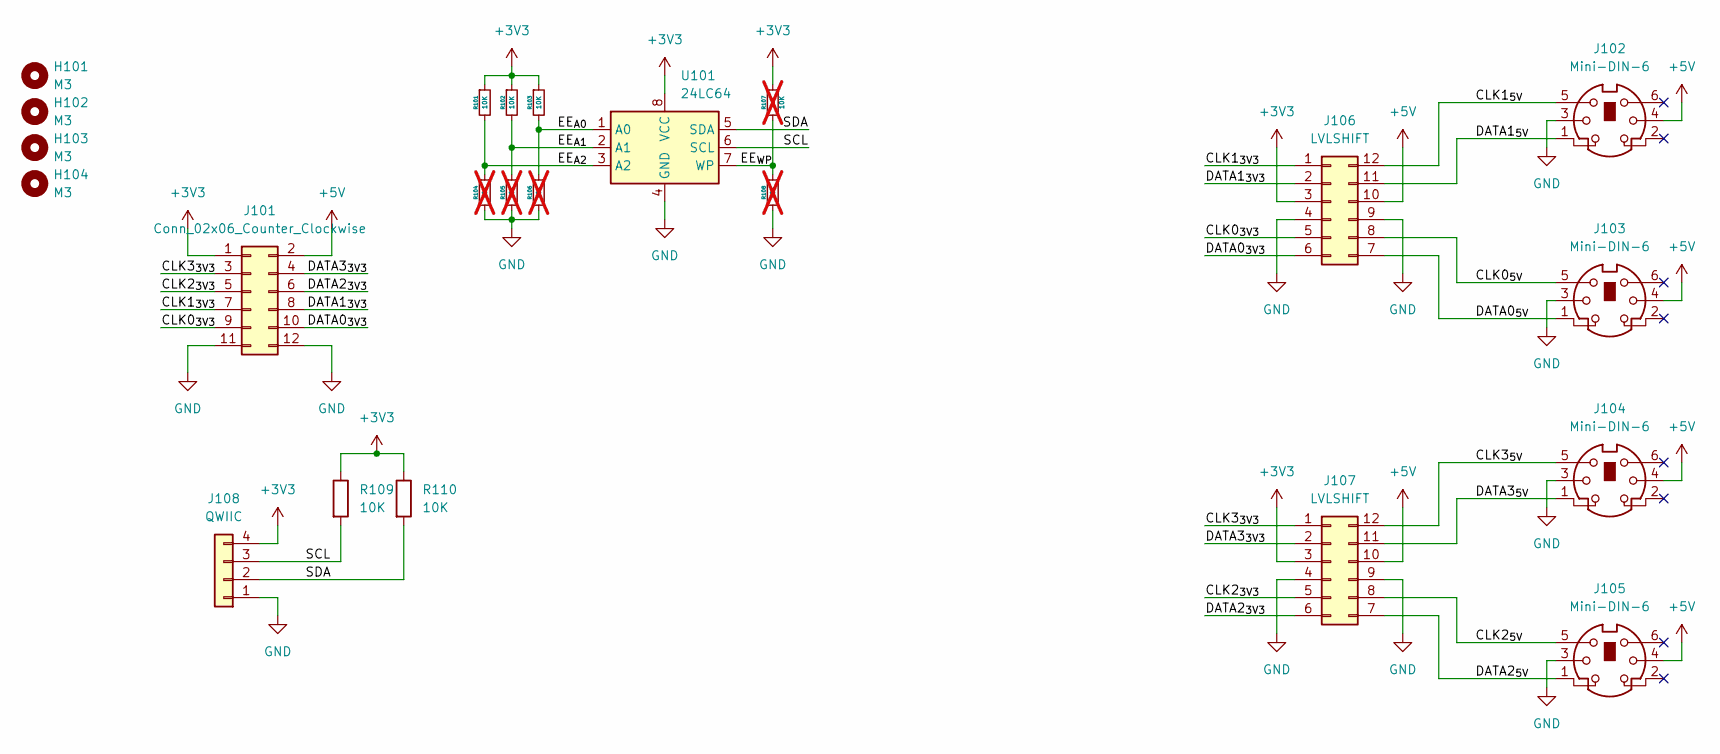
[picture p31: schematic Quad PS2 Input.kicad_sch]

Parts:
H101, H102, H103, H104: M3; MountingHole_3.2mm_M3_ISO7380
J101: Conn_02x06_Counter_Clockwise; PinHeader_2x06_P2.54mm_Vertical
J102, J103, J104, J105: Mini-DIN-6; J_Mini-DIN-6
J106, J107: LVLSHIFT; DIP-12_W10.16mm
J108: QWIIC; PinSocket_1x04_P2.54mm_Horizontal
R101, R102, R103: 10K; R_0603_1608Metric_Pad0.98x0.95mm_HandSolder
R104, R105, R106, R107, R108: 10K; R_0603_1608Metric_Pad0.98x0.95mm_HandSolder; not fitted
R109, R110: 10K; R_Axial_DIN0207_L6.3mm_D2.5mm_P10.16mm_Horizontal
U101: 24LC64; DIP-8_W7.62mm_LongPads

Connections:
+3V3: J101.1, J106.3, J107.3, J108.4, R101.1, R102.1, R103.1, R107.1, R109.1, R110.1, U101.8 (VCC)
+5V: J101.2, J102.4, J103.4, J104.4, J105.4, J106.10, J107.10
/CLK0_{3V3}: J101.9, J106.5
/CLK0_{5V}: J103.5, J106.8
/CLK1_{3V3}: J101.7, J106.1
/CLK1_{5V}: J102.5, J106.12
/CLK2_{3V3}: J101.5, J107.5
/CLK2_{5V}: J105.5, J107.8
/CLK3_{3V3}: J101.3, J107.1
/CLK3_{5V}: J104.5, J107.12
/DATA0_{3V3}: J101.10, J106.6
/DATA0_{5V}: J103.1, J106.7
/DATA1_{3V3}: J101.8, J106.2
/DATA1_{5V}: J102.1, J106.11
/DATA2_{3V3}: J101.6, J107.6
/DATA2_{5V}: J105.1, J107.7
/DATA3_{3V3}: J101.4, J107.2
/DATA3_{5V}: J104.1, J107.11
/EE_{A0}: R103.2, R106.1, U101.1 (A0)
/EE_{A1}: R102.2, R105.1, U101.2 (A1)
/EE_{A2}: R101.2, R104.1, U101.3 (A2)
/EE_{WP}: R107.2, R108.1, U101.7 (WP)
/SCL: J108.3, R109.2, U101.6 (SCL)
/SDA: J108.2, R110.2, U101.5 (SDA)
GND: J101.11, J101.12, J102.3, J103.3, J104.3, J105.3, J106.4, J106.9, J107.4, J107.9, J108.1, R104.2, R105.2, R106.2, R108.2, U101.4 (GND)


Board: 2 copper layers, 48.3 x 87.6 mm, 23 parts (0 on the bottom side), 25 nets.

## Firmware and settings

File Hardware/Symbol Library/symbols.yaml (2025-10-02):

---

symbols:
  CH32V003:
    description:

    width: 3
    pinout:
      VDD:
        type: power-input
        position: T2
      VSS:
        type: power-input
        position: B2
      PA1:
        type: logic-inout
        position: R10
      PA2:
        type: logic-inout
        position: R11
      PD0:
        type: logic-inout
        position: R1
      PD1:
        type: logic-inout
        position: R2
      PD2:
        type: logic-inout
        position: R3
      PD3:
        type: logic-inout
        position: R4
      PD4:
        type: logic-inout
        position: R5
      PD5:
        type: logic-inout
        position: R6
      PD6:
        type: logic-inout
        position: R7
      PD7:
        type: logic-inout
        position: R8
      PC0:
        type: logic-inout
        position: L1
      PC1:
        type: logic-inout
        position: L2
      PC2:
        type: logic-inout
        position: L3
      PC3:
        type: logic-inout
        position: L4
      PC4:
        type: logic-inout
        position: L5
      PC5:
        type: logic-inout
        position: L6
      PC6:
        type: logic-inout
        position: L7
      PC7:
        type: logic-inout
        position: L8

    variants:
      CH32V003F4P6:
        footprint: ~ # TSSOP20
        pinout:
          1: PD4
          2: PD5
          3: PD6
          4: PD7
          5: PA1
          6: PA2
          7: VSS
          8: PD0
          9: VDD
          10: PC0
          11: PC1
          12: PC2
          13: PC3
          14: PC4
          15: PC5
          16: PC6
          17: PC7
          18: PD1
          19: PD2
          20: PD3
        distributors:
          lcsc:
            url: https://www.lcsc.com/product-detail/C5187096.html
            partno: C5187096

      CH32V003F4U6:
        footprint: ~ # QFN20
        pinout:
          0: VSS # exposed pad?
          1: PD7
          2: PA1
          3: PA2
          4: VSS
          5: PD0
          6: VDD
          7: PC0
          8: PC1
          9: PC2
          10: PC3
          11: PC4
          12: PC5
          13: PC6
          14: PC7
          15: PD1
          16: PD2
          17: PD3
          18: PD4
          19: PD5
          20: PD6
        distributors:
          lcsc:
            url: https://www.lcsc.com/product-detail/C5299908.html
            partno: C5299908

      CH32V003A4M6:
        footprint: ~ # SOP16
        pinout:
          1: PC1
          2: PC2
          3: PC3
          4: PC4
          5: PC6
          6: PC7
          7: PD1
          8: PD4
          9: PD5
          10: PD6
          11: PD7
          12: PA1
          13: PA2
          14: VSS
          15: VDD
          16: PC0
        distributors:
          lcsc:
            url: https://www.lcsc.com/product-detail/C5346357.html
            partno: C5346357

      CH32V003J4M6:
        footprint: ~ # SOP8
        pinout:
          1: PD5 # multi-mapping: PD5, PA1
          2: VSS 
          3: PA2
          4: VDD
          5: PC1
          6: PC2
          7: PC4
          8: PD4 # multi-mapping: PD4, PD5, PD1
        distributors:
          lcsc:
            url: https://www.lcsc.com/product-detail/C5346354.html
            partno: C5346354


  DS1307+:
    description: 64 x 8, Serial, I2C Real-Time Clock

    width: 5
    pinout:
      GND:
        type: power-input
        position: B3
      VCC:
        type: power-input
        position: T2
      V_{BAT}:
        type: power-input
        position: T4
      X1:
        type: passive
        position: L4
      X2:
        type: passive
        position: L5
      SCL:
        type: open-collector
        position: L1
      SDA:
        type: open-collector
        position: L2
      SQW/OUT:
        type: logic-output
        position: R3

    variants:
      DS1307Z+:
        footprint: # 8 SO (150 mils)
        pinout:
          1: X1
          2: X2
          3: V_{BAT}
          4: GND
          5: SDA
          6: SCL
          7: SQW/OUT
          8: VCC
        distributors:
          digikey:
            url: https://www.digikey.de/de/products/detail/analog-devices-inc-maxim-integrated/DS1307Z/956882
            partno: DS1307Z+-ND

  LTC6930CMS8-8.00#PBF-ND:
    description: 8 MHz Precision µPower Oscillators

    width: 4
    pinout:
      VCC_{1}:
        type:     power-input
        position: T2
      VCC_{2}:
        type:     power-input
        position: T3
      GND_{1}:
        type:     power-input
        position: B2
      GND_{2}:
        type:     power-input
        position: B3
      DIVA:
        type:     logic-input
        position: L1
      DIVB:
        type:     logic-input
        position: L2
      DIVC:
        type:     logic-input
        position: L3
      OUT:
        type:     logic-output
        position: R2
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

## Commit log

2024-09-04 Adds first prototypical mainboard pcb
    [Mainboard.kicad_pcb, Mainboard.kicad_sch, audio.kicad_sch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]
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2024-09-06 Adds more work on the mainboard schematic
    [Mainboard.kicad_pcb, Mainboard.kicad_sch, audio.kicad_sch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]
2024-09-06 Adds RP2350 Stamp XL and dummy expansion board
    [Dummy Expansion.kicad_pcb, Dummy Expansion.kicad_sch, Mainboard.kicad_pcb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]
2024-09-09 Adds pull-ups and irq controller to expansion subsystem
    [Mainboard.kicad_pcb, expansion-port.kicad_sch, expansion.kicad_sch]
2024-09-11 More work on the motherboard
    [Mainboard.kicad_pcb, Mainboard.kicad_sch, debug.kicad_sch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]
2024-11-20 Adds case draft concept
    [Case Draft.scad]
2024-12-12 Adds new backplane design using general purpose ports, and propeller. very non-finished concept
    [#case-study.scad, Backplane.kicad_pcb, Backplane.kicad_sch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]
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2024-12-16 Adds more work on the backplane.
    [Backplane.kicad_pcb, Backplane.kicad_sch, module_slot.kicad_sch]
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2024-12-21 Updates Expansion Bay Pinout
    [module_slot.kicad_sch]
2024-12-28 Adds case experiment for creating a renderable case preview
    [visuals.scad]
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2024-12-29 Adds connector models for improved preview
    [dvi_fem_74320-1007.stl, hdmi_fem_2010418.stl, jack_3_5_fem_8051665.stl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]
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2025-01-03 Adds RaspberryPi size reference and slot variant.
    [models.scad, preview.scad, raspberrypi-model-4b.stl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]
2025-01-03 Adds really nice case update, found fitting case.
    [common.scad, models.scad, pcie_x4_10018784-10201TLF.stl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]
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2025-01-08 Starts to implement propeller propio code
    [visuals.scad]
2025-01-08 Adds User Expansion PCB
    [Pin Cluster.kicad_sch, User Expansion.kicad_pcb, User Expansion.kicad_sch]
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2025-01-22 Fixes typo in list of expansion boards.
2025-01-22 Starts work on real case design
    [#case-study.scad, 10294970.stl, DummyModule.kicad_pcb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]
2025-01-23 Creates a 3D model and rendering of the fully assembled case.
    [case.scad, exp_slot_n.scad, expansions.scad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]
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2025-01-24 Continues work on User Expansion design, adds CI for exports, ERC and DRC
    [Pin Cluster.kicad_sch, User Expansion.kicad_pcb, User Expansion.kicad_sch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]
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2025-01-26 Improves Backplane Schematic a lot
    [Backplane.kicad_pcb, Backplane.kicad_sch, Dummy Expansion.kicad_pcb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]
2025-03-07 Starts designing the mechanical prototype parts, which validate that all of the mechanical design works. They also allow electric prototyping, but only by breaking out all connectors
    [Backplane.kicad_pcb, Backplane.kicad_sch, Expansion Board.kicad_pcb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]
2025-03-07 First full draft of mechanical backplane and expansion board design
    [Backplane.kicad_pcb, Expansion Board.stl, case.scad]
2025-03-08 2025-03-08: Mechanical Prototype, Order #1
    [Expansion Board.kicad_pcb, Expansion Board.kicad_sch, Expansion Board.stl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]
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2025-04-04 Adds slider design for PCB holders
    [baseplate.scad, case.scad, parameters.scad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]
2025-06-25 Improves the PCB slider by adding a tiny chamfer and widening at the ends, so insertion of the PCB is easier. Also increased the margins as the pcb fit pretty tight.
    [case.scad, parameters.scad, pcb_slider.scad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]
2025-09-11 Starts to implement expansion card code
    [case.scad]
2025-09-14 Adds two prototype designs for expansion cards. Adjusts expansion spec a little.
    [Expansion Breakout.kicad_pcb, Expansion Breakout.kicad_sch, Quad PS2 Input.kicad_pcb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]
2025-09-28 Some work on the backplane schematics: Improves module locality
    [Backplane.kicad_sch, builtins.kicad_sch, module_slot.kicad_sch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]
2025-10-02 Starts to implement a tool to generate symbols for KiCAD from a generic description.
    [Backplane.kicad_sch, builtins.kicad_sch, module_slot.kicad_sch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]
2025-10-21 Fixes PS/2 input code for new prototype PCB, adds program.py to flash EEPROM
    [Quad PS2 Input.kicad_sch]
2025-11-20 Cleans up the backplane schematic and improves on features a lot.
    [Backplane.kicad_sch, Interconnector-B_Cu.dxf, Interconnector.kicad_pcb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]
2025-11-22 Cleans up schematic, adds clean RESET gating
    [Backplane.csv, Backplane.kicad_sch, builtins.kicad_sch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]
2025-11-26 Updates backplane: Improves voltage measurement dividers, replaces DS1307+ RTC with a much cheaper one, replaces 8 MHz global clock with 48 MHz global clock
    [Backplane.kicad_sch, backplane-bom.csv, builtins.kicad_sch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]
2025-11-27 Upgrades power-on reset system to be close to bullet-proof by having a power-good coupled mono flop that continues holding reset after PG goes high for some time
    [builtins.kicad_sch, power.kicad_sch]
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2025-12-17 Refactors clock system to use AND gates for clock tree spanning and gating.
    [Backplane.kicad_sch, builtins.kicad_sch, clock.kicad_sch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]
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2025-12-17 Some cleanups of Backplane schematic: Adds DigiKey part numbers, removes unnecessary properties, marks test points as excluded from BOM
    [Backplane.kicad_sch, builtins.kicad_sch, clock.kicad_sch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]
2025-12-17 Adds missing datasheet links into schematic
    [builtins.kicad_sch, expansions.kicad_sch, mgmt_ctrl.kicad_sch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]
2025-12-22 Adjusts to review comments
    [Backplane.kicad_sch, builtins.kicad_sch, clock.kicad_sch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]
2026-01-27 Starts refactoring Backplane to use NL17SZS11-D instead of 4-port AND
    [builtins.kicad_sch, clock.kicad_sch, clock_gate.kicad_sch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]
2026-02-14 Cleans up Backplane schematic even more. Less parts in the BOM, less mistakes!
    [Backplane.kicad_sch, builtins.kicad_sch, clock.kicad_sch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]
2026-02-14 Cleans up power connector.
    [builtins.kicad_sch, power.kicad_sch]
2026-02-14 Finally renames all modules from MOD1…7 into MOD0…6
    [expansions.kicad_sch]
2026-02-14 Cleans up schematic even more, consolidates 270 and 100 Ohm resistors into the 560 ohm resistor, as they were only used as series resistors for the mosfets and LED current limiters
    [builtins.kicad_sch, clock.kicad_sch, expansions.kicad_sch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]
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2026-02-16 Dumps all parts onto bcakplane layout.
    [Backplane.kicad_pcb]
2026-03-24 Upgrades schematic files to KiCAD 10.0
    [Backplane.kicad_sch, builtins.kicad_sch, clock.kicad_sch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]
2026-03-28 Deletes legacy mainboard schematic, adds README.md for Mainboard with concepts and ideas to implement
    [Mainboard.kicad_pcb, Mainboard.kicad_sch, audio.kicad_sch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]
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2026-05-09 Backplane: Fixes missing footprints/parts, starts to work on the layout seriously.
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2026-07-12 Fixes two issues regarding the power supply of the TCA9548APWR, routes TCA9548APWR.RESET to the main board controller.
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2026-10-21 Fixes several issues with the backplane schematic.
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2026-10-26 Updates the backplane to fit the new platform definition, replaces now deprecated RTC with a new one, improves power management.
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
